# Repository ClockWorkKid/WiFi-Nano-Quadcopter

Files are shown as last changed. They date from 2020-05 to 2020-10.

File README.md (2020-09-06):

# Firefly
Micro quadcopter project (Under Development)

The objective of this project is to build an ultra low cost quadcopter platform for swarm of drones. (Inspired by <a href="https://espcopter.com/">ESP-Copter</a>, <a href="https://www.dronaaviation.com/product/">Pluto Drone</a>, <a href="https://www.ryzerobotics.com/tello">Ryze Tello</a>)

## Table of Contents

- [Build-1](#build-1)
- [TODO List](#todo-list)

## Build-1

The first build of the nano quad uses a 
- 90mm carbon fiber quadrotor frame
- 8520 coreless brushed motors
- 55mm propellers
- 600maH 1S Lipo cell
- WeMos D1 mini module as PPM receiver <a href="https://github.com/DipanshuShukla/ESP-PPM">(ESP-PPM)</a>
- SPRACING F3 EVO brushed flight controller

The reason behind using a ESP module instead of traditional RX modules is that ESP modules are easily programmable with the Arduino IDE, and ESP supports mesh networks which might be useful for swarming. The control interface is a web socket server that can be used from a smartphone browser with touch controls or firefox browser on PC with a traditional Gamepad. 

<figure align="center">
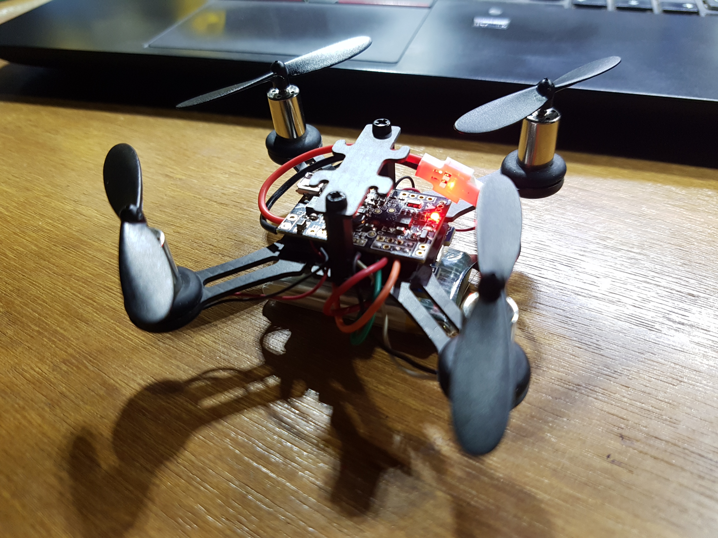
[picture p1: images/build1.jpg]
    
    <figcaption>Build 1</figcaption>
</figure>

Successful flight was achieved on September 2, 2020. For details on the build process, head on to the <a href="Build 1 - WiFi Quadcopter/README.md">Build-1 page</a>

## TODO List
- Port ESP8266 code to ESP32 (Build 1)
- Parameter Tuning (Build 1)
- Enable telemetry (Telemetry Test)
    - https://shipow.github.io/cleanflight-web/docs/telemetry.html
    - https://quadmeup.com/wifi-telemetry-for-cleanflight-with-ez-gui-and-esp8266/
    - https://diydrones.com/profiles/blogs/easy-to-use-frsky-library-for-arduino
    - https://github.com/sgofferj/arduino-frsky
    - https://ardupilot.org/copter/docs/common-frsky-telemetry.html
    - http://ceptimus.co.uk/?p=307
    - https://github.com/betaflight/betaflight/issues/6085
- Customizing Firmware
    - https://github.com/betaflight/betaflight/blob/master/docs/Customized%20Version.md
    - https://www.youtube.com/watch?v=37CP43OogQI
    - https://eecs.blog/compiling-betaflight-cleanflight-firmware-for-your-multirotor/
    - https://eecs.blog/adding-gps-back-to-cleanflight-for-f3-flight-controllers/
    - https://github.com/betaflight/betaflight/wiki/Betaflight-resource-remapping
    - https://www.reddit.com/r/Multicopter/comments/5rtcmn/adding_a_led_beeper_to_the_eachine_brushed_sp/
- Optical Flow Stabilization
    - https://robotzero.one/esp32-camera-module/
    - https://opencv-python-tutroals.readthedocs.io/en/latest/py_tutorials/py_video/py_lucas_kanade/py_lucas_kanade.html
    - https://robotics.stackexchange.com/questions/1844/stabilizing-a-quadcopter-with-optical-flow
- ESP Flight Controller 
    - https://github.com/rtlopez/esp-fc
    - https://github.com/PepeTheFroggie/EspCopter32
    - https://www.youtube.com/playlist?list=PLoPtpxJIxgnYnPrOeGHs3rdhhPgNGIYN5
- Other Tasks
    - https://dronerush.com/drone-gps-10778/
    - https://stackoverflow.com/questions/11217674/how-to-calculate-distance-from-wifi-router-using-signal-strength
    - https://www.kalmanfilter.net/background.html

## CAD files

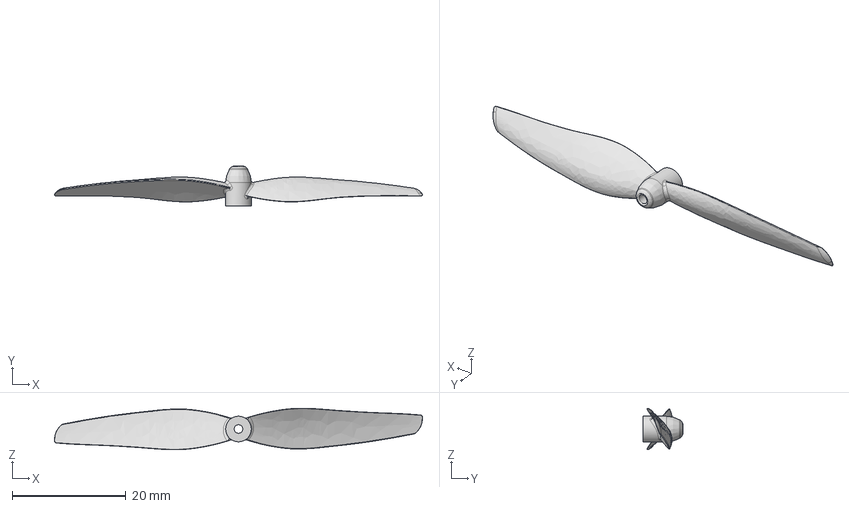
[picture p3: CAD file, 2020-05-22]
Quadcopter CAD Models/65mm-prop-1.snapshot.1/65mm Press-Fit Prop.step
64.7 x 6.95 x 7.27 mm

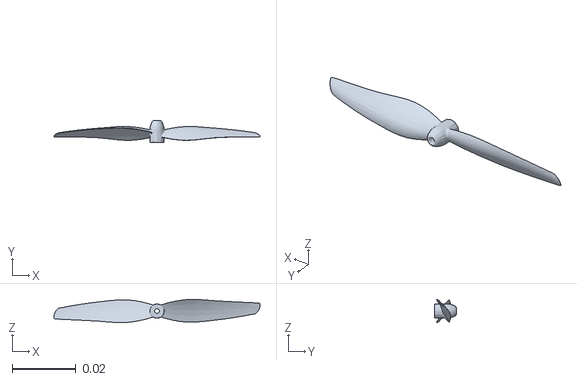
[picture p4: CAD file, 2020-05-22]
Quadcopter CAD Models/65mm-prop-1.snapshot.1/prop_CCW.URDF/meshes/prop_CCW.URDF.STL
0.0646 x 0.00695 x 0.00726

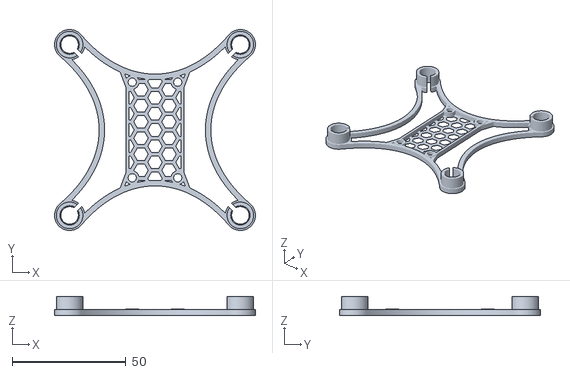
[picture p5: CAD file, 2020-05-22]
Quadcopter CAD Models/Micro_105_FPV_Quadcopter_-_8.5mm_Motors_Micro_Scisky/files/micro105-bottom-v2.stl
88.3 x 88.3 x 8.50

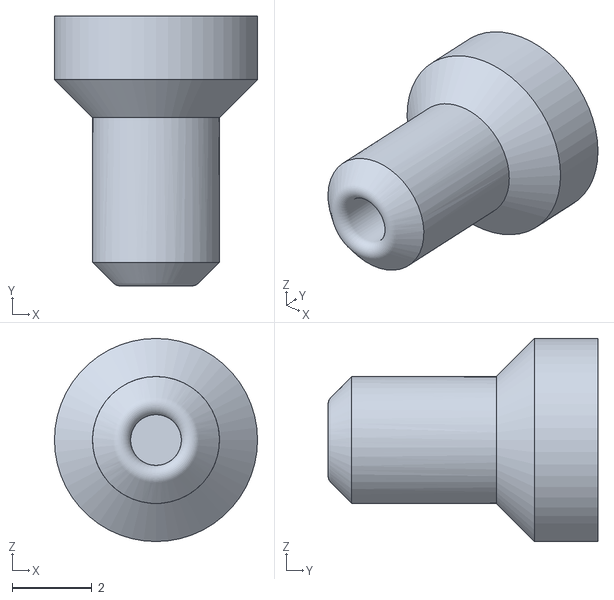
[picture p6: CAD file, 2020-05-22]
Quadcopter CAD Models/Ryze_Tello_Propellers/files/propellor_cap.STL
5.08 x 6.75 x 5.08

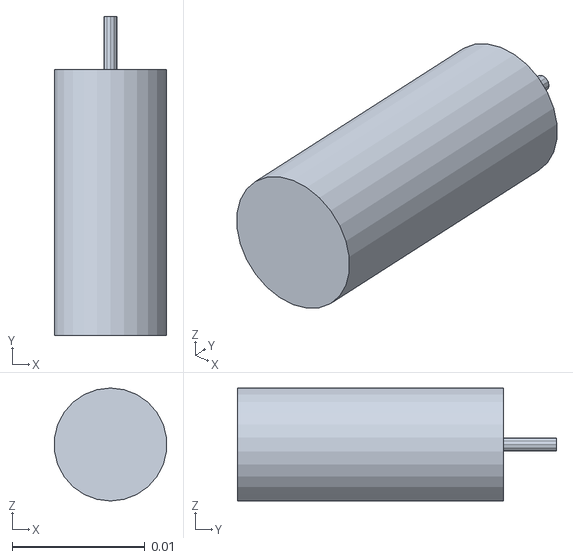
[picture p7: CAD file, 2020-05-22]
Quadcopter CAD Models/Tello-STL-Files/coreless.URDF/meshes/coreless.URDF.STL
0.00844 x 0.024 x 0.0085

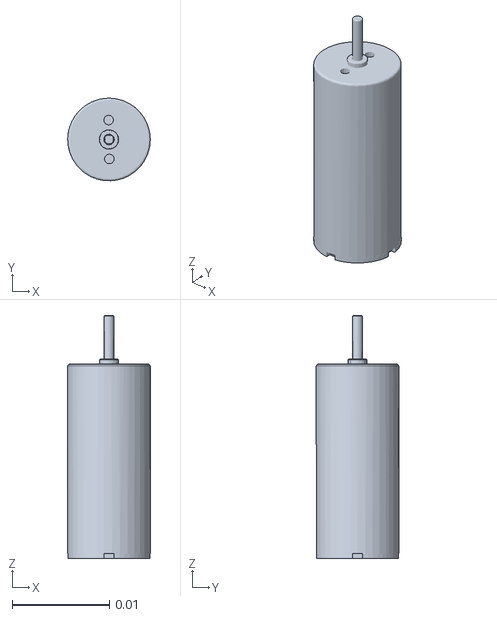
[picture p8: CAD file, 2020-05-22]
Quadcopter CAD Models/Tello-STL-Files/Coreless_Motor.URDF/meshes/Coreless_Motor.URDF.STL
0.0085 x 0.00849 x 0.025

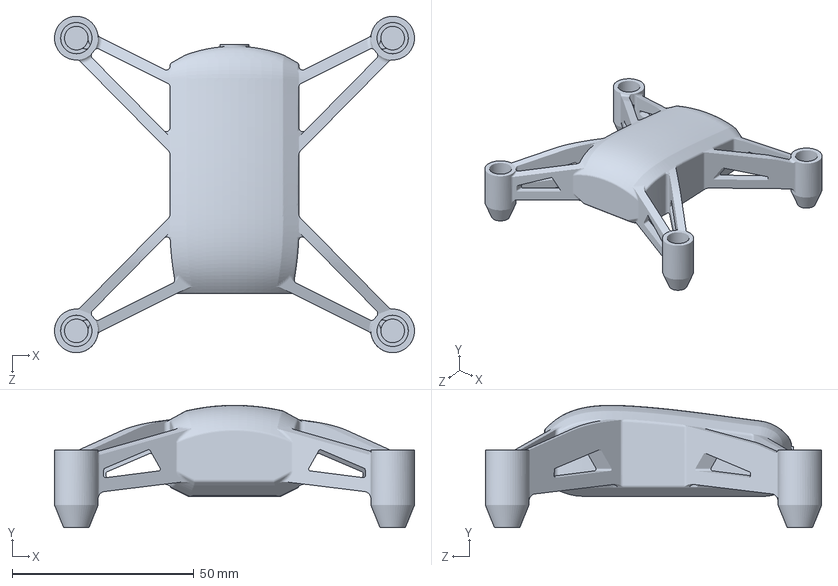
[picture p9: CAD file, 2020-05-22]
Quadcopter CAD Models/Tello-STL-Files/tello_v2.SLDPRT
99.0 x 33.6 x 92.5 mm

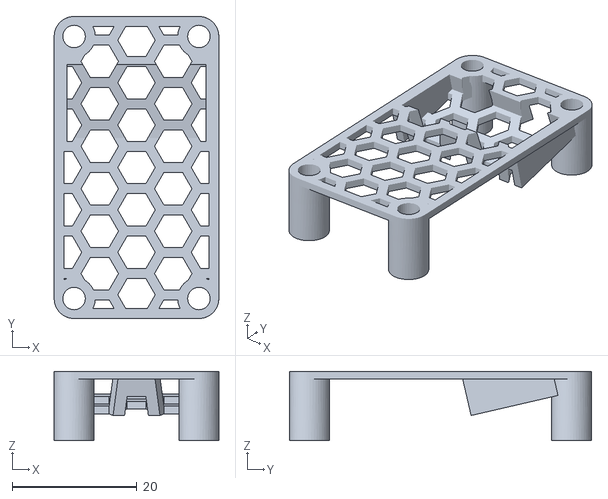
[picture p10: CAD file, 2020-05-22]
Quadcopter CAD Models/Micro_105_FPV_Quadcopter_-_8.5mm_Motors_Micro_Scisky/files/micro105-top-v4-top-camera.stl
26.4 x 48.4 x 11.1

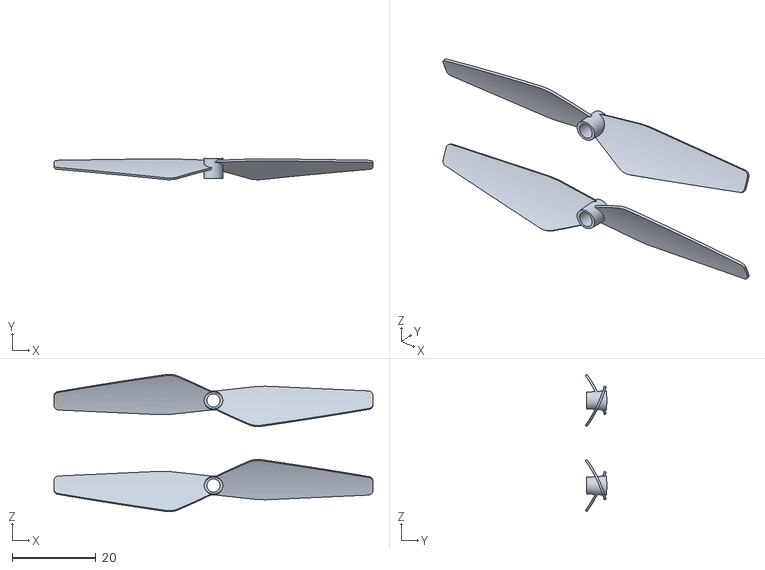
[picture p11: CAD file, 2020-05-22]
Quadcopter CAD Models/Ryze_Tello_Propellers/files/tello_propellors2.STL
76.2 x 5.16 x 32.8

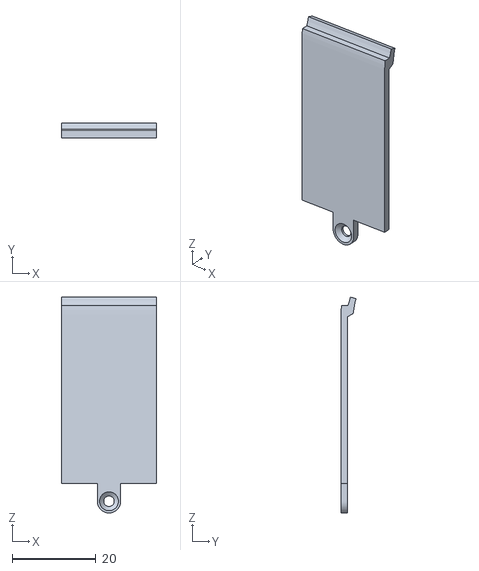
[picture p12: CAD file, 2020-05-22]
Quadcopter CAD Models/Tello-STL-Files/tello_cover.stl
22.6 x 3.59 x 51.6

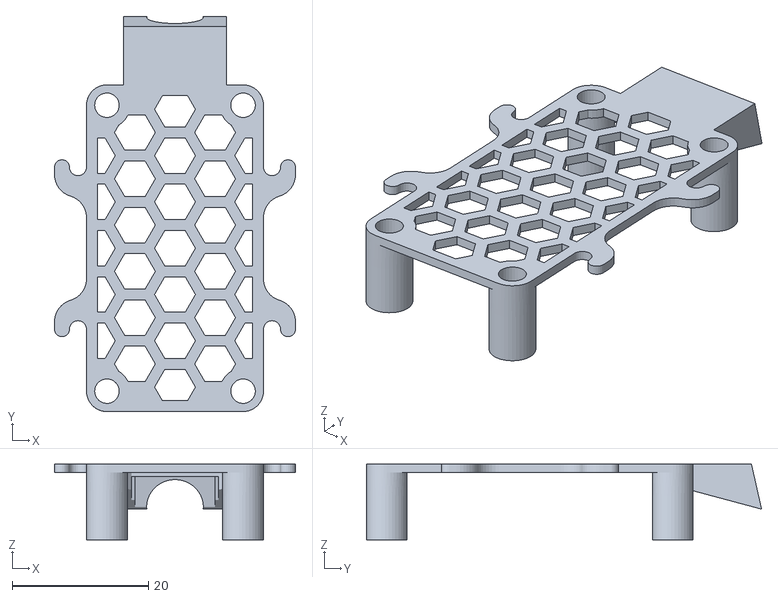
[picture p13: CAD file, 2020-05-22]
Quadcopter CAD Models/Micro_105_FPV_Quadcopter_-_8.5mm_Motors_Micro_Scisky/files/micro105-top-v2.stl
35.4 x 58.0 x 11.1

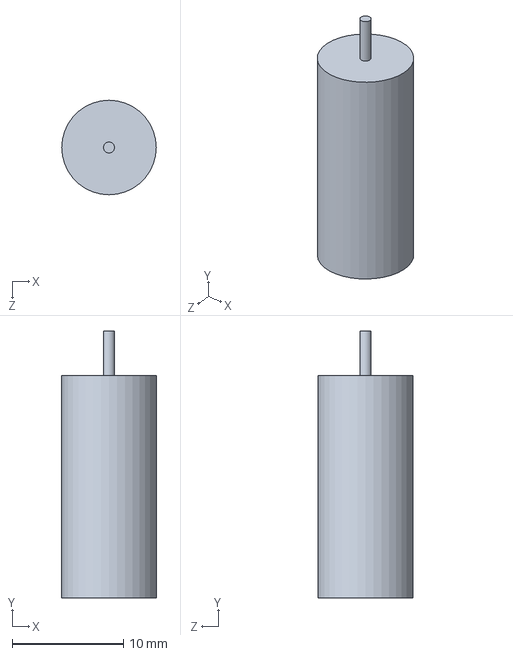
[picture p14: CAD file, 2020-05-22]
Quadcopter CAD Models/Tello-STL-Files/coreless.SLDPRT
8.50 x 24.0 x 8.50 mm

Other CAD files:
Quadcopter CAD Models/Micro_105_FPV_Quadcopter_-_8.5mm_Motors_Micro_Scisky/65mm Press-Fit Prop.SLDPRT
Quadcopter CAD Models/Tello-STL-Files/65mm cw.URDF/meshes/65mm cw.URDF.STL
Quadcopter CAD Models/Micro_105_FPV_Quadcopter_-_8.5mm_Motors_Micro_Scisky/65mm cw.SLDPRT
Quadcopter CAD Models/Tello Mesh Files/65mm cw.STL
Quadcopter CAD Models/Micro_105_FPV_Quadcopter_-_8.5mm_Motors_Micro_Scisky/files/micro105-bottom-v1.stl
Quadcopter CAD Models/Micro_105_FPV_Quadcopter_-_8.5mm_Motors_Micro_Scisky/files/micro105-bottom-v3.stl
Quadcopter CAD Models/Micro_105_FPV_Quadcopter_-_8.5mm_Motors_Micro_Scisky/files/micro105-bottom-v4-7mm-bottom-battery.stl
Quadcopter CAD Models/Micro_105_FPV_Quadcopter_-_8.5mm_Motors_Micro_Scisky/files/micro105-bottom-v4-bottom-battery.stl
Quadcopter CAD Models/Micro_105_FPV_Quadcopter_-_8.5mm_Motors_Micro_Scisky/files/micro105-top-v1.stl
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

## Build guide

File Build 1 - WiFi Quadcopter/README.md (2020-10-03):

# Firefly Build 1
Here is the detailed construction process of the first successful build of project Firefly:

## Contents

- [Materials](#materials)
- [Circuit Connections](#circuit-connections)
- [Flight Controller Configuration](#flight-controller-configuration)
- [ESP8266 Configuration](#esp8266-configuration)
- [Finalizing Setup](#finalizing-setup)

## Materials

- 90mm carbon fibre quadcopter frame (Any frame supporting **8520 motors** should work)
- 8520 Coreless motors 2 pairs (cw motor has **red+black/blue** wire, ccw motor has **white+black** wire)
- 55mm Propeller 2 pairs (Clockwise + Counterclockwise)
- F3 Evo Brushed Flight Controller (Any **brushed** flight controller should do)
- 600mAH 1S 3.7V lipo cell
- WeMos D1 mini ESP8266 WiFi Module (Any ESP8266 should work)

<figure align="center">
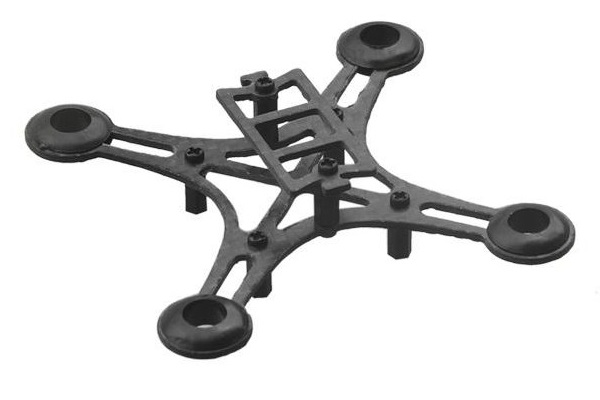
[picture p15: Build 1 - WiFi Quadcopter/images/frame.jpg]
    
    <figcaption>Frame</figcaption>
</figure>

<figure align="center">
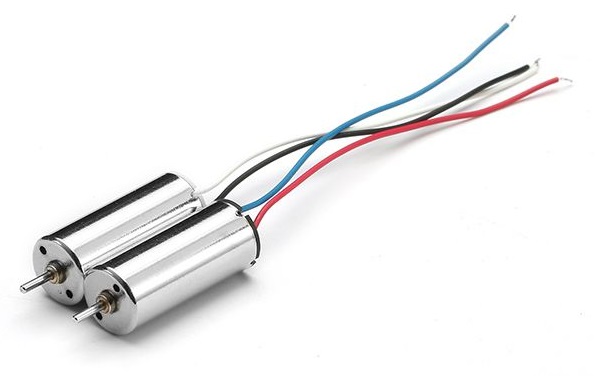
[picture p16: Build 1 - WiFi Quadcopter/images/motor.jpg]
    
    <figcaption>Motor</figcaption>
</figure>

<figure align="center">
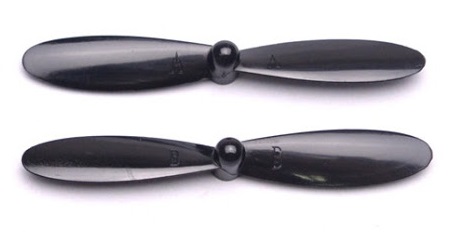
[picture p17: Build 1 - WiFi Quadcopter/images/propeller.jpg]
    
    <figcaption>Propeller</figcaption>
</figure>

<figure align="center">
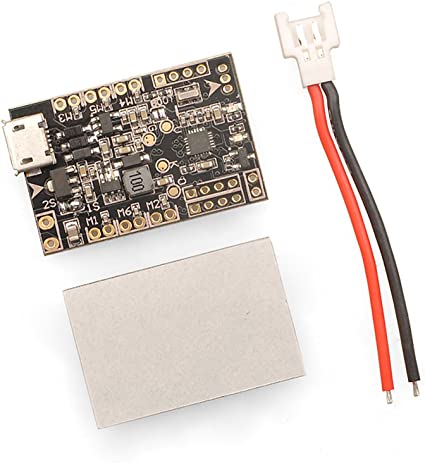
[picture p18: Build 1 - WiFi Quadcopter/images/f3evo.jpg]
    
    <figcaption>Flight Controller</figcaption>
</figure>

<figure align="center">
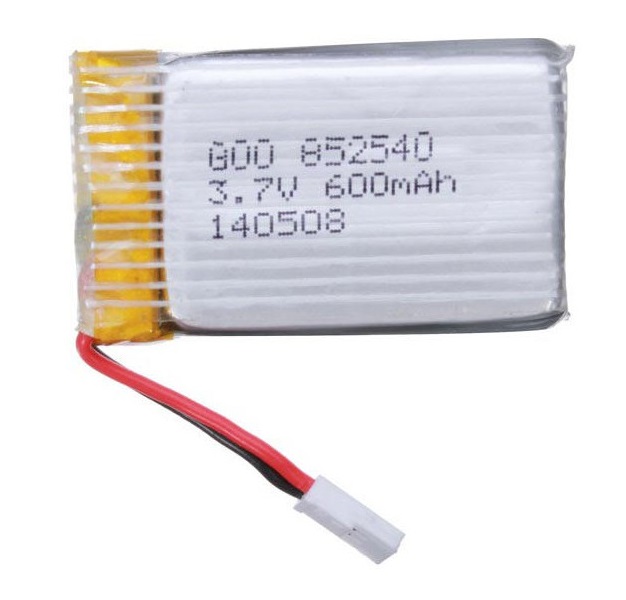
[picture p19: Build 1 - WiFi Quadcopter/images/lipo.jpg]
    
    <figcaption>Lipo Cell</figcaption>
</figure>

<figure align="center">
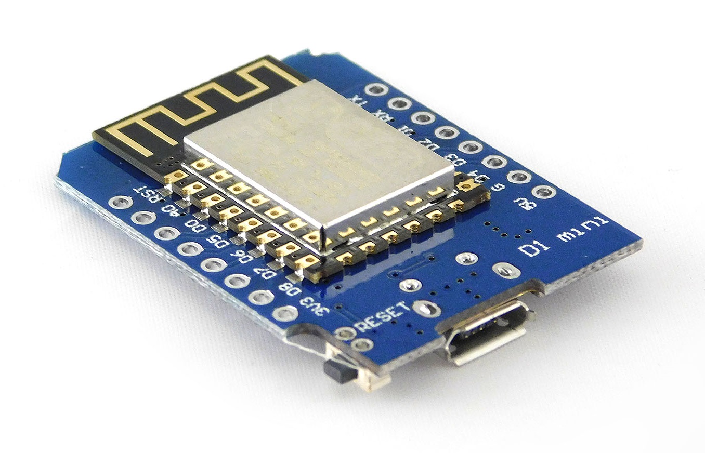
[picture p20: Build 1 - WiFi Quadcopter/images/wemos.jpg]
    
    <figcaption>Wifi Module</figcaption>
</figure>

## Circuit Connections

<figure align="center">
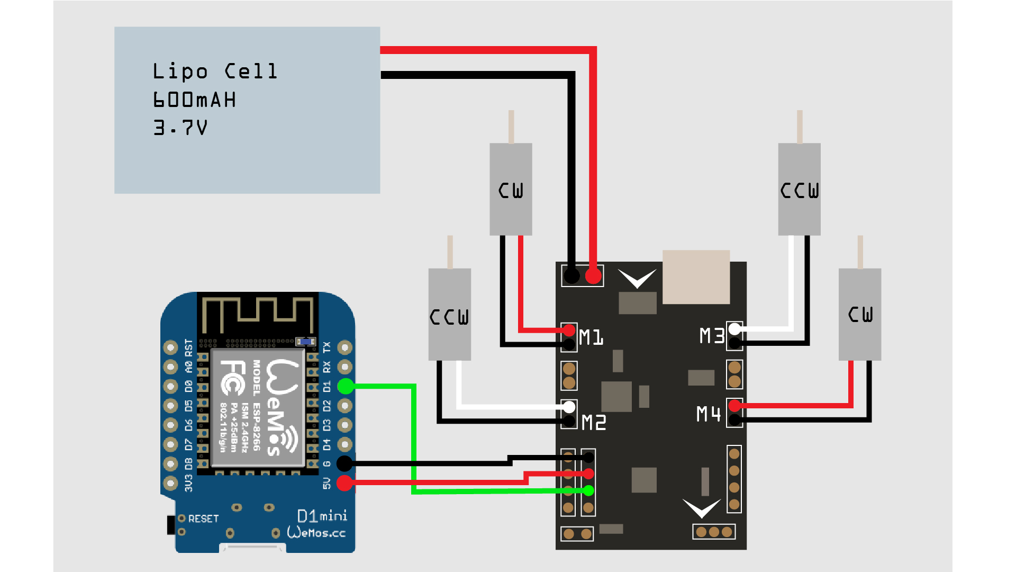
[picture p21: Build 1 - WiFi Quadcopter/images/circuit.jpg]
    
    <figcaption>Overall Circuit Diagram</figcaption>
</figure>

<figure align="center">
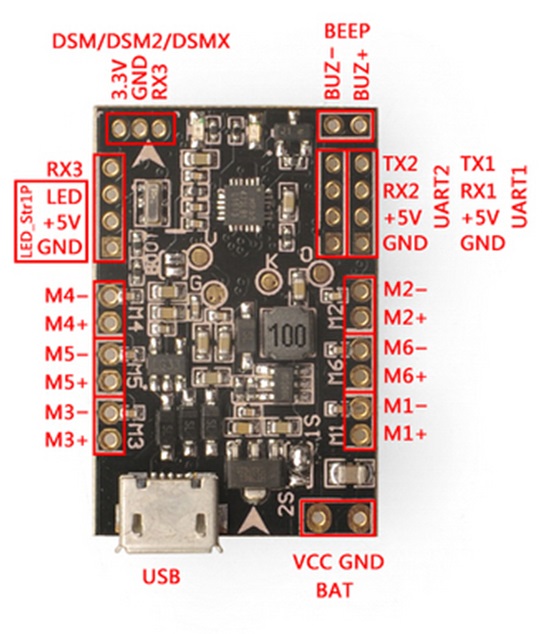
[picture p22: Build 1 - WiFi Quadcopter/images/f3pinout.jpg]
    
    <figcaption>Flight Controller pinout diagram</figcaption>
</figure>

### Step 1: Connecting Battery Connector to Flight Controller
Watch for the polarity of the battery connector cable while connecting it to the power pins of the flight controller. A reverse battery connection can fry your controller. If you are using a 1S battery, make sure the 1S jumper is soldered together as the flight controller supports both 1S and 2S power supplies in separate modes (The connection pads are near the battery connector)

<figure align="center">
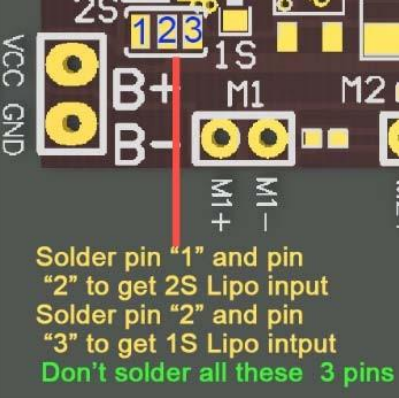
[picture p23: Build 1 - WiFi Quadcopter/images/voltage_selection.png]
    
    <figcaption>Voltage Selection Jumper</figcaption>
</figure>
<figure align="center">
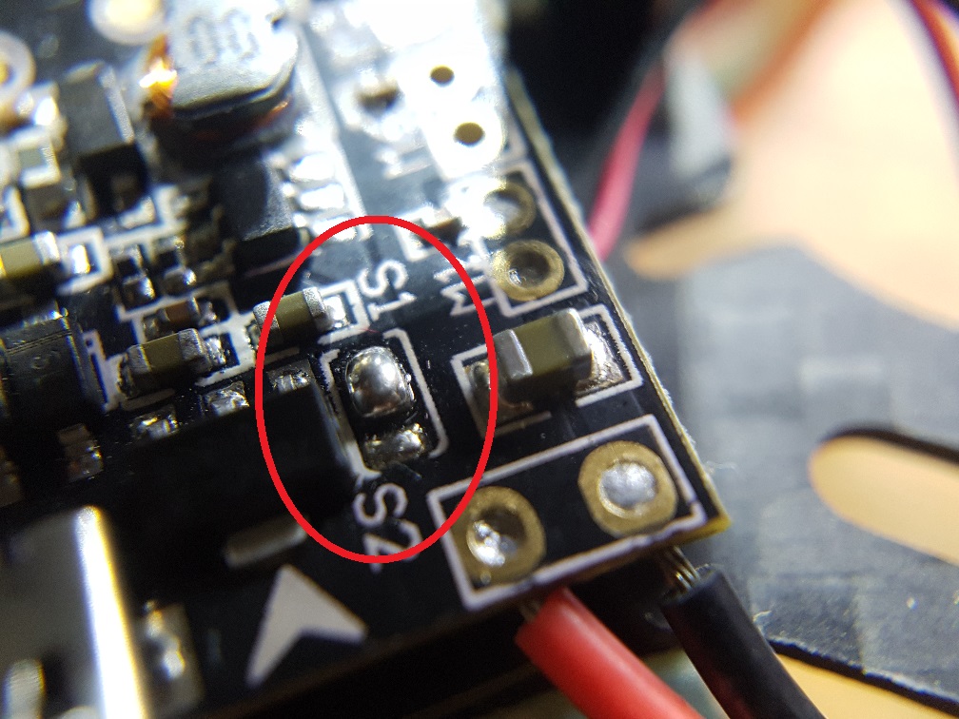
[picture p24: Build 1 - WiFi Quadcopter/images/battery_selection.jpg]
    
    <figcaption>Voltage Selection Jumper</figcaption>
</figure>

### Step 2: Connecting Motors to Flight Controller
Red+Blue or Red+Black motors are designed to rotate clockwise (along with a clockwise propeller) and White+Black motors are designed for counter-clockwise rotation. For all motors, **Black means Negative** and the other colored wire is positive. F3 Evo brushed flight controller has 6 motor connections available (4 in some variants). We will connect clockwise motors (Red+Black) on connections M1, M4 and counter-clockwise motors (White+Black) on M2, M3. Watch out for the polarity of the connections, you can find them on the pinout diagram of the flight controller.

If you happen to have four motors of the same type (clockwise), then you can just flip the connections for two of the motors to get reverse rotation, althought this is generally not recommended since these tiny brushed motors are usually coiled to efficiently run in one direction. Reversing the polarity makes the motor die out faster than expected lifetime of about 7 hours of 100 flights.

### Step 3: Connecting WeMos D1 mini to Flight Controller
F3 evo brushed flight controller has 3 UART ports, you can find the details on the <a href="https://www.unmannedtech.co.uk/uploads/6/7/0/2/6702064/f3_evo_fc_manual.pdf">user manual</a>

| Serial Port | Used For |
| --- |:---:|
| UART1 | GPS/OSD |
| UART2 | PPM/SBUS receiver input |
| UART3 | GPS/Telemetry module |

We will be using **UART2** as the ESP8266 module will be used as a PPM receiver over WiFi.

<figure align="center">
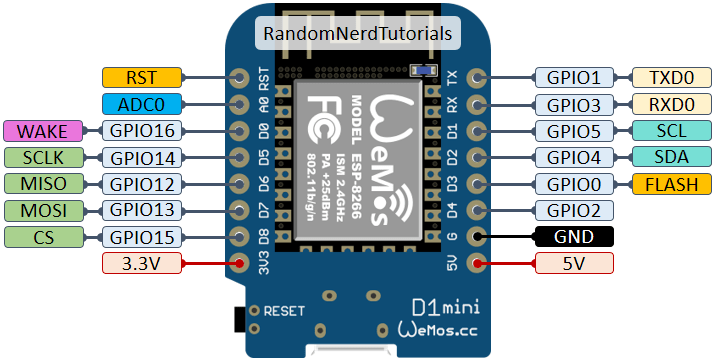
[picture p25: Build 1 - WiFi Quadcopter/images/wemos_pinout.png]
    
    <figcaption>WeMos D1 Mini Pinout</figcaption>
</figure>

The code has been configured to be using GPIO5 pin on the ESP8266 module as the PPM output, which is pin D1 on WeMos D1 mini.

| Flight Controller | ESP8266 pin | WeMos D1 Mini |
| --- |:---:|:---:|
| UART2 RX | GPIO5 | D1 |
| UART2 V+| +5V input | +5V input |
| UART2 GND | GND | GND |

In this manner, the flight controller will power the ESP8266 module when connected to USB/Battery.

### Step 4 (Optional): Connect Beeper/LED

F3EVO brushed flight controller by default does not have an on board beeper. Beepers give important feedback on voltage level, arming-disarming, in flight errors, failsafe etc. Thus you might want to consider connecting a beeper to the flight controller beeper pins. I don't like unnecessary sounds, so I connected an LED to the port instead (use blue LEDs, other colored LEDs have low forward voltage and might easily die without current limiting resistors)

<figure align="center">
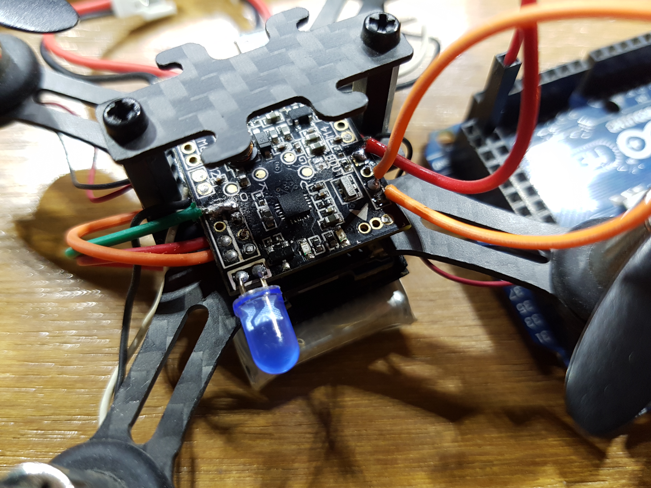
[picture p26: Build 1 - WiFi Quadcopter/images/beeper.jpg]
     <figcaption>Beeper LED</figcaption>
</figure>

## ESP8266 Configuration

### Step 1: Setting up Arduino IDE
ESP8266 module can be easily programmed from the widely used Arduino IDE.

- Download and install the latest <a href="https://www.arduino.cc/en/main/software">Arduino IDE</a>

- We will need to install dependencies for ESP8266 modules in the IDE. In the Arduino IDE, go to **Files > Preferences**. Here in the **Additional Board Manager URLs** field, paste the following line and click **ok**
    ```
    https://arduino.esp8266.com/stable/package_esp8266com_index.json
    ```
    Now go to **Tools > Board > Boards Manager**. The new boards index will load. Type ESP8266 in the search bar, and the ESP8266 library should show up. Install it. (Sometimes the url link does not work correctly, you might need to find alternate links to the library.)

    For more details, go to the <a href="https://github.com/esp8266/Arduino">ESP8266 github page</a>

### Step 2: Setting up drivers

WeMos D1 mini module uses the CH340 usb to serial driver IC for programming the onboard microcontroller unit. Windows by default does not recognize this, so you will need to install the driver from <a href="CH34x_Install_Windows_v3_4.EXE">here</a>.

After the driver has been installed, connect the ESP8266 module to the computer, and from Arduino IDE, it should be available under **Tools > Port**

### Step 3: Installing websockets library

The WiFi PPM code uses the esp websockets library.
- Download the <a href="arduinoWebSockets.zip">zip file</a>
- From a blank Arduino sketch, go to **Sketch > Include Library > Include .ZIP Library** and from there, select the downloaded zip file. The library will be imported in the IDE.

### Step 4: Uploading the Sketch

The WiFi inerface of the quadcopter uses WebSockets protocol for communicating using a browser window.

- The sketch used in this build is originally copied from another <a href="https://github.com/DipanshuShukla/ESP-PPM">github repo</a>. Download the entire <a href="ESP_PPM">sketch folder</a> and open the ESP_PPM.ino file from Arduino IDE. You should be able to upload the original sketch to the ESP Board without problem. You can modify the default WiFi AP name and password from lines 22-23

    ```
    const char *ssid = "Firefly_Test";
    const char *password = "123456789";
    ```

- After uploading, from your smartphone, you will find the hotspot on your phone WiFi. Connect to the hotspot and from smartphone browser, go to url 192.168.4.1

- The browser window will load a page with two joysticks. These are used to send control commands to the quadcopter.

- A joystick can be connected with the computer to send controls to the ESP8266 module too using firefox browser from PC.

<figure align="center">
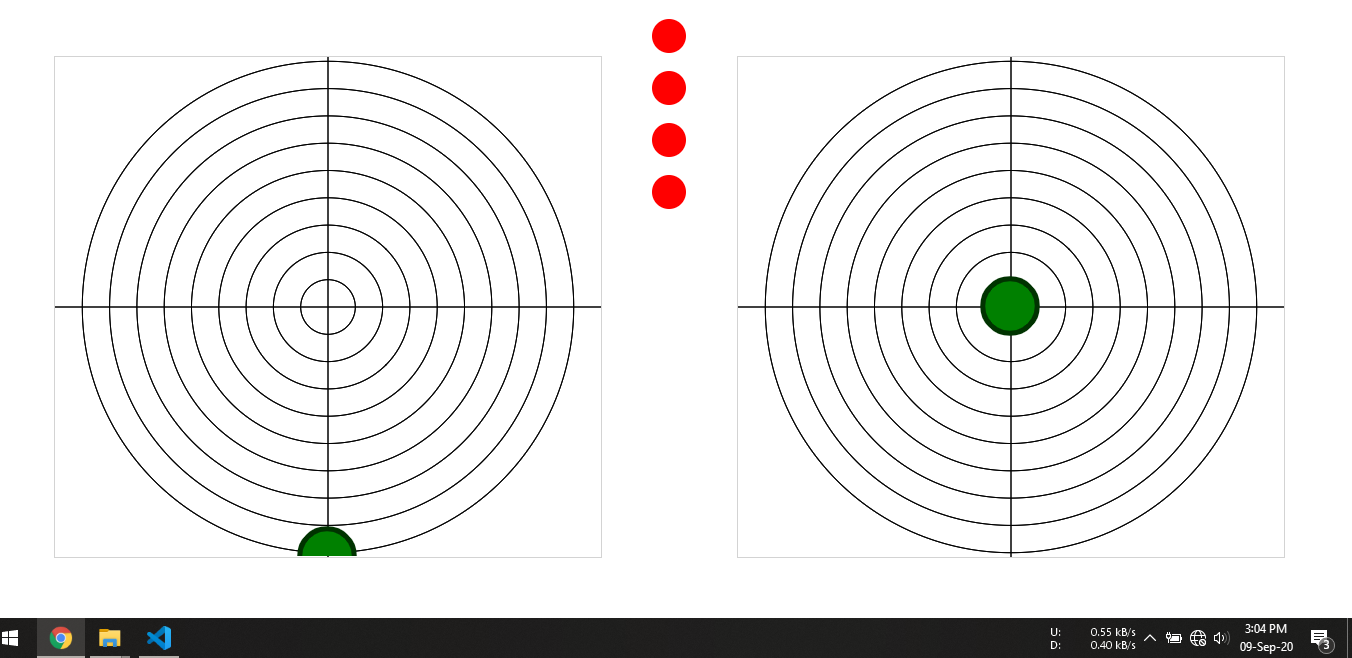
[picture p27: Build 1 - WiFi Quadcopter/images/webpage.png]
     <figcaption>Controller Browser Page</figcaption>
</figure>

## Flight Controller Configuration

<a href="https://github.com/betaflight/betaflight">Betaflight</a> and <a href="https://github.com/cleanflight/cleanflight">Cleanflight</a> are the two most widely used flight controller firmware and configurators in the realm of RC quads and racing drones. Betaflight is more used these days, althought the two are really similar (Betaflight originally came from cleanflight). I have tested both of them on the model, and ran into a few issues with betaflight. So in this build I will be using only Cleanflight for configuring the micro quad. (The processes explained here should be similar for betaflight too)

### Step 1: Cleanflight Chrome App

Cleanflight runs as an application run from Chrome browser. Google Cleanflight Chrome App and it should take you to the installation page. Add the extension and you should be done. The configurator can be launched from chrome apps.

<figure align="center">
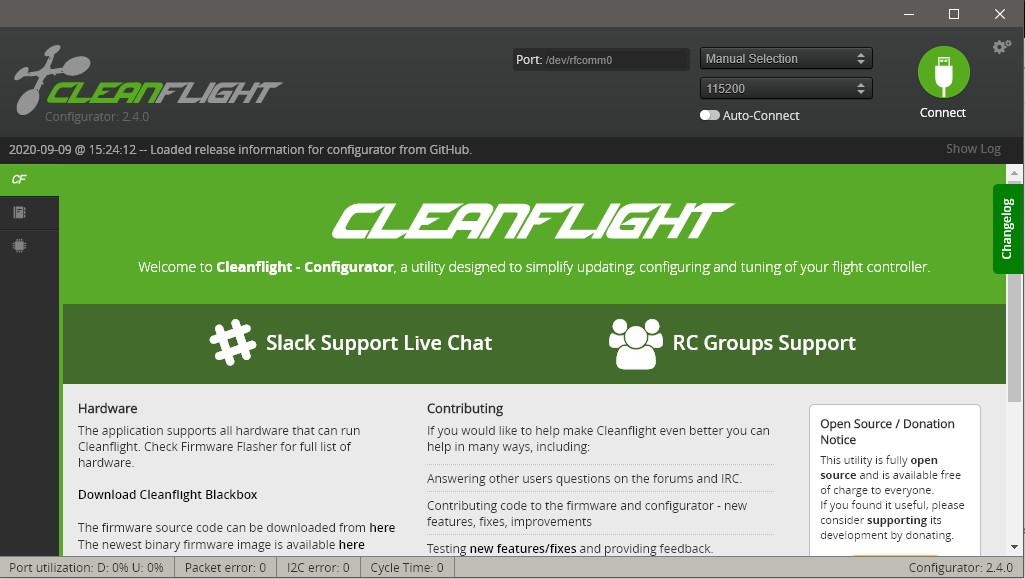
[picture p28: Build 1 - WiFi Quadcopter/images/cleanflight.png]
     <figcaption>Cleanflight Start Page</figcaption>
</figure>

### Step 2: Install Flight Controller Driver with Zadig

- The brushed controller used in this build has an STM32F3 chip which has a built in port for connecting to USB for firmware flashing. However on Windows machine, a virtual port driver has to be installed for accessing this. Download the <a href="zadig-2.4.exe">Zadig</a> tool.

- To install the bootloader, the Flight Controller board needs to be in Boot mode. Most flight controller boards have a boot button that can be held while connecting to PC, but F3EVO brushed controller has the boot pads open on the board. Do not solder the boot pads together for boot mode, because if you do so, you will need to frequently solder and desolder the pads for changing Flight controller firmware.

    Use something metallic to touch the two boot pads together, and connect the board to PC. If the contact was okay, you should see that only the RED indicator LED is glowing, meaning that the board is in bootloader mode
    <figure align="center">
         <figcaption>Bootloader Mode</figcaption>
    </figure>
    If the blue LED is also flashing, then the board is in configuration mode - disconnect it and try the process again.
    <figure align="center">
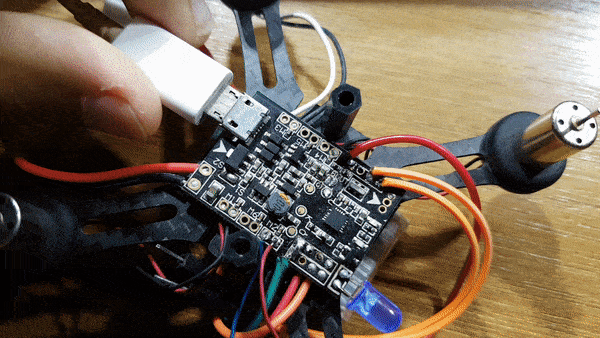
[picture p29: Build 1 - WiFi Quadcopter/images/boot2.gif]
         <figcaption>Configuration Mode</figcaption>
    </figure>

- With the board in bootloader mode, open Zadig, choose **Options > List All Devices**
    <figure align="center">
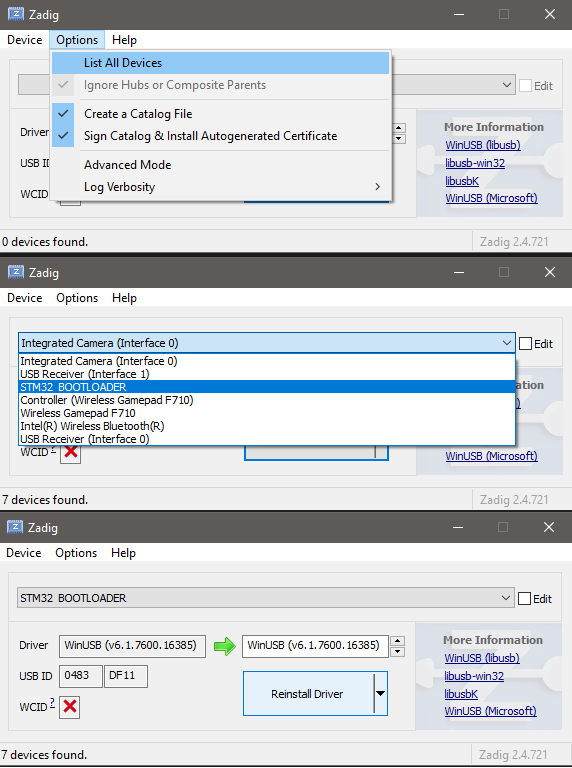
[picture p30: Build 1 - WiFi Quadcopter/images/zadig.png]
         <figcaption>Zadig Driver</figcaption>
    </figure>
- Select STM32 Bootloader, WinUSB. Click **replace driver** or **install driver**. It should be done.

### Step 3: Flash Cleanflight Firmware

- Open Cleanflight configurator from Chrome apps, connect the Flight Controller Board in the bootloader mode. When you connect the board, you should see the device is available as **DFU**. Do not try to connect from here.
    <figure align="center">
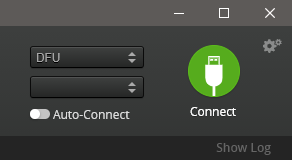
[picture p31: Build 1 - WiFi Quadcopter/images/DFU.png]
         <figcaption>DFU Mode</figcaption>
    </figure>

- Go to the firmware flasher tab. The configurator should automatically detect your board. If it doesnt, manually select the board and firmware. At the time of writing, CLFL 2.5.0 was used as flight controller firmware. After that, click on **Load Firmware(Online)** and a hex file will be downloaded. After that, click **Flash Firmware**, it might take some time to flash.
    <figure align="center">
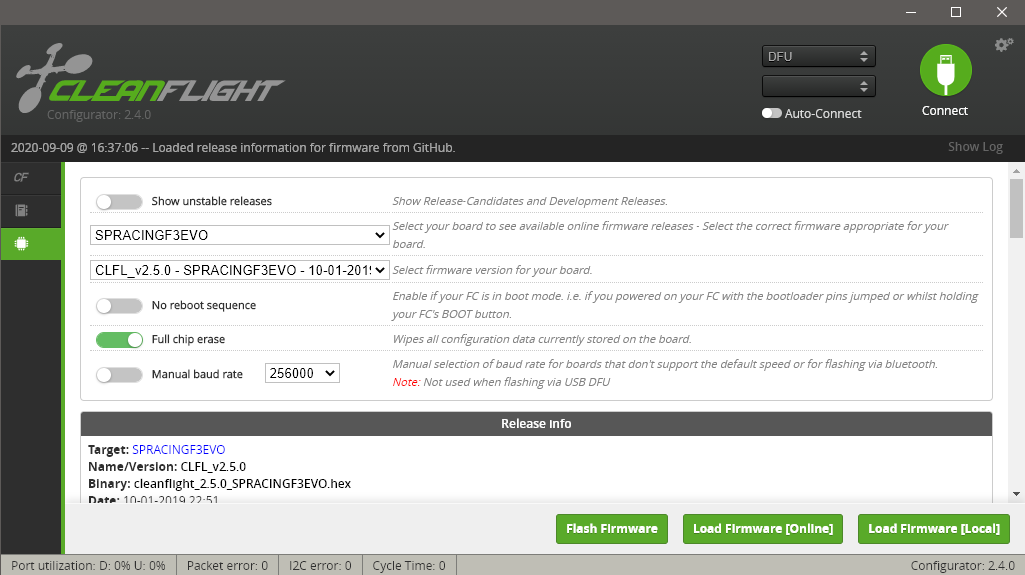
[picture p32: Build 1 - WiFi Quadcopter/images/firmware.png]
         <figcaption>DFU Mode</figcaption>
    </figure>

After flashing, the configurator will go to the start page, and a serial port will be available for connecting. You can click on connect to start configurating the flight controller now.
    <figure align="center">
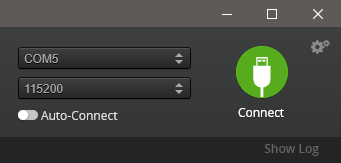
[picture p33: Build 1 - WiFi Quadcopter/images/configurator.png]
         <figcaption>Configurator Mode</figcaption>
    </figure>

If the steps did not make sense, you can watch <a href="https://www.youtube.com/watch?v=Krv-CMSfb_M">this video on flashing using betaflight</a>

## Finalizing Setup

## References
- <a href="https://www.instructables.com/id/Build-a-WiFi-Enabled-Micro-quadrotor/">WiFi enabled micro quadrotor</a>
- <a href="https://www.instructables.com/id/Long-Range-Wifi-PPM-MSP/">Long Range WiFi PPM instructables</a>
- <a href="https://community.micro-motor-warehouse.com/t/banggood-eachine-sp-racing-f3-evo-based-brushed-fc-set-up-guide-for-spektrum-sat-receivers/2574">F3 Evo setup guide</a>
- <a href="https://blog.dronetrest.com/setting-up-flight-modes-in-cleanflight-betaflight/">Betaflight flight modes</a>

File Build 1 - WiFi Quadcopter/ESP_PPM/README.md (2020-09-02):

# IoT based ESP wifi PPM reciever for Drones(and other applications)

## Overview

IOT based project for ESP8266 module to be used as an ppm reciever (no controller app needed) for a drone flight controller.

The ESP*12E ESP8266 WiFi Module is a self contained SOC with integrated TCP/IP protocol stack that can give any microcontroller access to your WiFi network. The ESP8266 is capable of either hosting an application or offloading all Wi*Fi networking functions from another application processor.

This gives us an advantage of not needing an external application to send and recieve commands. The program starts a wifi access point with a HTML 5 website to control the PPM signal. The PPM signal is generated by interrupt.

Thanks to HTML5 you can control your RC device with any smart phone without any app. You can also connect to the website with a PC and use a joystick for controlling. At the moment this works only in Firefox.

## Getting Started

These instructions will get you a copy of the project up and running on your ESP8266  for development and testing purposes.

### Part List

* ESP8266: Any module should work. I used the ESP-12E module.

* a 3,3V USB to Serial converter for uploading the scetch the first time. (I used a NodeMCU Amica board).

* a 3,3V voltage regulator: The ESP8266 needs 3,3V. Any voltage above 3,6V will kill the device. It can also drop about 200mA peak current. If you don´t have a strong enough 3,3V supply at your RC model you need an additional voltage regulator.

* a PC with Arduino IDE

* ESP8266 support for Arduino IDE. Follow [these instructions](https://learn.sparkfun.com/tutorials/esp8266-thing-hookup-guide/installing-the-esp8266-arduino-addon).

* Websocket library for Arduino: https://github.com/Links2004/arduinoWebSockets

* Maybe a 3,3V/5V level shifter if your PPM decoder doesn´t support 3,3V inputs. For most Drone flight controllers you don´t need this.

* The WifiPPM scetch: Download file 

* A smart phone or a PC with a joystick and Firefox

### Setting up the Electronics and uploading the Code

<p align="center">
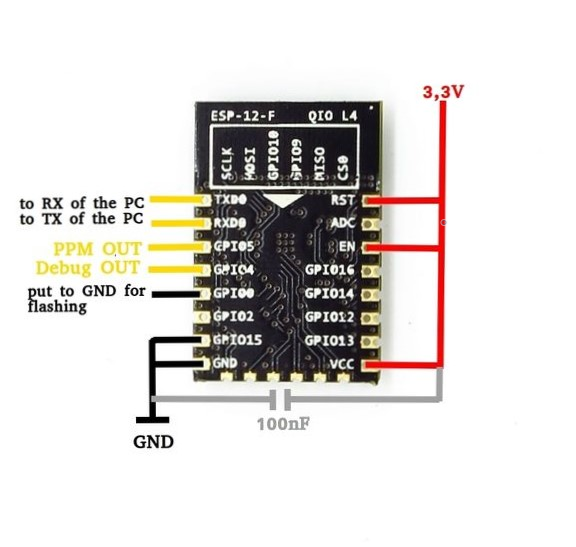
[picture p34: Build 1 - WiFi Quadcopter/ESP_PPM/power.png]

</p>

1. First you need to set the power connections to the ESP8266 module. You can see the wiring in the picture. Make the following connections:

	* RST, EN and VCC to 3,3V

	* GPIO15 and GND to GND

	* Put a small capacitor between VCC and GND (about 100 nF)

	* TXD to RXD of your USB2Serial device

	* RXD to TXD of your USB2Serial device

	* Put GPIO0 to GND while powerup to enter the flash mode.

2. After you have installed the Arduino IDE, the ESP8266 support and the websocket library open the sketch. Hold GIO0 to GND while powering up the ESP8266 to enter the flash mode. Now you can upload the sketch.

3. After you have uploaded the sketch, the controller will reset. You should find a WIFI Access Point named WifiPPM. If this is OK you can power down the chip and disconnect the TXD, RXD and GPIO0 wires. In the future you can update the program over OTA. To do so connect to the Access Point and go to "192.168.1.4/update" in your web browser.

```diff
- NOTE: YOU MAY WANT TO CHANGE THE ACCESS POINT NAME AND PASSWORD IN THE CODE BEFORE UPLOADING THE SKETCH.
```

### Connecting to the Website

Now you can connect GPIO5 to the PPM input of your flight controller or whatever you use to decode the PPM signal.

  * After powering up the module you can connect to the Access Point "WifiPPM". There is no password. Open the address 192.168.4.1 in your browser.

  * You will see the site of the first picture. On a touch device you can control the sticks with your touch screen.

  * If you open the site with a PC you must use Firefox. As soon as you connect a joystick, the site will change to the one you can see at the second picture. You can control the sticks with your joystick.

### Setting Up Betaflight

I use the WifiPPM controller for my quadcopter with Betaflight. I explain now how to set it up.

  * Connect your flight controller to the PC

  * open Betaflight

  * connect to the flight controller

  * go to Receiver tab

  * type RTAE1234 into the channel map field

  * change the "Stick Low Threshold" to 1020, the "Stick Center" to 1500 and the "Stick High Threshold" to 1980

  * save the changes

  * open the wifiPPM website with your mobile phone and test if the adjustment is OK

Thats it. You are done. Now you can fly with your mobile phone without any additional app.

## Authors

* **Dipanshu Shukla** - *Initial work* - [Github page](https://github.com/DipanshuShukla)

## License

This project is licensed under the MIT License - see the [LICENSE.md](https://github.com/DipanshuShukla/ESP-PPM/blob/master/LICENSE) file for details

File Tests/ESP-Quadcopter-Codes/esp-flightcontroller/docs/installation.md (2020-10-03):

# Installation instruction

The best way to flash your device is to install Atom IDE with platformio extension.

1. Install Atom IDE https://atom.io/
2. Install PlatformIO extension http://docs.platformio.org/en/latest/ide/atom.html#installation
3. Install GIT client (optional) https://git-scm.com/download/win
4. Clone or download repository into projects folder with command `git clone https://github.com/rtlopez/esp-fc.git`
5. Open project in Atom IDE
6. To build binary file press F7 and pick option 'PIO Build(d1_mini).
7. To upload, connect device first, then press F7 and choose 'PIO Upload(d1_mini)' http://docs.platformio.org/en/latest/ide/atom.html#building-uploading-targets

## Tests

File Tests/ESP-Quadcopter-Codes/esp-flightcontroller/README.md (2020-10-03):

# ESP-FC Flight Controller
The mini, DIY, ~$5 cost, ESP8266 based, high performance flight controller.

## Features
* Frames (Quad X)
* Betaflight contiguration tool compatible
* Receiver protocol (8 channel PPM)
* ESC protocols (PWM, Oneshot125, Oneshot42, Multishot, Brushed, Dshot150, Dshot300, Dshot600)
* Configurable Gyro Filters (LPF, Notch, dTerm)
* Blackbox recording (OpenLog serial)
* In flight PID Tuning
* Flight modes (ACRO, ANGLE, AIRMODE, ARM)
* Up to 2kHz gyro/loop in acro, 1kHz with accelerometer (level)
* MSP protocol interface
* Cli interface
* Resorce mapping
* Buzzer
* Lipo voltage monitor
* Failsafe

## Requirements
Hardware:
* Wemos D1 Mini board (D1 Mini Lite too, ESP-12 for experienced users)
* MPU6050 I2C gyro (GY-88, GY-91, GY-521 or similar)
* PDB with 5V BEC
* Buzzer and some electronic components (optionally).

Software:
* [Betaflight Configurator](https://github.com/betaflight/betaflight-configurator/releases) (v10.7)
* [CH340 usb-serial converter driver](https://sparks.gogo.co.nz/ch340.html)
* [Espressif Flash Download Tools](https://www.espressif.com/en/support/download/other-tools)

## Flashing
**Windows:** download and unzip [Espressif Flash Download Tools](https://www.espressif.com/en/support/download/other-tools)

ESP-FC Flashing

## Configuration
The rule of thumb is if you cannot change specific option in Betaflight Configurator, that means it is not supported.

## Wiring diagram
ESP-FC Wemos D1 mini wiring diagram

## Issues
You can report issues using Github [tracker](https://github.com/rtlopez/esp-fc/issues)

## Development
* Visual Studio Code
* [PlatformIO](https://platformio.org/install/ide?install=vscode)
* Git

## Todo
* Update documentation
* Mixers: Quad+, Bicopter, Tricopter, Helicopter, Custom and more
* Balancing robot
* Serial Rx (SBUS, IBUS)
* Baro (MS5611, BMP280)
* Magnetometer (HMC5883, AK8963)
* GPS navigation
* ESP32 board
* ESP32 SPI Gyro (MPU9250)

## Licence
This project is distributed under MIT Licence. Bear in mind that:

THE SOFTWARE IS PROVIDED "AS IS", WITHOUT WARRANTY OF ANY KIND, EXPRESS OR
IMPLIED, INCLUDING BUT NOT LIMITED TO THE WARRANTIES OF MERCHANTABILITY,
FITNESS FOR A PARTICULAR PURPOSE AND NONINFRINGEMENT. IN NO EVENT SHALL THE
AUTHORS OR COPYRIGHT HOLDERS BE LIABLE FOR ANY CLAIM, DAMAGES OR OTHER
LIABILITY, WHETHER IN AN ACTION OF CONTRACT, TORT OR OTHERWISE, ARISING FROM,
OUT OF OR IN CONNECTION WITH THE SOFTWARE OR THE USE OR OTHER DEALINGS IN THE
SOFTWARE.

## Donations
If you like this project and you want it to be still developed, you can support me a little.

* BTC: 1Lopez7yPtbyjfLGe892JfheDFJMMt43tW
* LTC: LV3G3sJxz9AYpDMYUp8e1LCmerFYxVY3ak

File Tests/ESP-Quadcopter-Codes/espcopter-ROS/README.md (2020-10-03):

# A ROS package to communicate espcopters using wifi.

This repo contains the firmware of ESPcopter that enables this drone to communicate with ROS.

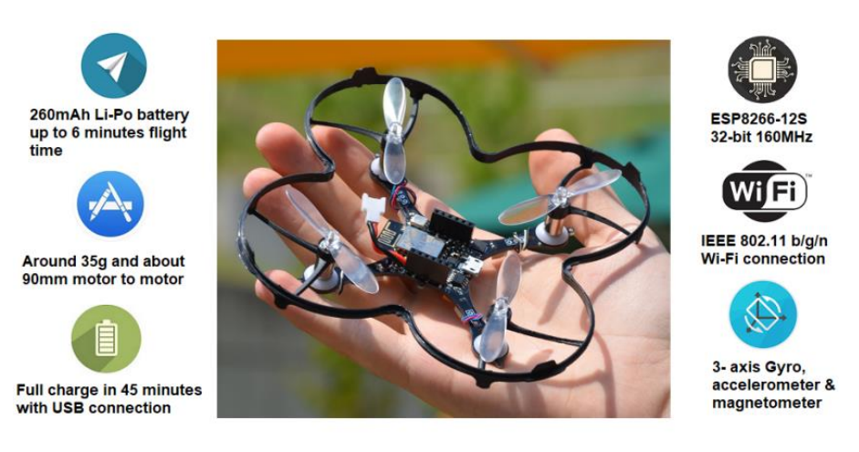
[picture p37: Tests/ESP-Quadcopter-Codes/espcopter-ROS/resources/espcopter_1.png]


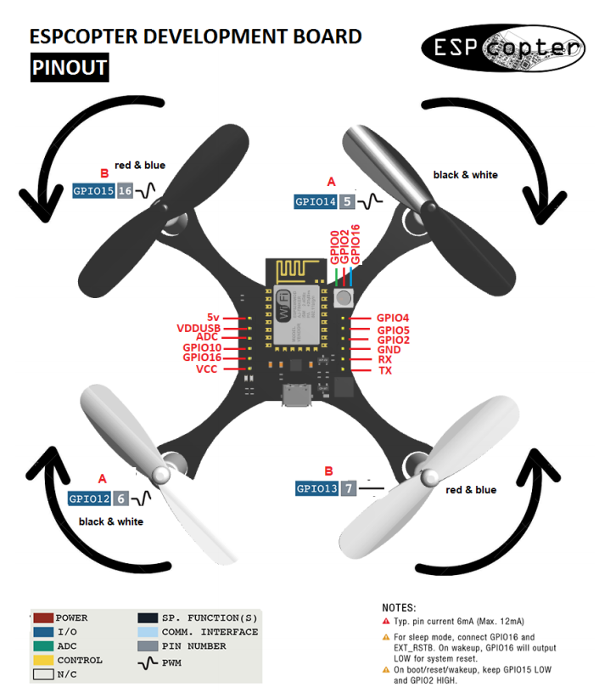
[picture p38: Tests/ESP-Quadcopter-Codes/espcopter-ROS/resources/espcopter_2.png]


## Available Features
This driver enables you to communicate espcopters with ros using wifi.
The available topics are:

```sh
$ rostopic list 
/drone_1/attitude # set the attitude of the drone controlling via PID.
/drone_1/attitude_status # get the current attitude of the drone.
/drone_1/battery # Battery voltage status.
/drone_1/command_status # get the current command sent to the drone.
/drone_1/imu # Gyro and accelerometer data.
/drone_1/led # Control the RGB led on the drone.
/drone_1/mag # Magnetometer data.
/drone_1/motors # Control each motor individually.
```

Also we provide some services that allow the user calibrate the drone:

```sh
$ rosservice list
/drone_1/arm_motors # arm/disarm the drone motors (toggle). 
/drone_1/gyro_calibration # start gyro calibration process.
/drone_1/mag_calibration # start magnetometer calibration process.
```

## How to build this firmare and install it on your ESPcopter
### Arduino Installation
- Install the latest version from the [Arduino website](https://www.arduino.cc/en/Main/Software).
- The following driver is reqired for the espcopter to be recognized by the computer. Download
and install the approperate [driver version](https://www.silabs.com/products/development-tools/software/usb-to-uart-bridge-vcp-drivers) for your OS.

### ESP8266 Library
- One need to update the board manager with a custom URL to enable Arduino compile esp8266 mpu. Open up Arduino,
then go to the Preferences (File > Preferences). Then, towards the bottom of the window, copy
this URL into the “Additional Board Manager URLs” text box:
```
http://arduino.esp8266.com/stable/package_esp8266com_index.json
```
- Hit OK. Then navigate to the Board Manager by going to (Tools > Boards > Boards Manager). There
should be a couple new entries in addition to the standard Arduino boards. Look for esp8266.
Click on that entry, then select Install. You need to install 2.5.0 version of esp8266 library. 

- The download process can take up to 10 minutes depending on your internet speed. After the
download is done, select NodeMCU 1.0 from the Tools tab and follow the other settings.

### Downloading the ESPcopter library:
- Access your ros workspace and clone this repo:
```sh
$ cd catkin_ws/src
$ git clone https://github.com/verlab/espcopter.git
$ cd ..
$ catkin_make # or catkin build
```
- Fixing dependecies:
```sh
$ rosdep install espcopter
```

- Open the **espcopter.ino** file using arduino ide and connect the ESPCopter with the computer using a micro USB cable. 
- Setup your WiFi network in the code:
```c++
/*********************************************************
   WIFI SETUP
*********************************************************/
IPAddress ROS_MASTER_ADDRESS(10, 42, 0, 1); // ros master ip
char* WIFI_SSID = "hero_network"; // network name
char* WIFI_PASSWD = "s3cr3tp4ss"; // network password
/*********************************************************/
```
- Check if the switch on the drone is ON position, and compile and burn the code into esp8266.

## How to connect the drone with ROS
- Open a terminal and run the roslaunch to bringup the drones:
```sh
$ roslaunch espcopter espcopter_bringup.launch
waiting for socket connection
[INFO] [1579104505.608789]: Established a socket connection from 10.42.0.127 on port 49154
[INFO] [1579104505.609296]: calling startSerialClient
[INFO] [1579104507.713159]: Requesting topics...
[INFO] [1579104507.761302]: Note: publish buffer size is 1024 bytes
[INFO] [1579104507.761692]: Setup publisher on /drone_1/battery [mavros_msgs/BatteryStatus]
[INFO] [1579104507.767787]: Setup publisher on /drone_1/imu [sensor_msgs/Imu]
[INFO] [1579104507.771223]: Setup publisher on /drone_1/mag [sensor_msgs/MagneticField]
[INFO] [1579104507.774226]: Setup publisher on /drone_1/attitude_status [mavros_msgs/AttitudeTarget]
[INFO] [1579104507.778017]: Setup publisher on /drone_1/command_status [mavros_msgs/AttitudeTarget]
[INFO] [1579104507.782331]: Setup service server on /drone_1/arm_motors [std_srvs/Trigger]
[INFO] [1579104507.785847]: Setup service server on /drone_1/gyro_calibration [std_srvs/Trigger]
[INFO] [1579104507.789240]: Setup service server on /drone_1/mag_calibration [std_srvs/Trigger]
[INFO] [1579104507.790900]: Note: subscribe buffer size is 1024 bytes
[INFO] [1579104507.797960]: Setup subscriber on /drone_1/led [std_msgs/ColorRGBA]
[INFO] [1579104507.802273]: Setup subscriber on /drone_1/motors [mavros_msgs/RCOut]
[INFO] [1579104507.806879]: Setup subscriber on /drone_1/attitude [mavros_msgs/AttitudeTarget]
[INFO] [1579104510.619883]: [/drone_1] Conected at time: 18709, loop_freq: 15289.000000, battery: 4246.000000
[INFO] [1579104515.617136]: [/drone_1] Conected at time: 23710, loop_freq: 15096.000000, battery: 4240.500000
[INFO] [1579104520.604998]: [/drone_1] Conected at time: 28711, loop_freq: 15520.000000, battery: 4240.500000

```

## How to teleoperate the drone using joystick
- A demo **teleop.py** script should be modified as you like to fit the control as your joystick.
- Open a terminal and run the roslaunch to teleoperate the drone:
```sh
$ roslaunch espcopter espcopter_teleop.launch
```
- Video Demo:

IMAGE ALT TEXT HERE (https://www.youtube.com/watch?v=mjpYxwDCcIA)

## How to calibrate the gyro
- To calibrate the gyro, place the drone in a flat surface and **DO NOT** move it.
- On a terminal and call the service:
```sh
$ rosservice call /drone_1/gyro_calibration "{}"
```
- Wait until the process is done. This process should be done at least once per drone at first time of fly.

## How to calibrate the magnetometer
- To calibrate the magnetometer, place the drone in a **flat surface**.
- On a terminal and call the service:
```sh
$ rosservice call /drone_1/mag_calibration "{}"
```
- Read the output of the drone bringup launch, start **turn the drone c.w. three times**.
- After turn the drone, put your finger on top of the drone (**becarefully**) and wait for the rest of the process.
- **The motors should turn on really quick (less than 1 second) the propelles and turn off**.
- This is for compensation of the magnetic field generated by the motors.
- Wait for the rest of the process.

- Video Demo:

IMAGE ALT TEXT HERE (https://www.youtube.com/watch?v=AO48jBouAZw)

## Maintainer
- [Paulo Rezeck](https://github.com/rezeck)

## More detail about ESPCopter
Espcopter it is a small size mini-drone that is a wirelessly networkable, interactive and programmable drone.
- [Access here](https://espcopter.com/)

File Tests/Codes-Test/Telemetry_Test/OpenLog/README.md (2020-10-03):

SparkFun OpenLog
================

<table class="table table-hover table-striped table-bordered">
  <tr align="center">
   <td><a href="https://www.sparkfun.com/products/13712">SparkFun OpenLog</a></td>
   <td><a href="https://www.sparkfun.com/products/13955">SparkFun OpenLog with Headers</a></td>
  </tr>
  <tr align="center">
    <td><i>SparkFun OpenLog (<a href="https://www.sparkfun.com/products/13712">DEV-13712</a>)</i></td>
    <td><i>SparkFun OpenLog with Headers (<a href="https://www.sparkfun.com/products/13955">DEV-13955</a>)</i></td>
  </tr>
</table>

OpenLog is an open source data logger that works over a simple serial connection and supports microSD cards up to 64GB. 

Repository Contents
-------------------
* **/Documentation** - Data sheets, additional product information
* **/Firmware** - Example sketches for the OpenLog, and for an Arduino connected to the OpenLog.
* **/Hardware** - Hardware design files for the OpenLog PCB. These files were designed in Eagle CAD.
* **/Libraries** - Libraries for use with the OpenLog.
* **/Production** - Production panel files (.brd)

Documentation
--------------
* **[Hookup Guide](https://learn.sparkfun.com/tutorials/openlog-hookup-guide)** - Basic hookup guide for the OpenLog.
* **[SparkFun Fritzing repo](https://github.com/sparkfun/Fritzing_Parts)** - Fritzing diagrams for SparkFun products.
* **[SparkFun 3D Model repo](https://github.com/sparkfun/3D_Models)** - 3D models of SparkFun products. 
* **[SparkFun Graphical Datasheets](https://github.com/sparkfun/Graphical_Datasheets)** -Graphical Datasheets for various SparkFun products.

License Information
-------------------

This product is _**open source**_! 

Please review the LICENSE.md file for license information. 

If you have any questions or concerns on licensing, please contact techsupport@sparkfun.com.

Distributed as-is; no warranty is given.

- Your friends at SparkFun.

_SDFatLib-beta and SerialPort are written by Bill Greiman, and released under GPLv3._

Version History
---------------

For a full view of changes please see the [changelog](https://github.com/sparkfun/OpenLog/blob/master/CHANGELOG.md). 

OpenLog v4 is refactored with better RAM utilization for better performance at higher record speeds (115200/57600).

OpenLog v3 is stable, supports FAT32 cards up to 64GB and supports higher record speeds (115200/57600).

OpenLog v2 is a bit buggy but supports FAT32 and SD cards up to 16GB.  

OpenLog v1 is stable but only supports FAT16 and up to 2GB.  

* **v1.0**  Buggy initial release
* **v1.1**  Small changes to system settings and EEPROM storage.
* **v1.2**  Added wild card to listing and remove commands. Added read file command.
* **v1.3**  Added auto buffer record if unit sits idle for more than 5 seconds.
* **v1.4**  Increase buffer size to 900 bytes. Pinning down URU errors.
* **v1.5**  Lowered power consumption to ~2mA avg. Added 4800 and 19200 baud rates.
* **v1.51** Added configurable escape character, and escape character amount.
* **v1.6**  Added ability to configure via config.txt file.
* **v2.0**  Massive overhaul. Ported to sdfatlib. Now supports FAT16/FAT32/SD/SDHC.
* **v2.1**  Power save not working. Fixed issue 35. Dropping characters at 57600bps.
* **v2.11** Tested with 16GB microSD. Fixed issues 30 & 34. Re-enable power save.
* **v2.2**  Modified append_file() to use a single buffer. Increased HardwareSerial.cpp buffer to 512 bytes.
* **v2.21** ringp fork brought in. rm dir, cd .., and wildcards now work!
* **v2.3**  Migrated to v10.10.10 of sdfatlib. Moved to inline RX interrupt and buffer.
* **v2.4**  Merged ringp updates. Commands cd, rm, ls work again!
* **v2.41** Power loss bug fixed. Adding support for 38400bps for testing with SparkFum 9DOF IMU logging. 
* **v2.5**  Added software reset command. Modified the read command to print extended ASCII characters.
* **v2.51** Changed command prompt control to ignore \n for easier control from microcontroller.
* **v3.0**  Migration to Arduino v1.0 and better recording speed at 115200bps and 57600bps.
* **v3.1**  Better handling of recording during power loss.
* **v3.2**  Freed up RAM for larger RX ring buffer. Added support for wildcards and ability to ignore emergency override.
* **v3.3**  Added ability to ignore escape character checking and corrected incremental log naming.
* **v4.0**  Re-worked to be compatible with Arduino v1.6.x. Freed RAM to increase RX buffer size.

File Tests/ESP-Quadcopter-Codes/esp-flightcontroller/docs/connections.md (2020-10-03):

# WEMOS D1 MINI pinout
```
Pin | Function         | ESP-8266 Pin | ESPFC external device
----+------------------+--------------+----------------------------------------------
TX  | TXD0             | TXD, GPIO1   | (UART0 TX) | CLI | MSP | OSD | GPS
RX  | RXD0             | RXD, GPIO3   | (UART0 RX) | CLI | MSP | OSD | GPS | SBUS
A0  | Analog In,  3.3V | A0           | Batery voltage or current sensor, analog only
D0  | IO               | GPIO16       | LED | BUZZER | PWM (output recommended, no interrupts)
D1  | IO, SCL          | GPIO5        | I2C Gyro, Compas, Pressure and other sensors
D2  | IO, SDA          | GPIO4        | I2C Gyro, Compas, Pressure and other sensors
D3  | IO, PU           | GPIO0        | PWM 1 (servo/motor)
D4  | IO, PU, LD, TXD1 | GPIO2        | Blackbox (UART1 TX)
D5  | IO, SCK          | GPIO14       | PWM 2 (servo/motor)
D6  | IO, MISO         | GPIO12       | PWM 3 (servo/motor)
D7  | IO, MOSI         | GPIO13       | PPM RX | PWM
D8  | IO, SS, PD       | GPIO15       | PWM 4 (servo/motor)
G   | Ground           | GND          | Ground
5V  | 5V               | N/A          | 5V power
3V3 | 3.3V             | 3.3V         | 3.3V power - to I2C devices
RST | Reset            | RST          | Reset switch (optional)
```

## Legend:
```
   PU - 10k pull up
   PD - 10k pull down
 RXD0 - UART0 hardware RX
 TXD0 - UART0 hardware TX
 TXD1 - UART1 hardware TX
   LD - builtin LED
```

## Notice:
```
 A0 - In ESP-8266 is 1.0V range, Wemos has 220k:100k divider for 3.3V range, 22k:4k7 additional divider required for 4S Lipo
 D0 - No iterrupts (recommended output)
 D3, GPIO0 - if low at boot, then board enters to flashing mode (avoid using as input)
 D4, GPIO2 - must be high during flashing (avoid using as input)
 D8, GPIO15 - must be low during flashing or boot (avoid using as input)
```
https://github.com/esp8266/esp8266-wiki/wiki/Boot-Process#esp-boot-modes

## Wemos D1 mini board layout:
```
      /-----------\
   TX |           | RST
   RX |           | A0
   D1 |           | D0
   D2 |           | D5 ~>
<~ D3 |           | D6 ~>
<~ D4 |           | D7 ~<
  GND |           | D8 ~>
   5v |           | 3.3V
      +---|---|---+
           USB
```

# ESP32 pinout
```
Pin | Name | Function                                   | ESPFC external device
----+------+--------------------------------------------+----------------------------------------------
 0  |      | PU,ADC2_CH1,CLK_OUT1                       | >  M0
 1  | TXD  | U0TXD,CLK_OUT3                             |    TX0, PROG, MSP
 2  |      | ADC2_CH2,HSPIWP,HS2_DATA0,SD_DATA0         | >  M1
 3  | RXD  | U0RXD,CLK_OUT2                             |    RX0, PROG, MSP
 4  |      | ADC2_CH0,HSPIHD,HS2_DATA1,SD_DATA1         | $  BUZZER
 5  |      | VSPICS0,HS1_DATA6                          | >  SPI_CS0_GYRO, SPI0_SS
11  | CMD  | SD_CMD,SPICS0,HS1_CMD,U1RTS                | $  SPI_CS1_BARO
12  | TD1  | PD,ADC2_CH5,MTDI,HSPIQ,HS2_DATA2,SD_DATA2  | >  M5, SPI1_MISO 
13  | TCK  | ADC2_CH4,MTCK,HSPID,HS2_DATA3,SD_DATA3     |    M6, SPI1_MOSI
14  | TMS  | ADC2_CH6,MTMS,HSPICLK,HS2_CLK,SD_CLK       |    M7, SPI1_SCK
15  | TD0  | PU,ADC2_CH3,MTDO,HSPICS0,HS2_CMD,SD_CMD    | >  SPI_CS2_SDCARD, SPI1_SS
16  |      | HS1_DATA4,U2RXD                            |    RX2
17  |      | HS1_DATA5,U2TXD                            |    TX2
18  |      | VSPICLK,HS1_DATA7                          |    SPI0_SCK
19  |      | VSPIQ,U0CTS                                |    SPI0_MISO
21  |      | VSPIHD                                     |    I2C0_SCL
22  |      | VSPIWP,U0RTS                               |    I2C0_SDA
23  |      | VSPID,HS1_STROBE                           |    SPI0_MOSI
25  |      | ADC2_CH8,DAC1                              |    M2
26  |      | ADC2_CH9,DAC2                              |    M3
27  |      | ADC2_CH7                                   |    M4
32  |      | ADC1_CH4,XTAL                              |    RX1
33  |      | ADC1_CH5,XTAL                              |    TX1
34  |      | ADC1_CH6                                   | <$ ADC, INTR
35  |      | ADC1_CH7                                   | <  PPM, ADC, INTR
36  | SVP  | ADC1_CH0                                   | <  ADC_VOLTAGE
37  | -    | ADC1_CH1                                   | -  N/A
38  | -    | ADC1_CH2                                   | -  N/A
39  | SVN  | ADC1_CH3                                   | <  ADC_CURRENT

RESERVED
 6  | CLK  | SD_CLK,SPICLK,HS1_CLK,U1CTS                | (flash)
 7  | SD0  | SD_DATA0,SPIQ,HS1_DATA0,U2RTS              | (flash)
 8  | SD1  | SD_DATA1,SPID,HS1_DATA1,U2CTS              | (flash)
 9  | SD2  | SD_DATA2,SPIHD,HS1_DATA2,U1RXD             | (flash)
10  | SD3  | SD_DATA3,SPIWP,HS1_DATA3,U1TXD             | (flash)

NOT EXISTS
20  | -    | -                                          | -
24  | -    | -                                          | -
28  | -    | -                                          | -
29  | -    | -                                          | -
30  | -    | -                                          | -
31  | -    | -                                          | -
```

## Legend
```
 '>' recommended output only
 '<' input only
 '$' free
 '-' not available
```
GPIO `0, 2, 12, 15` recommended as output because of boot process impact
GPIO `34-39` are input-only by chip

- GPIO0 - Low/GND	ROM serial bootloader for esptool.py, High/VCC	Normal execution mode
- GPIO2 - GPIO2 must also be either left unconnected/floating, or driven Low, in order to enter the serial bootloader. In normal boot mode (GPIO0 high), GPIO2 is ignored.
- GPIO12 - If driven High, flash voltage (VDD_SDIO) is 1.8V not default 3.3V. Has internal pull-down, so unconnected = Low = 3.3V. May prevent flashing and/or booting if 3.3V flash is used and this pin is pulled high, causing the flash to brownout. See the ESP32 datasheet for more details.
- GPIO15 - If driven Low, silences boot messages printed by the ROM bootloader. Has an internal pull-up, so unconnected = High = normal output.
- GPIO5 - configures SDIO Slave in "Download Boot"

https://github.com/espressif/esptool/wiki/ESP32-Boot-Mode-Selection

## ESP32 mini board layout
```
                  /-------------\
 GND      RST     |             |  TXD (1)    GND
  NC      SVP(36) |             |  RXD (3)    IO(27)
 SVN(39)   IO(26) |             |   IO(22)    IO(25)
  IO(35)   IO(18) |             |   IO(21)    IO(32)
  IO(33)   IO(19) |             |   IO(17)   TD1(12)
  IO(34)   IO(23) |             |   IO(16)    IO(04)
 TMS(14)   IO(05) |             |  GND        IO(00)
  NC      3V3     |             |  VCC(5v)    IO(02)
 SD2(09)  TCK(13) |             |  TD0(15)   SD1(08)
 CMD(11)  SD3(10) |             |  SD0(07)   CLK(06)
                  +----|---|----+
                        USB
```

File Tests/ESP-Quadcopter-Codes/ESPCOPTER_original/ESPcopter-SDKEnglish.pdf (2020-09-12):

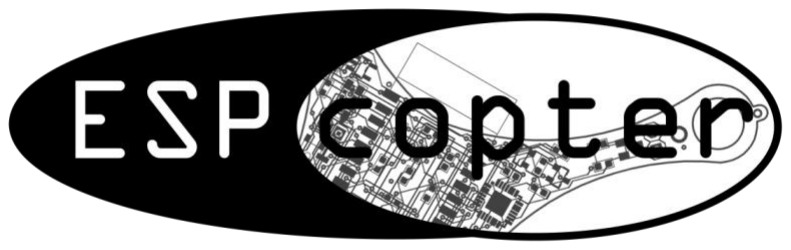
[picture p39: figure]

# ESPcopter SDK

## 1.0.0 (Beta)

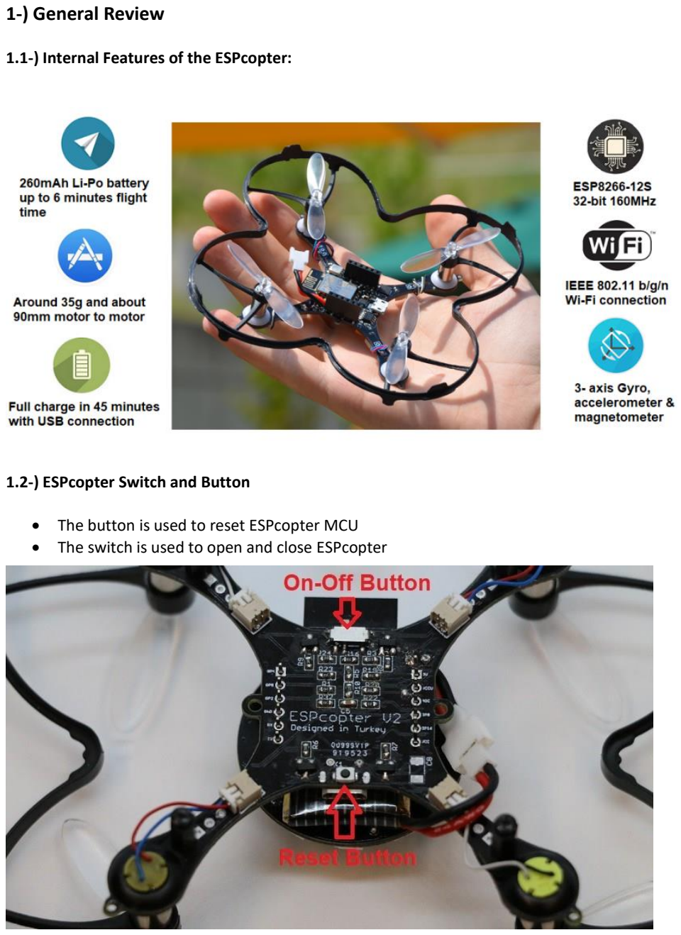
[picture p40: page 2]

1-) General Review

1.1-) Internal Features of the ESPcopter:

1.2-) ESPcopter Switch and Button

- The button is used to reset ESPcopter MCU
- The switch is used to open and close ESPcopter

1.2-) Pinout and Propeller and Motor Directions

When installing in accordance with the letters on the propellers, the motors must be fitted according to the cable colors.

Engine positions:

Left Front: B - Red, Blue | Right Front: A - Black, White
Left Rear: A – Black, White | Right Rear: B – Red, Blue

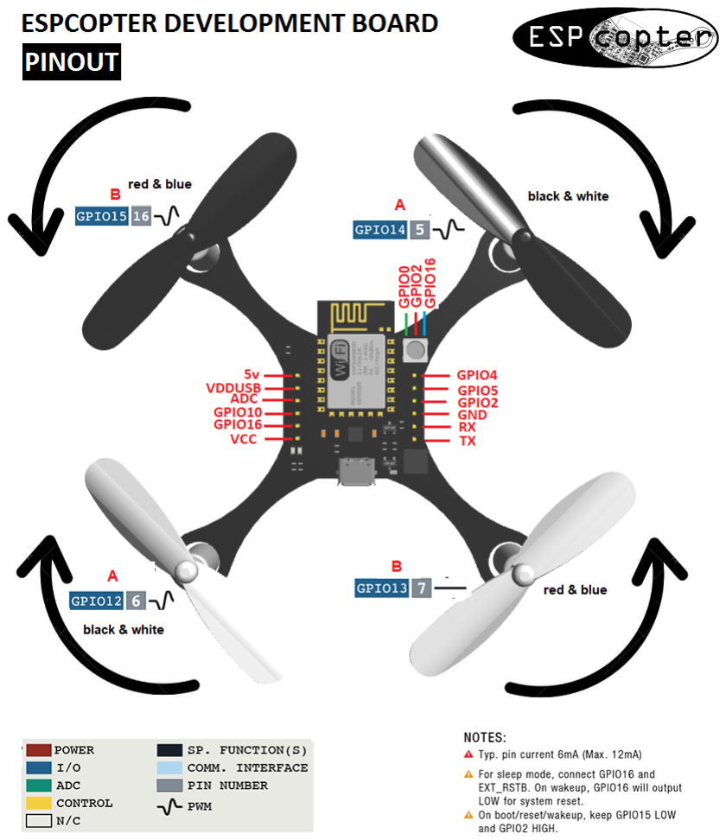
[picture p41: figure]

1.3-) How to Charge the ESPcopter:

The ESPcopter will charge when connected to the micro-usb. The switch on the ESPcopter must be in the off position to charge.

Red Light: Charging
Green Light: Fully Charged

2-) Software:

2.1-) Arduino Installation:

Download and install the latest version from the Arduino web site: https://www.arduino.cc/en/Main/Software

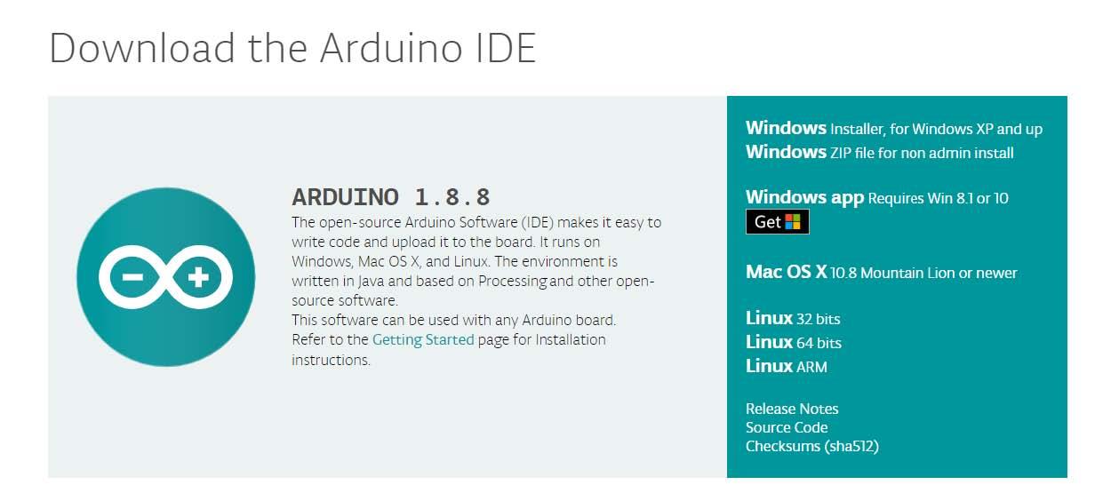
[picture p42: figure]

2.2-) Driver Installation:
The following driver is reqired for the ESPcopter to be recognized by the computer. Download and install the approperate driver version for your OS.

https://www.silabs.com/products/development-tools/software/usb-to-uart-bridge-vcp-drivers

2.3-) ESP8266 Library

To begin, we’ll need to update the board manager with a custom URL. Open up Arduino, then go to the Preferences (File> Preferences). Then, towards the bottom of the window, copy this
URL into the “Additional Board Manager URLs” text box:

http://arduino.esp8266.com/stable/package_esp8266com_index.json

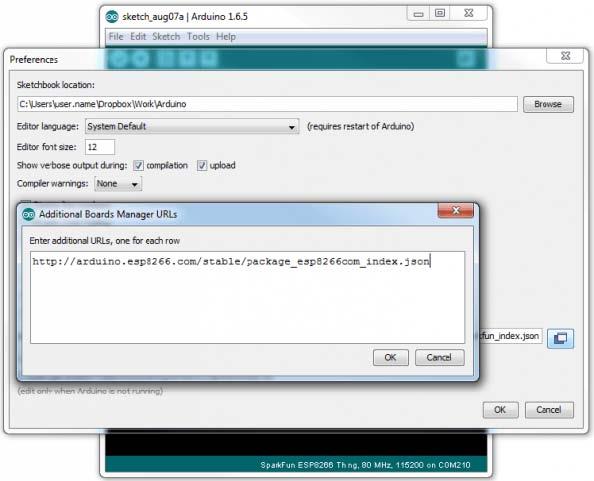
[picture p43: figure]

Hit OK. Then navigate to the Board Manager by going to Tools > Boards > Boards Manager. There should be a couple new entries in addition to the standard Arduino boards. Look for esp8266. Click on that entry, then select Install. You need to install 2.5.0 version of esp8266 library.

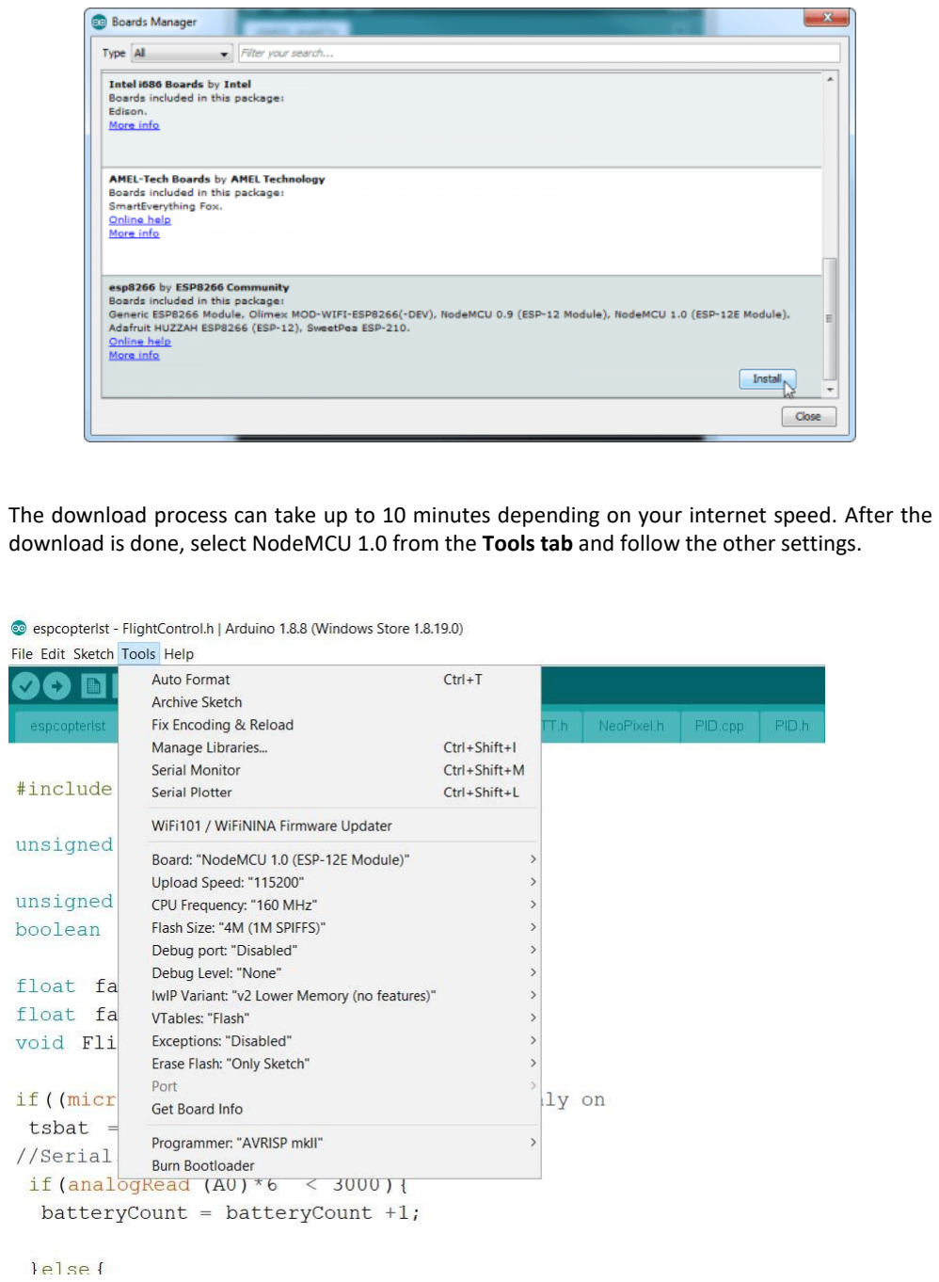
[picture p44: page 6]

The download process can take up to 10 minutes depending on your internet speed. After the download is done, select NodeMCU 1.0 from the Tools tab and follow the other settings.

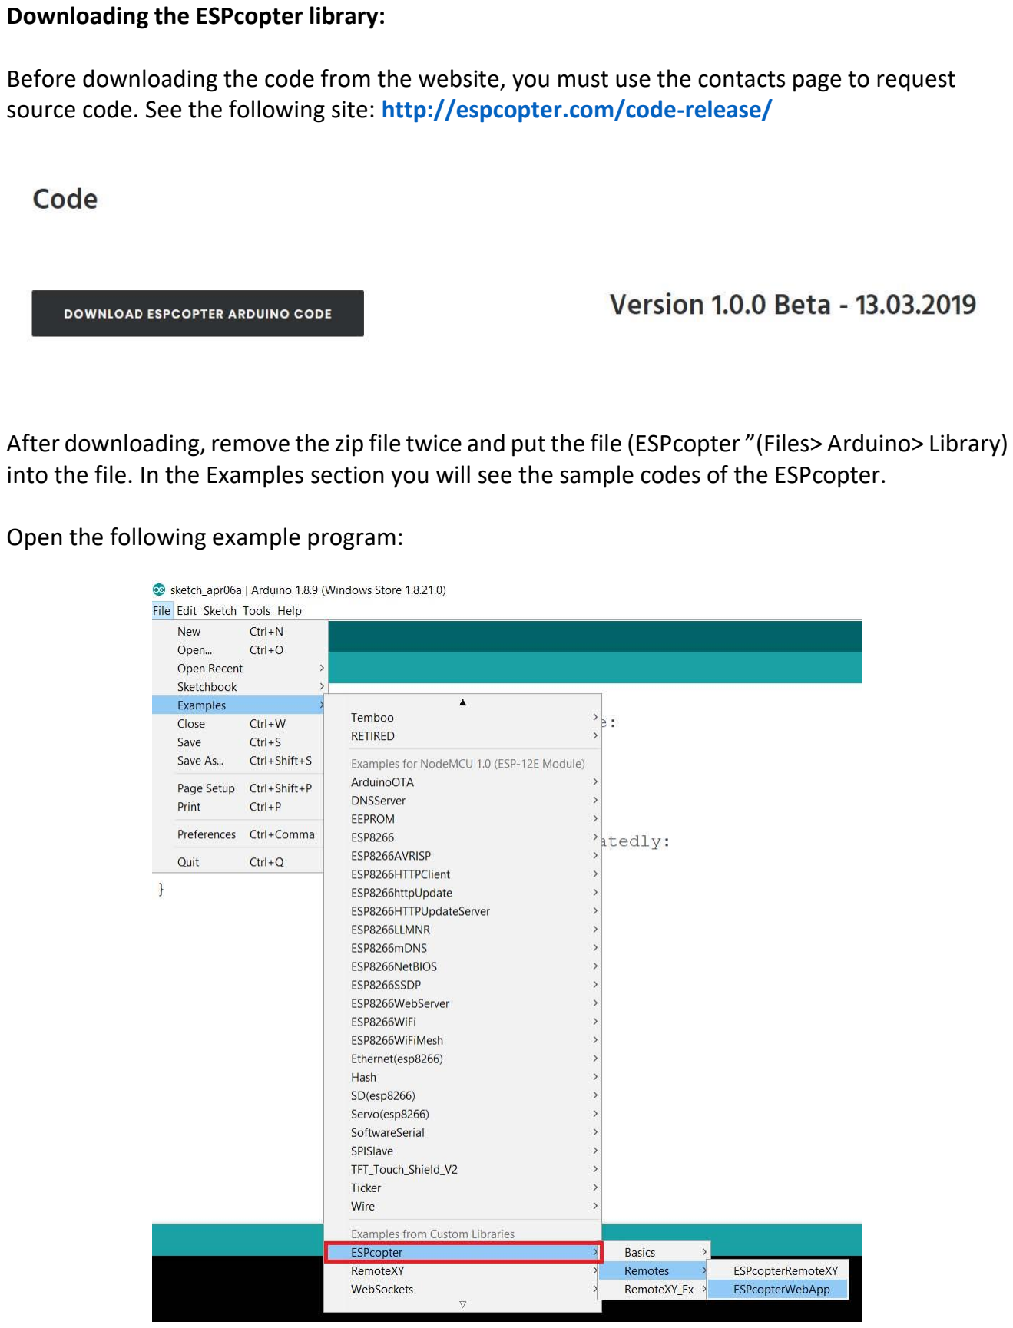
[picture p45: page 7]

Downloading the ESPcopter library:

Before downloading the code from the website, you must use the contacts page to request source code. See the following site: http://espcopter.com/code-release/

After downloading, remove the zip file twice and put the file (ESPcopter ”(Files> Arduino> Library) into the file. In the Examples section you will see the sample codes of the ESPcopter.

Open the following example program:

The ESPcopter will have the flight control software to make the flight stable. This ESPcopterWebApp example is a demonstration of the ESPcopter having the additional ability to act as a self-contained web server. This will get you running your ESPcopter fast because you can control it from a web page on your phone, tablet or laptop. More advanced examples (Although this is very cool) are already available from the Arduino IDE menu.
Let’s hope you have had the ESPcopter switched off and the batteries charging via the USB port so you can be ready for the first flight.

ESPcopter standalone Code(Web APP)

#define REMOTE_WEB_APP

#define WEB_APP_WIFI_SSID "ESPcopter" //ESPcopter Wiffi ismi

#define WEB_APP_WIFI_PASSWORD "12345678" //ESPcopter Wiffi şifresi

#include <espcopter.h>

void setup() {

mainSetup();

}

void loop() {

mainLoop();

}

Connection:
After installing the software, turn on the drone. In the wifi tab of your phone, you will see the name of the drone.

WIFI_SSID “ESPcopter
WIFI_PASSWORD “12345678”

After making the connection, open any web browser application from your phone. Type 192.168.4.1 in the search line.

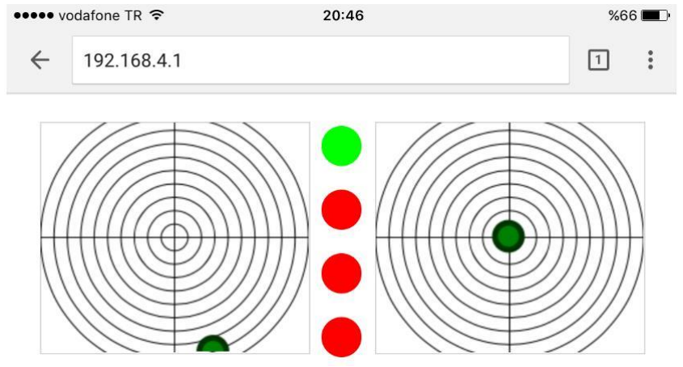
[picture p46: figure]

## Control review:


Buttons:

First Button : ARM – DISARM
Second Button: AUTO YAW CONTROL Third Button: AUTO ALTİTUDE CONTROL Forth Button: AUTO MISSION CONTROL

ESPcopter standalone Code(RemoteXY)

#define REMOTEXY_WIFI_SSID “RemoteXY”

#define REMOTEXY_WIFI_PASSWORD “12345678”

#define REMOTE_XY_REMOTE

#include <espcopter.h> // library

void setup() {

mainSetup(); // main flying setup

}

void loop() {

mainLoop (); // main flying loop

}

Connection:
After installing the software, turn on the drone. In the wifi tab of your phone, you will see the name of the drone.

WIFI_SSID “RemoteXY
WIFI_PASSWORD “12345678”

After you make the connection, open RemoteXY from your phone. After making the connection, the screen below will open automatically.


## Controller Review:


## Calibration:

1- Start Calibration
The ESPcopter has at a minimum a Gyro, acceleration and Earth magnetic field sensors. They must be calibrated when you first turn on the ESPcopter. Calibration mode starts with the red light flashing. Do not turn off the ESPcopter until the calibration algorithm has finished. If you turn it off, the calibration will run again at the next boot.


2- Magnetic Field Calibration (Compass):
Now place it on a flat, non-metal surface. The blue light indicates that the magnetic field calibration has started. At this stage you have to turn the ESPcopter around twice.


3- Gyro Calibration:
After you have calibrated the compass the ESPcopter's light will be purple. Do not touch the ESPcopter after this step. It will run its engines for a few seconds without taking off from the ground.


Calibration is completed!!!

Custom commands:

ESPcopter functions:

The LEDs and motors on the ESPcopter can be controlled using the functions found in this list.

Function | Acceptable Values | Description
esp.redLed_Digital(); | 0 - 1 or FALSE - TRUE | Controls Red LED on/off
esp.blueLed_Digital(); | 0 - 1 or FALSE - TRUE | Controls Blue LED on/off
esp.greenLed_Digital(); | 0 - 1 or FALSE - TRUE | Controls Green LED on/off
esp.redLed_Analog(); | 0 - 255 | Controls Red LED brightness
esp.blueLed_Analog(); | 0 - 255 | Controls blue LED brightness
esp.greenLed_Analog(); | 0 - 255 | Controls green LED brightness
esp.motorFL_Analog(); | 0 - 255 | Operates front left engine at desired power.
esp.motorFR_Analog(); | 0 - 255 | The front right operates the engine at the desired power.
esp.motorRL_Analog(); | 0 - 255 | Operates the rear left engine at the desired power.
esp.motorRR_Analog(); | 0 - 255 | The rear right operates the engine at the desired power.

ESPcopter Control Table:

The control method of the ESPcopter can be changed using the definitions in this list. Only one definition should be activated from this list.

Function | Description | Control Device
#define REMOTE_XY_REMOTE | Control with RemoteXY | Phone - Tablet

#define BLYNK | Control with BLYNK | Phone - Tablet

#define PROCESSING_REMOTE | Control with processing | Computer

#define MQTT | Control with MQTT | Computer

#define REMOTE_WEB_APP | Web application control | Phone - Tablet

#define PPM_REMOTE | Control with PPM receiver | Standard RC Remote

ESPcopter Global Variable Definitions:

Function | Description | Value Range
setTrimRoll(); | Trim on the X-axis. | -500 - 500
setTrimPitch(); | Trim on the Y-axis. | -500 - 500
setTrimYaw(); | Trim on the Yaw.. | -500 - 500
setArmControl(); | Motor Enable | false - true
setFlyMode_1(); | Z-axis stabilization on-off | false - true
setFlyMode_2(); | Height fixing on-off | false - true
setFlyMode_3(); | Optical flow module with motion stabilization | false - true
landing(); | Landing | false - true
setMotorMax(); | Set maximum motor power | 600-900
getRX_throttle(); | Motor power rating | 0 – (motorMax)
getRX_roll(); | The value in the X-axis | -100 : + 100
getRX_pitch(); | The value in the Y-axis | -100 : + 100
getRX_yaw(); | The value in the Z-axis | -100 : + 100

Autonomous Flight Commands:

Function | Description | Value Range
takeOff(Y, T); | When the command line runs, the drone automatically takes off. | Y: 200 - 1000 Height T: Flight time
goforward(T); | The drone moves forward during the duration. | T: Flight time
goBack(T); | During the T Time the drone moves back. | T: Flight time
goLeft(T); | The drone moves to the left during the duration. | T: Flight time
goRight(T); | The drone moves right through the time. | T: Flight time
turnRight(D); | D rotates right up to its own angle in angle. | D: Rotation angle
turnLeft(D); | The angle of D turns to the left in its own frame | D: Rotation angle
delay_(T); | It allows you to wait before executing the next command | T: Standby time
Land(); | In autonomous flight mode, this must be at the end of the commands.

Altitude Hold Module

Function | Description | Value Range
setVl5310xControl (); | vl5310x module on-off | False - true
setTargetOto(); | Height stabilizer with vl5310x module | 250 - 1000
getOtoMeasure(); | Drone's elevation data | 0- 1000

Buzzer Module:

Function | Description | Value range
esp.buzzer(); | 0 - 1 or FALSE - TRUE | On- Off buzzer

Neopixel Module:

Function | Description | Value range
#define NeoPixel | Turns the Neopixel module on and off | Include in the program

ESPrainbow(); | Makes an automatic rainbow effect
ESPsetPixel (x,r,g,b); | Set each led separately. After setting pixels call | X= 1 – 12 R(Red)= 0 - 255 G(Green)= 0 - 255 B(Blue)= 0 - 255
ESPpixelShow(); | Applies the changes made with

Optical Flow Module:

Function | Description | Value range
SetPointOpt[0] | Sets the speed of Drone using the optic flow sensor. If this value is equal to zero, the drone remains stationary in the x-axis. Positive moves right, Negative moves left | -15 - +15
SetPointOpt[1] | Sets the speed of Drone using the optic flow sensor. If this value is equal to zero, the drone stops at the y | -15 - +15

| axis. Positive goes forward, Negative- goes back
deltaCalX | X-axis flow data from the optical flow extender. | Relative to the drone current speed
deltaCalY | Y-axis flow data from the optical flow damper. | Relative to the drone current speed

Multi-Distance Module:

Function | Description | Value range
#define HandControl #define AntiCollision | Manual control or collision prevention system Must choose one or the other

Distance_Y_1(); | Y (+) axis distance data | 50-1000
Distance_Y_0(); | Y (-) axis distance data | 50-1000
Distance_X_1(); | X (+) axis distance data | 50-1000
Distance_X_0(); | X (-) axis distance data | 50-1000

Other Commands

All other common Arduino and ESP8266 commands can be used in the library except for the following which will interfere with drone operation.

delay();
analogWrite();
Tone();

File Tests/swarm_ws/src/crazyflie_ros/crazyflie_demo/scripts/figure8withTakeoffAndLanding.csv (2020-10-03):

Duration | x^0 | x^1 | x^2 | x^3 | x^4 | x^5 | x^6 | x^7 | y^0 | y^1 | y^2 | y^3 | y^4 | y^5 | y^6 | y^7 | z^0 | z^1 | z^2 | z^3 | z^4 | z^5 | z^6 | z^7 | yaw^0 | yaw^1 | yaw^2 | yaw^3 | yaw^4 | yaw^5 | yaw^6 | yaw^7
1.20367 | 0 | 0 | 0 | 0 | 0.832848 | -1.72666 | 1.20348 | -0.285653 | 0 | 0 | 0 | 0 | 0.411004 | -0.848433 | 0.589231 | -0.139607 | 0 | 0 | 0 | 0 | 4.3626 | -8.02347 | 5.27481 | -1.20938 | 0 | 0 | 0 | 0 | 0 | 0 | 0 | 0
1.39935 | 0 | -0.149141 | -0.134608 | -0.0175285 | -2.17877 | 3.93034 | -2.37529 | 0.487337 | 0 | -0.077144 | -0.0777131 | -0.0188344 | -0.70314 | 1.00636 | -0.514888 | 0.0927063 | 0.5 | 0.440461 | -0.081984 | -0.116844 | -1.53838 | 2.47463 | -1.36944 | 0.263393 | 0 | 0 | 0 | 0 | 0 | 0 | 0 | 0
1.3624 | -0.5 | -0.012876 | 0.185585 | -0.0205929 | 0.789539 | -1.13473 | 0.590816 | -0.108697 | -0.5 | -0.521826 | -0.0104919 | -0.0241408 | -0.494533 | 1.28085 | -0.910668 | 0.207379 | 0.5 | -0.137313 | 0.0754433 | 0.0286866 | 0.19348 | -0.327731 | 0.177371 | -0.0330612 | 0 | 0 | 0 | 0 | 0 | 0 | 0 | 0
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

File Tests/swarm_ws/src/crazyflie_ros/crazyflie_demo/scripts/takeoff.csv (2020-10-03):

Duration | x^0 | x^1 | x^2 | x^3 | x^4 | x^5 | x^6 | x^7 | y^0 | y^1 | y^2 | y^3 | y^4 | y^5 | y^6 | y^7 | z^0 | z^1 | z^2 | z^3 | z^4 | z^5 | z^6 | z^7 | yaw^0 | yaw^1 | yaw^2 | yaw^3 | yaw^4 | yaw^5 | yaw^6 | yaw^7
1.15839 | 0 | 0 | 0 | 0 | 0 | 0 | 0 | 0 | 0 | 0 | 0 | 0 | 0 | 0 | 0 | 0 | 0 | 0 | 0 | 0 | 1.06614 | -1.57474 | 0.868105 | -0.172428 | 0 | 0 | 0 | 0 | 0 | 0 | 0 | 0
1.13522 | 0 | 0 | 0 | 0 | 0 | 0 | 0 | 0 | 0 | 0 | 0 | 0 | 0 | 0 | 0 | 0 | 0.25 | 0.399333 | 3.03717e-14 | -0.0697493 | 0.0551273 | -0.643041 | 0.742072 | -0.234074 | 0 | 0 | 0 | 0 | 0 | 0 | 0 | 0

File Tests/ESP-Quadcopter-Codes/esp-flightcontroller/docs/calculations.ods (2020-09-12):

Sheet: sample rate
clock | 1000 | 8000 |  | 1000 | 8000
rate | freq |  | freq | rate
0 | 1000 | 1000 | 50 | 19,6 | 156,9 | 0,001 | 0,002 | 0,005
1 | 500 | 500 | 100 | 9,9 | 79,2 | 0,002 | 0,004 | 0,010
2 | 333 | 333 | 167 | 6,0 | 47,6 | 0,003 | 0,006 | 0,015
3 | 250 | 250 | 200 | 5,0 | 39,8 | 0,004 | 0,008 | 0,020
4 | 200 | 200 | 250 | 4,0 | 31,9 | 0,005 | 0,010 | 0,025
5 | 167 | 167 | 300 | 3,3 | 26,6 | 0,006 | 0,012 | 0,030
6 | 143 | 143 | 333 | 3,0 | 24,0 | 0,007 | 0,014 | 0,035
7 | 125 | 125 | 350 | 2,8 | 22,8 | 0,008 | 0,016 | 0,040
8 | 111 | 111 | 400 | 2,5 | 20,0 | 0,009 | 0,018 | 0,045
9 | 100 | 100 | 500 | 2,0 | 16,0 | 0,010 | 0,020 | 0,050
10 | 91 | 91 | 600 | 1,7 | 13,3 | 0,011 | 0,022 | 0,055
11 | 83 | 83 | 700 | 1,4 | 11,4 | 0,012 | 0,024 | 0,060
12 | 77 | 77 | 800 | 1,2 | 10,0 | 0,013 | 0,026 | 0,065
13 | 71 | 71 | 900 | 1,1 | 8,9 | 0,014 | 0,028 | 0,070
14 | 67 | 67 | 1000 | 1,0 | 8,0 | 0,015 | 0,030 | 0,075
15 | 63 | 63 | 1100 | 0,9 | 7,3 | 0,016 | 0,032 | 0,079
16 | 59 | 59 |  |  |  | 0,017 | 0,034 | 0,085
17 | 56 | 56 |  |  |  | 0,018 | 0,036 | 0,089
18 | 53 | 53 |  |  |  | 0,019 | 0,038 | 0,094
19 | 50 | 50 |  |  |  | 0,020 | 0,040 | 0,100
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

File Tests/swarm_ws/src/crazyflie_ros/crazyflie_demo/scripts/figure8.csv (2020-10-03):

duration | x^0 | x^1 | x^2 | x^3 | x^4 | x^5 | x^6 | x^7 | y^0 | y^1 | y^2 | y^3 | y^4 | y^5 | y^6 | y^7 | z^0 | z^1 | z^2 | z^3 | z^4 | z^5 | z^6 | z^7 | yaw^0 | yaw^1 | yaw^2 | yaw^3 | yaw^4 | yaw^5 | yaw^6 | yaw^7
1.050000 | 0.000000 | -0.000000 | 0.000000 | -0.000000 | 0.830443 | -0.276140 | -0.384219 | 0.180493 | -0.000000 | 0.000000 | -0.000000 | 0.000000 | -1.356107 | 0.688430 | 0.587426 | -0.329106 | 0.000000 | 0.000000 | 0.000000 | 0.000000 | 0.000000 | 0.000000 | 0.000000 | 0.000000 | 0.000000 | 0.000000 | 0.000000 | 0.000000 | 0.000000 | 0.000000 | 0.000000 | 0.000000
0.710000 | 0.396058 | 0.918033 | 0.128965 | -0.773546 | 0.339704 | 0.034310 | -0.026417 | -0.030049 | -0.445604 | -0.684403 | 0.888433 | 1.493630 | -1.361618 | -0.139316 | 0.158875 | 0.095799 | 0.000000 | 0.000000 | 0.000000 | 0.000000 | 0.000000 | 0.000000 | 0.000000 | 0.000000 | 0.000000 | 0.000000 | 0.000000 | 0.000000 | 0.000000 | 0.000000 | 0.000000 | 0.000000
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

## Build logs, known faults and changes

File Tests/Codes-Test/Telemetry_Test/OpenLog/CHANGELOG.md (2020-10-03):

#Change Log
All notable changes to this project will be documented in this file. We'll also give shout outs to folks who help fix bugs and generally make OpenLog a better experience.
 
## [4.0] - November 23 2015 

27,046 bytes compiled

Welcome to version 4! Now compiles under Arduino v1.6.x! Thanks @owenduffy for getting OpenLog ported to the new SdFatLib.

Worked on issue #168. Fixed issue #178. Thanks @jremington! Now works with Bill's latest [SD lib](https://github.com/greiman/SdFat-beta).

[Added] Escape character sequences are now removed from logs. If you hit ctrl+z three times you'll drop to the command shell and the three escape characters will not be recorded to the log.

[Removed] The pwd command has been removed from the command shell. This *shouldn't* effect anyone but you should know.

[Removed] The sync command has been removed from the command shell. This *shouldn't* effect anyone but you should know.

Fixed a bad bug found by @ystark. Thank you! New file name array is now correctly defined as static.

Fixed the LEDs so they now blink correctly when doing an emergency reset.

In order to get the maximum out of SerialPort lib you'll need to edit SerialPort.h: 

* Set BUFFERED_TX to 0
* Set ENABLE_RX_ERROR_CHECKING to 0

## [3.3] August 2014

28,350 bytes compiled

Using the latest SdFat lib from Bill: https://code.google.com/p/sdfatlib/downloads/list
Using Arduino v1.5.4

Fixed issue #160: https://github.com/sparkfun/OpenLog/issues/160
Logs now increment continously regardless of what file may be on the card. Adds 6 bytes.

Added feature/issue #166: If escape characters is set to zero, it ignores all escape characters. Adds 200 bytes.

Fixed issue 164 - Reducing RX buffer size to allow for correct baud rate changes.
SerialPort<0, 780, 0> NewSerial; //Fails
SerialPort<0, 750, 0> NewSerial; //Works

Fixed issue #163 - using dlkeng's fix to get baud rate to work at 300 baud. Adds 80 bytes.

Increased escape character limits to 0 and 254. If set to zero, it will not check for escape characters.

## [3.2] April 8 2013

28,640 bytes compiled (yay! saved a bunch by removing the text-based menu system)

Re-wrote baud rate system to support anything from 300bps to 1,000,000bps

Added support for newlines when using the 'write' command.
Should fix issue #149.

Fixed issue #134: When removing files and there is a directory, all wildcard files are now removed correctly.
Fixed issue #135: ls with wildcard works again. Thank you @dlkeng!

## [3.14]

29,354 bytes compiled

Added support for 1200bps. Issue #139.

## [3.13]

29,172 bytes compiled

Changed the string compares from strings in RAM (strcmp) to strings located in flash memory (strcmp_P).

We used to use this type of compare: else if(strcmp_P(command_arg, PSTR("md")) == 0)

I'm not sure how or why I got away from it, but bringing it back frees up a lot of RAM. I bet I got rid of PSTRs in an attempt to reduce code size when I should have been more worried about RAM running out. RAM is currently at 645 after 2 and 562 once we've begun append_file. Also figured out there is sprintf_P built just for PSTRs. Neat! RAM is currently at 779 after 2 and 696 once we've begun append_file. Removal of strncmp(). I believe we used it to reduce flash footprint. Once migrated to PSTR, it makes it worse.

## [3.12]

29,282 bytes compiled

Using freeMemory() function from JeeLabs. Seems to be working well.

Echo on/off is working again with a reduction of the buffer from 600 to 500. Code size is up a bit to 29,282. We have free RAM of about 527 after "2" and 444 once we've begun append_file.

## [3.11] March 26 2012

Added freeMemory support for RAM testing.

This was taken from: http://arduino.cc/playground/Code/AvailableMemory

## [3.1] March 23 2012

Fixed bug where entire log data is lost when power is lost.

Added fix from issue #76. Added support for verbose and echo settings recorded to the config file and EEPROM. Bugs #101 and #102 fixed with the help of @pwjansen and @wilafau - thank you!!

Because of the new code to the cycle sensitive append_log loop, 115200bps is not as rock solid as I'd like. I plan to correct this in the Light version.

Added a maxLoop variable calculation to figure out how many bytes to receive before we do a forced file.sync.

## [3.0] March 14 2012

28,354 bytes compiled

Re-write of core functions. Support under Arduino v1.0. Now supports full speed 57600 and 115200bps! Lower standby power.

Be sure to check out https://github.com/nseidle/OpenLog/issues for issues that have been resolved up to this version.

Update to new beta version of SerialPort lib from Bill Greiman. Update to Arduino v1.0. With Bill's library, we don't need to hack the HardwareSerial.cpp.

Re-wrote the append function. This function is the most important function and has the most affect on record accuracy. We are now able to record at 57600 and 115200bps at full blast! The performance is vastly improved.

To compile v3.0 you will need Arduino v1.0 and Bill's beta library: http://beta-lib.googlecode.com/files/SerialLoggerBeta20120108.zip Unzip 'SerialPortBeta20120106.zip' and 'SdFatBeta20120108.zip' to the libraries directory and close and restart Arduino.

Small stuff:

* Redirected all static strings to point to the new way in Arduino 1.0: Serial.print(F("asdf")); instead of PgmPrint
* Figured out lower standby power from the low-power tutorial: http://www.sparkfun.com/tutorials/309
* Corrected #define TRUE to built-in supported 'true'
* Re-arranged some functions
* Migrating to Uno bootloader to get an additional 1500 bytes of program space
* Replumbed everything to get away from hardware UART
* Reduced # of sub directory support from 15 levels to 2 to allow for more RAM
* Wildcard remove is supported in v3.1
* Wildcard is supported in v3.2
* [Remove] efcount and efinfo is not yet supported in v3.0

Testing at 115200. First test with clean/empty card. The second test is with 193MB across 172 files on the microSD card.

* 1GB: 333075/333075, 333075/333075
* 8GB: 333075/333075, 333075/333075
* 16GB: 333075/333075, 333075/333075

The card with tons of files may have problems. Whenever possible, use a clean, empty, freshly formatted card.

Testing at 57600. First test with clean/empty card. The second test is with 193MB across 172 files on the microSD card.

* 1GB: 111075/111075, 111075/111075
* 8GB: 111075/111075, 111075/111075
* 16GB: 111075/111075, 111075/111075

The card with tons of files may have problems. Whenever possible, use a clean, empty, freshly formatted card.

## [2.51] June 1 2011

Improved command prompt parsing (now ignores '\n')
 
We now ignore the \n character when parsing characters from the command prompt. This makes it easier to create code on a microcontroller that correctly controls OpenLog. Previously, println or sprintf commands were adding a \n to the end of the string that would confuse OpenLog. One way around this if you have previous versions is this 

    sprintf(buff, "new blah.txt\r");
    Serial.print(buff); //No println, use \r in string instead

Also - added a CommandTest sketch to demonstrate how you can control OpenLog from a microcontroller / automate the command prompt

## [2.5] February 2 2011

28,782 bytes compiled

Improved 'read' command. Added 'reset' command.

Modified the read command so that we can print extended ASCII characters. The function was also failing to print any value over 127 (limited to signed 8 bits - boo). Thank you @wilafau! You proposed excellent, easy fixes.

Added raw command during print operation. This allows for non-visible and extended ASCII characters to be printed correctly, if need be.
 
Issuing 'reset' command causes OpenLog to reset and re-read the config file. This is important if you want to change the config file then restart.
 
Removed some of the extraneous prints from the help menu to save on space.

## [2.41]

29,124 bytes compiled (yikes)

Power loss bug fixed. Adding support for 38400bps for testing with SparkFum 9DOF IMU logging. 

Found a bug in the append_file routine. If the unit is actively logging, file.writes are flying by quickly. But if OpenLog loses power, none of the data is recorded because there is no file.sync. Data would only get recorded if the unit went idle or if user entered escape command. This has since been fixed with two file.sync() commands.

## [2.4] November 17 2010

29,028 bytes compiled (yikes)

Merged @ringp updates. Commands cd, rm, ls work again! New "rm -rf" command to remove directory and its files. Thanks ringp! Great work.
 
Remember - we had to completely butcher HardwareSerial.cpp so a normal Arduino installation will not work. 

C:\arduino-xxxx\hardware\arduino\cores\arduino\HardwareSerial.cpp

I've added the modified HardwareSerial.cpp to the repo.
 
Testing at 57600

* 1GB: 110490/111000, 110490/111000
* 8GB: 111000/111000, 111000/111000, 111000/111000
* 16GB: 83890/111000, 84908/111000

The 16GB card with tons of files continue to have problems but the other cards (FAT and FAT32) are acceptable. Whenever possible, use a clean, empty, freshly formatted card.
 
To remove a directory and all its files:

    rm -rf mydirectory
 
Windows 7 stores the Arduino hex file in an awful place. Something like:

    C:\Users\Main\AppData\Local\Temp\build3390340147786739225.tmp\OpenLog_v2.cpp.hex
 
Added HardwareSerial.cpp and a readme to the main trunk.
Added OpenLog_v2.cpp.hex to the main trunk.

## [2.3]

27,334 bytes compiled

Migrated to v10.10.10 of sdfatlib. Moved to inline RX interrupt and buffer. Improved the ability to receive a constant stream at 57600bps.
 
Remember - we had to completely butcher HardwareSerial.cpp so a normal Arduino installation will not work. 
C:\arduino-xxxx\hardware\arduino\cores\arduino\HardwareSerial.cpp
 
I removed the receive interupt handler from HardwareSerial.cpp so that we can deal directly with USART_RX_vect in the main code. This allows us to return to the way OpenLog used to operate - by having one buffer split in half. Once one half fills, it is recorded to SD while the other half fills up. This dramatically decreases the time spent in function calls and SD recording, which leads to many fewer characters dropped.

The change log at the top of the main code got so large I've moved it to a version controlled "Changes.txt" file.

By making all these changes, I have broken many things. Ringp - I could use your help here. I apologize for stomping on so much of your work. I was not good enough to figure out how to re-link from the old function calls to the new sdfatlib setup.
 
Backspace is broken - ringp, I saw this fix in one of your commits, but looking at the code, I don't see how it is supposed to work. Either way, we still get 0x08 when trying to backspace.
 
New sdfatlib doesn't have SdFat.cpp so fileInfo doesn't work. These function calls are marked with //Error
 
I have chosen to dis-allow deprecated functions: #define ALLOW_DEPRECATED_FUNCTIONS 0
This forced some trivial changes to the SD write and new file creation function calls. I believe we've successfully migrated to the new version of sdfatlib.
 
In the command_shell / read_line function : It may be better to pull directly from the UART buffer and use the RX interrupt. For now, we brute force it.
 
Because of all these changes, I need to re-test power consumption. For now, I'm confident it's low enough.
 
Testing with 512 buffer array size

* 1GB @ 57600 - dropped very little out of 3 tests
* 1GB @ 115200 - dropped very little out of 2 tests
* 8GB @ 57600 - Formatted using the sd formater (32k byte allocation size). Dropped nothing.
* 8GB @ 115200 - dropped very little, dropped none
* 16GB w/ Lots of files @ 57600 - Drops the first part of the file because of start up delay?
* 16GB w/ Lots of files @ 115200
 
1024 array size (and 800) does not run
 
Testing with 700 buffer array size

* 1GB @ 57600 - 110300 out of 111000 bytes, 110300/111000,
* 1GB @ 115200 - 111000/111000!, 109600/111000
* 8GB @ 57600 - 109000/111000, 111000/111000!,
* 8GB @ 115200 - 111000/111000!, 111000/111000!,
* 16GB w/ Lots of files @ 57600 - 85120/111000, 85120/111000
* 16GB w/ Lots of files @ 115200 - 56420 (but once it got going, log looks good). 56420.
 
I am seeing long delays on cards with lots of files. In the above tests, the 16GB test card is a good example. It has 2GB worth of random files in a sub directory.

After OpenLog boots, goes to '12<'. After I send ~500 characters OpenLog freezes for a couple seconds, then returns to normal, very fast, operation. During that down time, I believe sdfatlib is searching for an open cluster. The odd thing is that after the cluster is established (after the initial down time) OpenLog performs excellently. I am hoping to create a faux file or pre-write and save to the file or some how get this allocation done before we report the '12<' indicating we are ready. That way, if a card does fill up, as long as the host system is checking for '<', it doesn't matter how long it takes sdfatlib to find the next free cluster.
 
You can see that we drop 700 bytes at a time. That's a bit odd - I'd expect to drop half or 350 at a time. What happens if we shrink the array size to say 256? To be expected, this is bad - way more instances of dropped characters.
 
Added blink for each test to the OpenLog_Test sketch so we can see as the test progresses.
 
http://www.sdcard.org/consumers/formatter/ is the site for SD card formatting. It looks like this program takes a guess at the correct block size. This could help a lot in the future.

## [2.21]

28,440 bytes compiled

ringp fork brought in. Wildcard remove and list commands now work. Remove directory now works! Change directory up/down the tree works again.
 
ringp brought back many great commands! Thanks ringp!

* rm LOG*.* works
* ls *.TXT works
* cd .. works again
* ls now correctly shows directories first and files following the directories.
 
To remove a directory, you have to navigate into that directory. For example:

    >cd TEMP (you are now in TEMP directory)
    >rm -f TEMP (you are now removing TEMP, and you will be pushed back down one level of the tree)
    >ls (shows files and directories where TEMP directory used to be, but TEMP directory should be gone)
 
ringp added new commands:

* efcount: gives the number of files in the current directory. Example: "efcount" returns "count|3". There are 3 files in the current directory.
* efinfo <spot>: gives info about the file in <spot>. Example: "efinfo 2" reports "LOG00588.TXT|45". File number 2 is named LOG00588.TXT and is 45 bytes in size.
* verbose <"on"|"off">: sets whether command errors are verbose (long winded) or just the "!" character. Example: "verbose off" sets verbose off. Then if a command like "blah" is received, then only "!>" is seen from the command line interface. This makes it easier for embedded systems to recognize there was an error. This setting is not recorded to EEPROM.

## [2.2]

Modified append_file() to use a single buffer. Increased HardwareSerial.cpp buffer to 512 bytes.
 
More testing at 57600. Record times look to be 2, 5, and zero milliseconds when doing a record. This means that the split buffer doesn't really make a difference? There are some records that take 150ms, 14ms, etc. At 57600bps, that's 7200 bytes/s, 138us per byte. With a 150ms pause, that's 1,086 bytes that need to be buffered while we wait... Grrr. Too many.
 
I re-wrote the append_file function to use only one buffer. This allows us to more quickly pull data from the hardware serial buffer. Hardware serial buffer has to be increased manually to 512. This file (hardwareserial.cpp) is stored in the Arduino directory. With testing, it seems like recording is working more solidly at 57600bps. But now I'm seeing glitches at 19200bps so more testing is required before we make this the official OpenLog release.
 
Moved input_buffer into within the append function. Attempting to shave bytes of RAM.

## [2.11]

26,136 bytes compiled out of 30,720

Tested with 16GB microSD. Fixed some general bugs. Lowered power consumption.
 
Fixed issue #30. I added printing a period ('.') for non-visible ASCII characters during a 'read' command. This cleans up the output a bit. HEX printing is still available. 
 
Fixed issue #34. When issuing a long command such as "read log00056.txt 100 200 2" (read from spot 100 to spot 200 and print in HEX), the command shell would die at 24 spots. I increased both the general_buffer and 'buffer' in the command shell from 24 to 30. The limit is now 30 characters, so "read log00056.txt 100 20000 2" is allowed.
 
Works with a 16GB microSD card! High volume test: loaded 16GB card with 5GB of data. Basic serial tests work. When running at 57600, there is an odd delay. I think it has to do with the file system doing an initial scan for an available cluster. Takes 2-3 seconds before OpenLog returns to normal. This can cause significant data loss.
 
Fixing power management in v2. Power down after no characters for 3 seconds now works. Unit drops to 2.35mA in sleep. 7.88mA in sitting  RX mode (awake but not receiving anything). There is still a weird bug where the unit comes on at 30mA. After sleep, it comes back at the correct 7-8mA. Is something not getting shut off?

## [2.1]

26,058 bytes out of 30,720

Power save not working. Fixed issue #35. Dropping characters at 57600bps. 

Fixed a bug found by Salient issue #35. User settings where declared at chars which allowed them to be signed. If a user went from old firmware, to v2, the safety checks would fail because the settings would be read at -1 instead of 255. Declaring user settings as byte fixed issue.
 
Added "a) Clear user settings" to set menu. This allows us to completely wipe an OpenLog (user settings and config file) to see how it will respond to future firmware changes.
 
Improved the file 'size' command.
 
Sequential logging is tested and works.
 
Receive testing: Using the Test_Sketch found on Github, I am testing the receive reliability at different UART speeds.

We need to test a lot of received data. At 57600, 115200, and both from an Arduino (lots of time in between characters becuase of software overhead) and from a raw serial port (almost no time in between characters). I am hoping to make sdfatlib hiccup at 115200, full speed, across a 1MB file. If I can make it fail, then we can start to increase the buffer size and look at how much RAM sdfatlib has left open for the buffer.
 
* 9600bps from Arduino works fine
* 57600bps from Arduino drops characters
* 115200 from Arduino drops characters

It seems that sdfatlib takes longer to write to the SD card than the original file system from Robert Reigel. I'm thinking perhaps we should create a version of OpenLog firmware that is just sequantial logging, no fancy system menus... It might open up some RAM.
 
If only we could get control of the UART from Arduino's clutches, we could probably handle the ring buffer much better. Not sure how to handle UART interrupts without tearing out HardwareSerial.cpp.
 
Added README to the Test sketch. Added 115200bps to test sketch.

## [2.0]

25,986 bytes out of 30,720

Welcome to version 2! We've moved from Roland Riegel's FAT library to Bill Greiman's sdfatlib. OpenLog now works with SD cards up to 16GB (that is the current largest microSD card we can get our hands on). OpenLog automatically detects and works with FAT16/FAT32 file systems. It also automatically works with normal SD cards as well as SDHC cards.
 
Almost all the previous commands have been ported from v1 to v2. The current commands that do not work:

* cd.. - does not work. You can change to an upper directory, but you cannot navigate back down the tree.
* cat - this command was depricated. HEX printing is now done with the 'read' command. We've added a 5th argument to select between ASCII and HEX printing.
* Wild cards do not yet work. So rm and ls do not have wild cards enabled - yet. Help us out!
 
Porting OpenLog to work directly under Arduino to work with sdfatlib (http://code.google.com/p/sdfatlib/) by Bill Greiman.
 
sdfatlib intrinsically supports FAT16, FAT32 as well as SD and HCSD cards. In a word, it's amazing.
 
Needs to be done:

* (Done) Get config file reading/loading working
* Document config file in wiki: if no config file is found, current system settings are used. If config is found, system switches to settings found in file. If system settings are changed, then config file is changed and system uses new settings immediately.
* (Done) We don't want to constantly record a new config file on each power on. Only record when there is a change.
* Get cd.. working
* Seperate OpenLog_v2 into multiple files
* Re-test too many log files created in the newlog setting - 65535. Potentially create thousands of files and see how sdfatlib handles it.
* (Done) Test sequential logging.
* Get wild card support working for ls and rm
* Get backspace working
* Test rm with directories, and directory wildcards? Maybe not.
* Get power save working
* Test compile on a computer that doesn't have WinAVR
 
Test commands:

* new - works, also in sub dirs
* append - works, also in sub dirs
* rm - works, but does not yet support wild cards.
* md - works, also in sub dirs
* cd - you can change up to a sub-directory, but you cannot navigate back down the tree. The current work around is to type 'init'. This will re-init the card and set the directory back to root.
* ls - works pretty well but does not yet support wild cards. Shows directories, files, and file sizes. Would be cool if it listed dirs first.
* read - works well. Tested 0, 1, 2, 3, 4, and 5 arguments (included and left off). Fails gracefully. Now prints in HEX as well!
* size - works well
* disk - works well, prints more information than ever before!
* init - works well
* sync - works, but not really tested
* cat - I've decided to drop this command. You can now print in hex using the read command and using a 5th argument as '1' for ASCII (default) and '2' for HEX.
* set - works well
* baud - works well

## [1.61]

Small PCB change. Fixed version # in help menu.
 
Fixed the firmware version in the help menu to v1.61.
 
Updated Eagle files to Eagle v5.9. Fixed weird airwire. Changed D1 LED from Green to Blue. Will only affect new production after 4-28-10.
 
Closed some tickets and wrote some more example Arduino code: http://forum.sparkfun.com/viewtopic.php?t=21438

## [1.6]

Adding config file.
 
What happens if I reset the system by pulling RX low, but the config file has corrupt values in it?
 
If config file has corrupt values in it, system will default to known values 9600/ctrl+z/3/newlog
 
If config file is empty, system resets to known values
 
After some massive testing, and lots of code to check for illegal states, it looks to be pretty stable. The only problem is that we're running out of RAM. The buffer had to be decreased from 900 bytes to 700 bytes to facilitate all the config file checking. Testing at 57600bps, unit runs very well over 40kb test file on straight RS232 connection. That's pretty good. Testing at 115200 on straight  connection, unit will drop a buffer every once and a while. Not great, but not much we can do if the SD card times out for ~150ms while it's writing. 8 bits to the byte plus a start/stop bit = 10 bits per byte
 
* 9600bps = 960 bytes per second. Buffer will last for 729ms
* 57600bps = 5760 bytes per second. Buffer will last for 121ms
* 115200bps = 11520 bytes per second. Buffer will last for 60.7ms
 
So if the SD card pauses for more than 60ms, 115200 will have lost data, sometimes. All other baud rates should be covered for the most part.
 	
SD cards with larges amounts of data will have increased pause rates. Always use a clean card where possible.

## [1.51]

check_emergency_reset, default break character is ctrl+z 3 times, example Arduino sketch
 
Added function from @mungewell - check_emergency_reset. This has improved testing of the RX pin. There was potential to get a false baud reset. There is still a chance but it's now much less likely.
 
If OpenLog is attached to a Arduino, during bootloading of the Arduino, ctrl+z will most likely be sent to the Arduino from the computer. This character will cause OpenLog to drop to command mode - probably not what we want. So I added user selectable character (ctrl+x or '$' for example) and I added user selectable number of escape characters to look for in a row (example is 1 or 2 or 3, '$$$' is a common escape sequence). The default is now ctrl+z sent 3 times in a row.
 
Added an example Arduino sketch (from @ScottH) to GitHub so that people can easily see how to send characters to OpenLog. Not much to it, but it does allow us to test large amounts of text thrown at OpenLog at 57600bps.
 
## [1.5]

Added 4800bps and 19200bps support
 
Added power saving features. Current consumption at 5V is now:

In default append mode: 

* 6.6/5.5mA while receiving characters (LED On/Off)
* 2.1mA during idle

In command mode: 

* 3.2/2.1mA (LED On/Off)
 
So if you're actively throwing characters at the logger, it will be ~6mA. If you send the logger characters then delay 5-10 seconds, current will be ~2.5mA. (Unit records the characters in the buffer and goes into idle more if no characters are received after 5 seconds)
 
These power savings required some significant changes to uart.c / uart_getc()

## [1.4]

Added exit options to the two menus (set and baud)
Also added display of current settin to two menus (Ex: "Baud currently: 57600bps")
 
Added '!' infront of 'error opening'. This pops up if there is an error while trying to append to a freshly created new log (ex: LOG00548.txt is created, then errors out because it cannot append). '!' was added so that user can parse against it.
 
Replicated logging errors at 57600 using 5V Arduino. Unit would systematically glitch during logging of 111054 bytes.
 
Increasing buffer to 1000 characters caused URU error. URU: Unit Resets Unexpectedly
 
To recreate URU error. Type "append ". Include the space. If you get "!error opening", then things are fine. If you get "!error opening#" where # is a weird character, then type 'ls' and the unit will unexpectedly reset (URU error). I believe this is attributed to a memory overrun somewhere in the FAT system.
 
Changed buffer size to 900 and declared the character buffer as volatile

    #define BUFF_LEN 900
    volatile char input_buffer[BUFF_LEN];
 
This increase to the buffer allows for clean logging of 444055 bytes with no URU errors.
 
Experimenting with Scott's SD cards (customer gave cards on loan for recreating logging errors):

* Card with single ~740mb file produces errors when trying to open/append to new log. 
* Card with less stuff on it logs full 444055 bytes correctly.

## [1.3]

Added sd_raw_sync() inside append_file. I believe this was why tz1's addition of the timeout buffer update feature was not working. Auto buffer update now working. So if you don't send anything to OpenLog for 5 seconds, the buffer will automatically record/update.
 
Need to create 'Testing' page to outline the battery of tests we need to throw at any OpenLog after a firmware submission and update is complete.
 
Testing create 40,000 logs
 
Record at full speed: Run at full 115200, load lotsoftext.txt and verify no characters are dropped.
 
Detect too many logs: Create new log at 65533 (do this by editing 'zero' function to set EEPROM to 0xFF and oxFD) and power cycle. Verify unit starts new log. Power cycle and verify unit errors out and drops to command prompt.
 
Record buffer after timeout: Create new log. Type 20 characters and wait 5 seconds. Unit should auto-record buffer. Power down unit. Power up unit and verify LOG has 20 characters recorded.	

## [1.2]

@ringp added:

* Adding support for splitting command line parameters into arguments
* Adding support for reading files sequencially
** read <filename> <start> <length>
* New log now for sequencial log functions supports 0-65535 files
* Adding support for wildcard listing or deletion of files
** ls <wildcard search>
** rm <wildcard delete>
 
Really great additions. Thanks ringp!
 
Nate added error testing within newlog(). Checks to see if we have 65534 logs. If so, error out to command prompt with "!Too many logs:1"
 
## [1.1]

Adding better defines for EEPROM settings
Adding new log and sequential log functions.
 
Code is acting very weird with what looks to be stack crashes. I can get around this by turning the optimizer off ('0'). Found an error : EEPROM functions fail when optimizer is set to '0' or '1'. sd-reader_config.h contains flag for USE_DYNAMIC_MEMORY
 
Looks like tweaking the optimization higher causes the asm("nop"); to fail inside the append_file routine. Changing this to delay_us(1); works.
 
I have a sneaking suspicion that I was having buffer overrun problems when defining the input_buffer at 1024 bytes. The ATmega328 should have enough RAM (2K) but weird reset errors were occuring. With the buffer at 512bytes, append_file runs just fine and is able to log at 115200 at a constant data rate.
 
Added file called 'lots-o-text.txt' to version control. This text contains easy to scan text to be used for full data rate checking and testing.
 
## [1.0] December 3 2009

Original version written in C.

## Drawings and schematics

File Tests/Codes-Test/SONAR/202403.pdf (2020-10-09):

## www.Jameco.com ✦ 1-800-831-4242

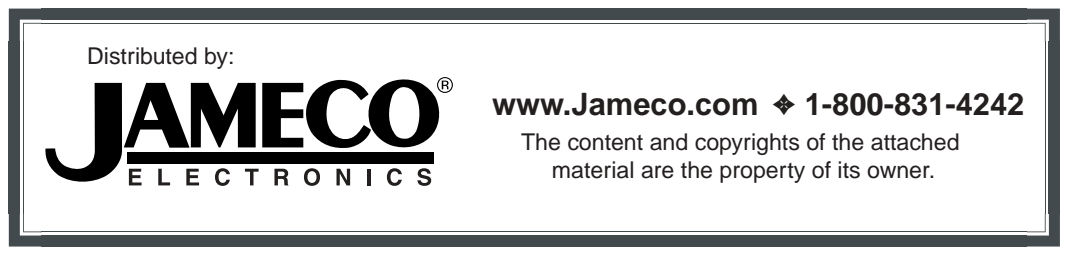
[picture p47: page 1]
Distributed by:

The content and copyrights of the attached
material are the property of its owner.

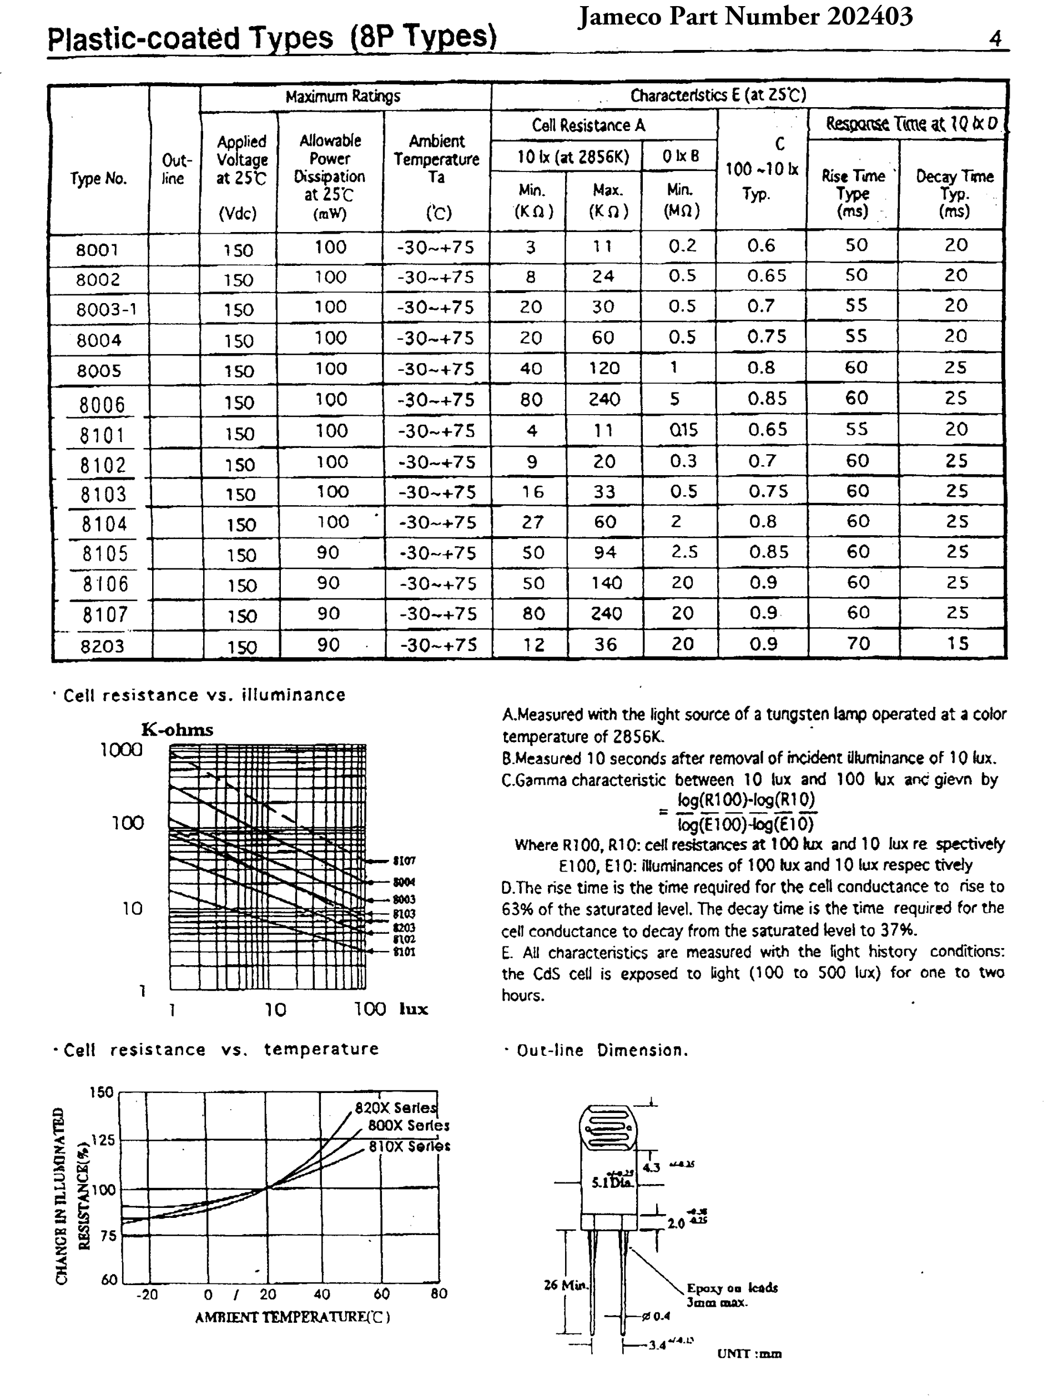
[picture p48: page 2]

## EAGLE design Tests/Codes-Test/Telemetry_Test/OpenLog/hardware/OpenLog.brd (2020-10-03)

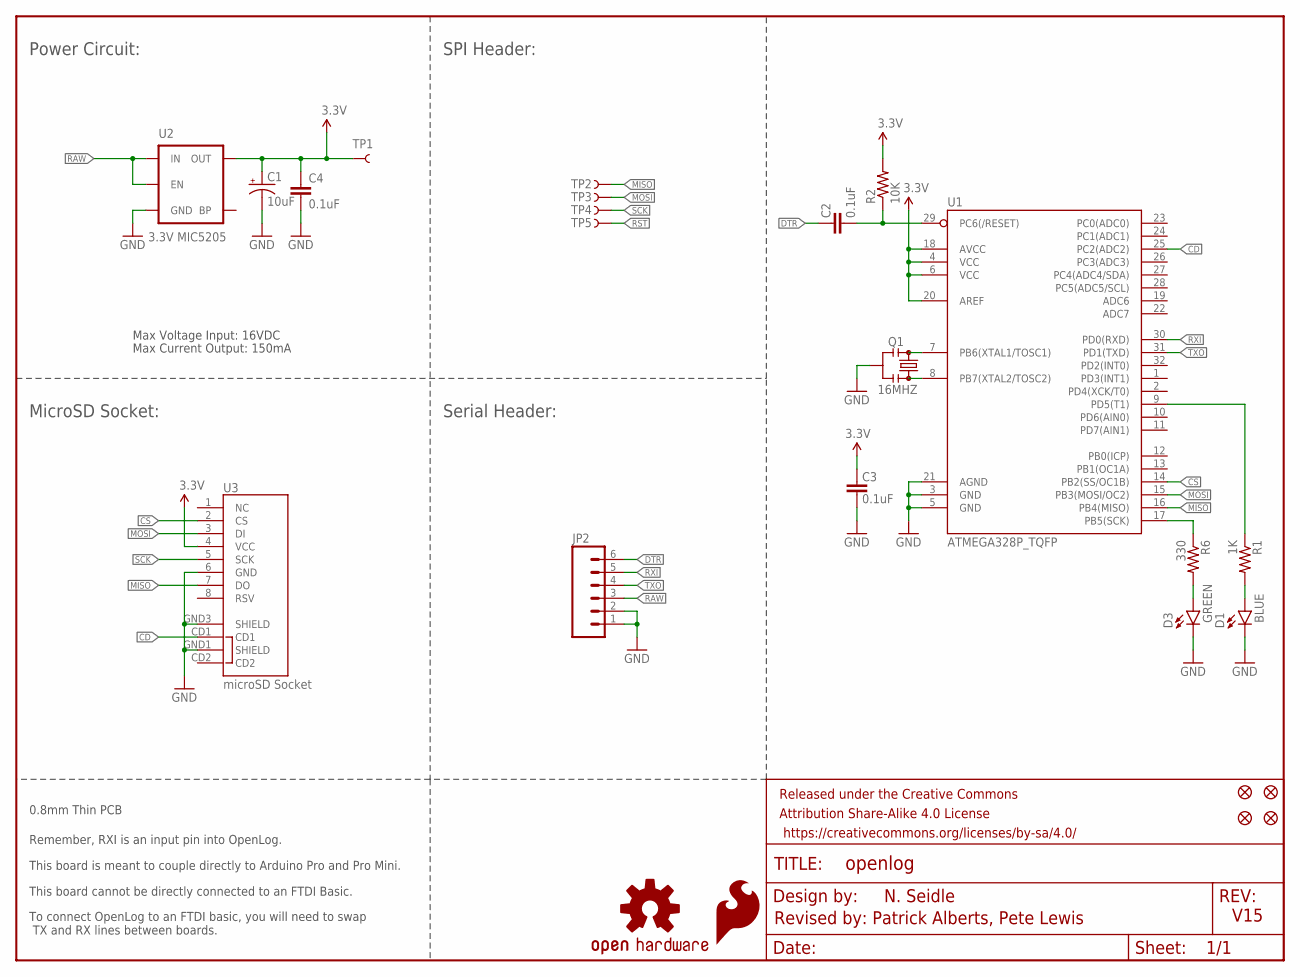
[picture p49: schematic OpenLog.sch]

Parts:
C1: 10uF; 0603-POL
C2, C3, C4: 0.1uF; 0603-CAP
D1: BLUE; LED-0603
D3: GREEN; LED-0603
FID1, FID2, FID3, FID4: FIDUCIALUFIDUCIAL; MICRO-FIDUCIAL
FRAME1: FRAME-LETTER; CREATIVE_COMMONS
JP2: M06NO_SILK_FEMALE_PTH; 1X06_NO_SILK
LOGO1: SFE_LOGO_FLAME.1_INCH; SFE_LOGO_FLAME_.1
LOGO2: OSHW-LOGOMINI; OSHW-LOGO-MINI
Q1: 16MHZ; RESONATOR-SMD
R1: 1K; 0603-RES
R2: 10K; 0603-RES
R6: 330; 0603-RES
TP1, TP2, TP3, TP4, TP5: TEST-POINT3; PAD.03X.03
U1: ATMEGA328P_TQFP; TQFP32-08
U2: 3.3V MIC5205; SOT23-5
U3: microSD Socket; MICROSD_1:1

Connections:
3.3V: C1.A (+), C3.2, C4.1, R2.2, TP1.P$1, U1.4 (VCC), U1.6 (VCC), U1.18 (AVCC), U1.20 (AREF), U2.5 (OUT), U3.4 (VCC)
CD: U1.25 (PC2(ADC2)), U3.CD1
CS: U1.14 (PB2(SS/OC1B)), U3.2 (CS)
DTR: C2.2, JP2.6
GND: C1.K (-), C3.1, C4.2, D1.C, D3.C, JP2.1, JP2.2, Q1.2, U1.3 (GND), U1.5 (GND), U1.21 (AGND), U2.2 (GND), U3.6 (GND), U3.GND1 (SHIELD), U3.GND3 (SHIELD)
MISO: TP2.P$1, U1.16 (PB4(MISO)), U3.7 (DO)
MOSI: TP3.P$1, U1.15 (PB3(MOSI/OC2)), U3.3 (DI)
unnamed: Q1.1, U1.8 (PB7(XTAL2/TOSC2))
unnamed: Q1.3, U1.7 (PB6(XTAL1/TOSC1))
unnamed: D1.A, R1.2
unnamed: R1.1, U1.9 (PD5(T1))
unnamed: D3.A, R6.2
RAW: JP2.3, U2.1 (IN), U2.3 (EN)
RST: C2.1, R2.1, TP5.P$1, U1.29 (PC6(/RESET))
RXI: JP2.5, U1.30 (PD0(RXD))
SCK: R6.1, TP4.P$1, U1.17 (PB5(SCK)), U3.5 (SCK)
TXO: JP2.4, U1.31 (PD1(TXD))

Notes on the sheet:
Max Voltage Input: 16VDC
Max Current Output: 150mA
Remember, RXI is an input pin into OpenLog.
This board is meant to couple directly to Arduino Pro and Pro Mini.
This board cannot be directly connected to an FTDI Basic.
To connect OpenLog to an FTDI basic, you will need to swap TX and RX lines between boards.
V15
N. Seidle
Revised by: Patrick Alberts, Pete Lewis
0.8mm Thin PCB
Power Circuit:
Serial Header:
MicroSD Socket:
SPI Header:

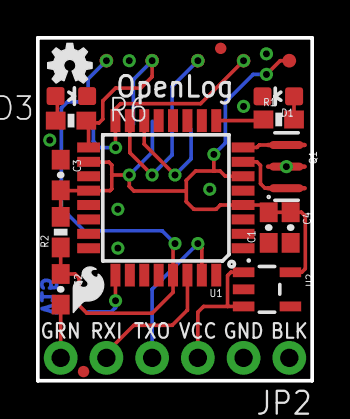
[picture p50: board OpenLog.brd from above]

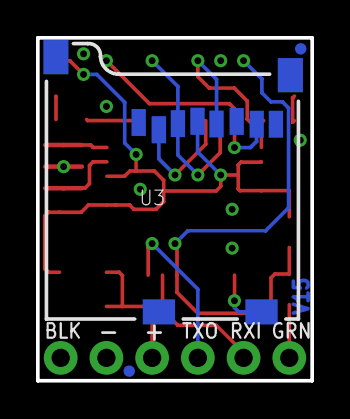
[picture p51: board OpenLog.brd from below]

Board: 2 copper layers, 15.2 x 19.1 mm, 26 parts (3 on the bottom side), 17 nets.

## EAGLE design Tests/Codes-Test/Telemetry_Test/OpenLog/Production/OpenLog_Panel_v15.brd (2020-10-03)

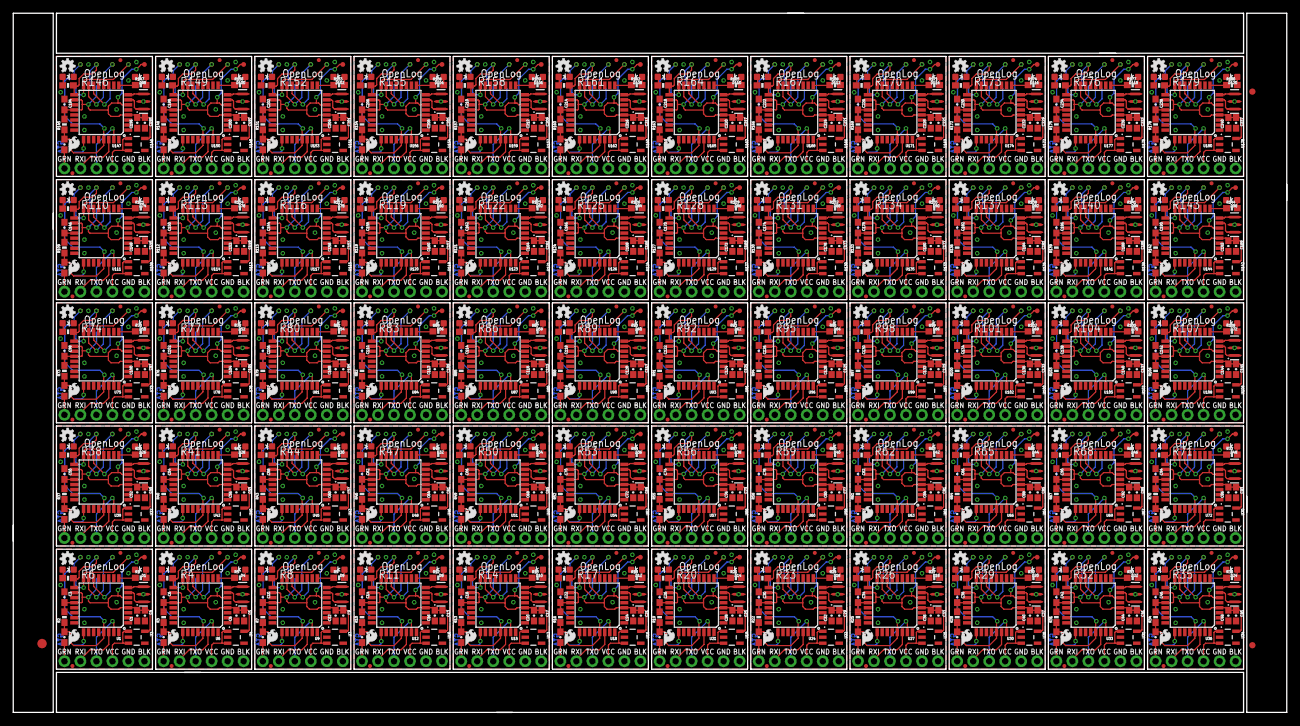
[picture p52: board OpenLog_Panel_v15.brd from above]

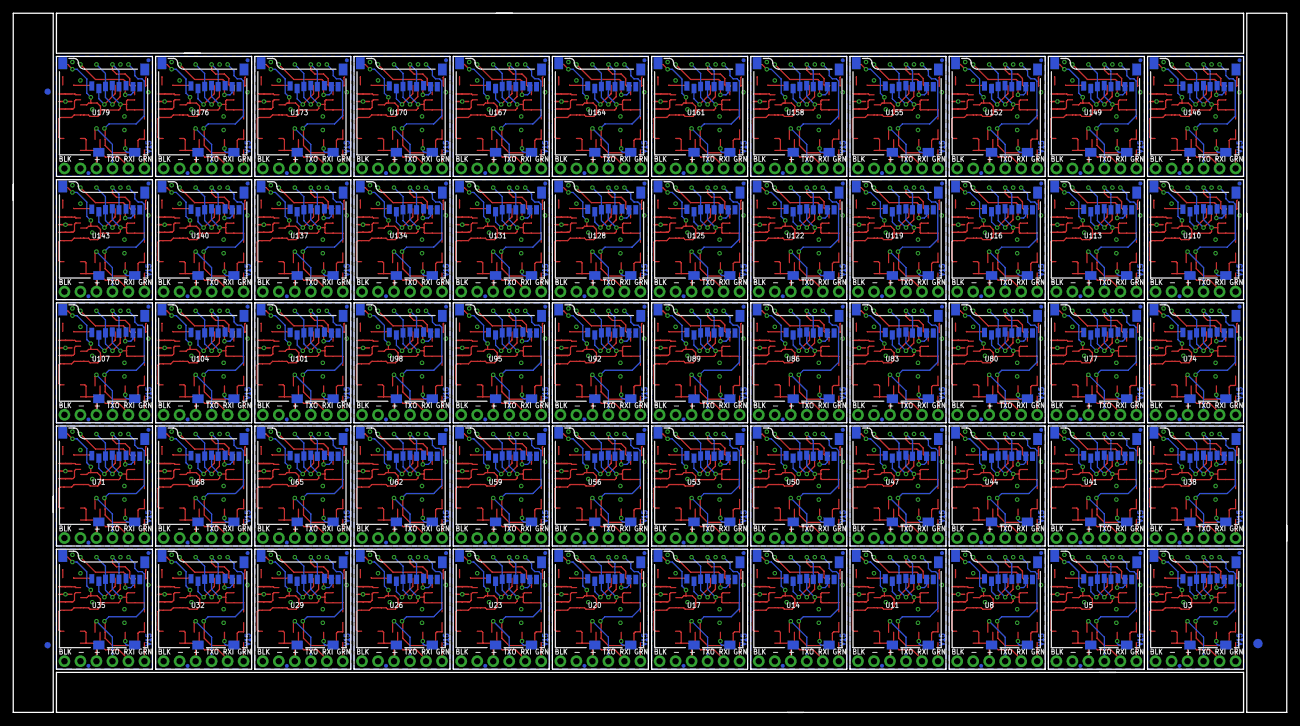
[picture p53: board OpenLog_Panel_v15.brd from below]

Board: 2 copper layers, 202.2 x 111.0 mm, 1506 parts (183 on the bottom side), 1020 nets.

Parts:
C1, C8, C12, C16, C20, C24, C28, C32, C36, C40, C44, C48, C52, C56, C60, C64, C68, C72, C76, C80, C84, C88, C92, C96, C100, C104, C108, C112, C116, C120, C124, C128, C132, C136, C140, C144, C148, C152, C156, C160, C164, C168, C172, C176, C180, C184, C188, C192, C196, C200, C204, C208, C212, C216, C220, C224, C228, C232, C236, C240: 10uF; 0603-POL
C2, C3, C4, C5, C6, C7, C9, C10, C11, C13, C14, C15, C17, C18, C19, C21, C22, C23, C25, C26, C27, C29, C30, C31, C33, C34, C35, C37, C38, C39, C41, C42, C43, C45, C46, C47, C49, C50, C51, C53, C54, C55, C57, C58, C59, C61, C62, C63, C65, C66, C67, C69, C70, C71, C73, C74, C75, C77, C78, C79, C81, C82, C83, C85, C86, C87, C89, C90, C91, C93, C94, C95, C97, C98, C99, C101, C102, C103, C105, C106, C107, C109, C110, C111, C113, C114, C115, C117, C118, C119, C121, C122, C123, C125, C126, C127, C129, C130, C131, C133, C134, C135, C137, C138, C139, C141, C142, C143, C145, C146, C147, C149, C150, C151, C153, C154, C155, C157, C158, C159, C161, C162, C163, C165, C166, C167, C169, C170, C171, C173, C174, C175, C177, C178, C179, C181, C182, C183, C185, C186, C187, C189, C190, C191, C193, C194, C195, C197, C198, C199, C201, C202, C203, C205, C206, C207, C209, C210, C211, C213, C214, C215, C217, C218, C219, C221, C222, C223, C225, C226, C227, C229, C230, C231, C233, C234, C235, C237, C238, C239: 0.1uF; 0603-CAP
D1, D4, D6, D8, D10, D12, D14, D16, D18, D20, D22, D24, D26, D28, D30, D32, D34, D36, D38, D40, D42, D44, D46, D48, D50, D52, D54, D56, D58, D60, D62, D64, D66, D68, D70, D72, D74, D76, D78, D80, D82, D84, D86, D88, D90, D92, D94, D96, D98, D100, D102, D104, D106, D108, D110, D112, D114, D116, D118, D120: BLUE; LED-0603
D2, D3, D5, D7, D9, D11, D13, D15, D17, D19, D21, D23, D25, D27, D29, D31, D33, D35, D37, D39, D41, D43, D45, D47, D49, D51, D53, D55, D57, D59, D61, D63, D65, D67, D69, D71, D73, D75, D77, D79, D81, D83, D85, D87, D89, D91, D93, D95, D97, D99, D101, D103, D105, D107, D109, D111, D113, D115, D117, D119: GREEN; LED-0603
E$1, E$2: FIDUCIAL-1.5X3
E$3, E$4, E$7, E$8: FIDUCIAL-1X2
FID1, FID2, FID3, FID4, FID5, FID6, FID7, FID8, FID9, FID10, FID11, FID12, FID13, FID14, FID15, FID16, FID17, FID18, FID19, FID20, FID21, FID22, FID23, FID24, FID25, FID26, FID27, FID28, FID29, FID30, FID31, FID32, FID33, FID34, FID35, FID36, FID37, FID38, FID39, FID40, FID41, FID42, FID43, FID44, FID45, FID46, FID47, FID48, FID49, FID50, FID51, FID52, FID53, FID54, FID55, FID56, FID57, FID58, FID59, FID60, FID61, FID62, FID63, FID64, FID65, FID66, FID67, FID68, FID69, FID70, FID71, FID72, FID73, FID74, FID75, FID76, FID77, FID78, FID79, FID80, FID81, FID82, FID83, FID84, FID85, FID86, FID87, FID88, FID89, FID90, FID91, FID92, FID93, FID94, FID95, FID96, FID97, FID98, FID99, FID100, FID101, FID102, FID103, FID104, FID105, FID106, FID107, FID108, FID109, FID110, FID111, FID112, FID113, FID114, FID115, FID116, FID117, FID118, FID119, FID120, FID121, FID122, FID123, FID124, FID125, FID126, FID127, FID128, FID129, FID130, FID131, FID132, FID133, FID134, FID135, FID136, FID137, FID138, FID139, FID140, FID141, FID142, FID143, FID144, FID145, FID146, FID147, FID148, FID149, FID150, FID151, FID152, FID153, FID154, FID155, FID156, FID157, FID158, FID159, FID160, FID161, FID162, FID163, FID164, FID165, FID166, FID167, FID168, FID169, FID170, FID171, FID172, FID173, FID174, FID175, FID176, FID177, FID178, FID179, FID180, FID181, FID182, FID183, FID184, FID185, FID186, FID187, FID188, FID189, FID190, FID191, FID192, FID193, FID194, FID195, FID196, FID197, FID198, FID199, FID200, FID201, FID202, FID203, FID204, FID205, FID206, FID207, FID208, FID209, FID210, FID211, FID212, FID213, FID214, FID215, FID216, FID217, FID218, FID219, FID220, FID221, FID222, FID223, FID224, FID225, FID226, FID227, FID228, FID229, FID230, FID231, FID232, FID233, FID234, FID235, FID236, FID237, FID238, FID239, FID240: FIDUCIALUFIDUCIAL; MICRO-FIDUCIAL
JP1, JP2, JP3, JP4, JP5, JP6, JP7, JP8, JP9, JP10, JP11, JP12, JP13, JP14, JP15, JP16, JP17, JP18, JP19, JP20, JP21, JP22, JP23, JP24, JP25, JP26, JP27, JP28, JP29, JP30, JP31, JP32, JP33, JP34, JP35, JP36, JP37, JP38, JP39, JP40, JP41, JP42, JP43, JP44, JP45, JP46, JP47, JP48, JP49, JP50, JP51, JP52, JP53, JP54, JP55, JP56, JP57, JP58, JP59, JP60: 1X06_NO_SILK
LOGO1, LOGO3, LOGO5, LOGO7, LOGO9, LOGO11, LOGO13, LOGO15, LOGO17, LOGO19, LOGO21, LOGO23, LOGO25, LOGO27, LOGO29, LOGO31, LOGO33, LOGO35, LOGO37, LOGO39, LOGO41, LOGO43, LOGO45, LOGO47, LOGO49, LOGO51, LOGO53, LOGO55, LOGO57, LOGO59, LOGO61, LOGO63, LOGO65, LOGO67, LOGO69, LOGO71, LOGO73, LOGO75, LOGO77, LOGO79, LOGO81, LOGO83, LOGO85, LOGO87, LOGO89, LOGO91, LOGO93, LOGO95, LOGO97, LOGO99, LOGO101, LOGO103, LOGO105, LOGO107, LOGO109, LOGO111, LOGO113, LOGO115, LOGO117, LOGO119: SFE_LOGO_FLAME.1_INCH; SFE_LOGO_FLAME_.1
LOGO2, LOGO4, LOGO6, LOGO8, LOGO10, LOGO12, LOGO14, LOGO16, LOGO18, LOGO20, LOGO22, LOGO24, LOGO26, LOGO28, LOGO30, LOGO32, LOGO34, LOGO36, LOGO38, LOGO40, LOGO42, LOGO44, LOGO46, LOGO48, LOGO50, LOGO52, LOGO54, LOGO56, LOGO58, LOGO60, LOGO62, LOGO64, LOGO66, LOGO68, LOGO70, LOGO72, LOGO74, LOGO76, LOGO78, LOGO80, LOGO82, LOGO84, LOGO86, LOGO88, LOGO90, LOGO92, LOGO94, LOGO96, LOGO98, LOGO100, LOGO102, LOGO104, LOGO106, LOGO108, LOGO110, LOGO112, LOGO114, LOGO116, LOGO118, LOGO120: OSHW-LOGOMINI; OSHW-LOGO-MINI
Q1, Q2, Q3, Q4, Q5, Q6, Q7, Q8, Q9, Q10, Q11, Q12, Q13, Q14, Q15, Q16, Q17, Q18, Q19, Q20, Q21, Q22, Q23, Q24, Q25, Q26, Q27, Q28, Q29, Q30, Q31, Q32, Q33, Q34, Q35, Q36, Q37, Q38, Q39, Q40, Q41, Q42, Q43, Q44, Q45, Q46, Q47, Q48, Q49, Q50, Q51, Q52, Q53, Q54, Q55, Q56, Q57, Q58, Q59, Q60: 16MHZ; RESONATOR-SMD
R1, R4, R5, R6, R8, R9, R11, R12, R14, R15, R17, R18, R20, R21, R23, R24, R26, R27, R29, R30, R32, R33, R35, R36, R38, R39, R41, R42, R44, R45, R47, R48, R50, R51, R53, R54, R56, R57, R59, R60, R62, R63, R65, R66, R68, R69, R71, R72, R74, R75, R77, R78, R80, R81, R83, R84, R86, R87, R89, R90, R92, R93, R95, R96, R98, R99, R101, R102, R104, R105, R107, R108, R110, R111, R113, R114, R116, R117, R119, R120, R122, R123, R125, R126, R128, R129, R131, R132, R134, R135, R137, R138, R140, R141, R143, R144, R146, R147, R149, R150, R152, R153, R155, R156, R158, R159, R161, R162, R164, R165, R167, R168, R170, R171, R173, R174, R176, R177, R179, R180: 1K; 0603-RES
R2, R3, R7, R10, R13, R16, R19, R22, R25, R28, R31, R34, R37, R40, R43, R46, R49, R52, R55, R58, R61, R64, R67, R70, R73, R76, R79, R82, R85, R88, R91, R94, R97, R100, R103, R106, R109, R112, R115, R118, R121, R124, R127, R130, R133, R136, R139, R142, R145, R148, R151, R154, R157, R160, R163, R166, R169, R172, R175, R178: 10K; 0603-RES
TP1, TP2, TP3, TP4, TP5, TP6, TP7, TP8, TP9, TP10, TP11, TP12, TP13, TP14, TP15, TP16, TP17, TP18, TP19, TP20, TP21, TP22, TP23, TP24, TP25, TP26, TP27, TP28, TP29, TP30, TP31, TP32, TP33, TP34, TP35, TP36, TP37, TP38, TP39, TP40, TP41, TP42, TP43, TP44, TP45, TP46, TP47, TP48, TP49, TP50, TP51, TP52, TP53, TP54, TP55, TP56, TP57, TP58, TP59, TP60, TP61, TP62, TP63, TP64, TP65, TP66, TP67, TP68, TP69, TP70, TP71, TP72, TP73, TP74, TP75, TP76, TP77, TP78, TP79, TP80, TP81, TP82, TP83, TP84, TP85, TP86, TP87, TP88, TP89, TP90, TP91, TP92, TP93, TP94, TP95, TP96, TP97, TP98, TP99, TP100, TP101, TP102, TP103, TP104, TP105, TP106, TP107, TP108, TP109, TP110, TP111, TP112, TP113, TP114, TP115, TP116, TP117, TP118, TP119, TP120, TP121, TP122, TP123, TP124, TP125, TP126, TP127, TP128, TP129, TP130, TP131, TP132, TP133, TP134, TP135, TP136, TP137, TP138, TP139, TP140, TP141, TP142, TP143, TP144, TP145, TP146, TP147, TP148, TP149, TP150, TP151, TP152, TP153, TP154, TP155, TP156, TP157, TP158, TP159, TP160, TP161, TP162, TP163, TP164, TP165, TP166, TP167, TP168, TP169, TP170, TP171, TP172, TP173, TP174, TP175, TP176, TP177, TP178, TP179, TP180, TP181, TP182, TP183, TP184, TP185, TP186, TP187, TP188, TP189, TP190, TP191, TP192, TP193, TP194, TP195, TP196, TP197, TP198, TP199, TP200, TP201, TP202, TP203, TP204, TP205, TP206, TP207, TP208, TP209, TP210, TP211, TP212, TP213, TP214, TP215, TP216, TP217, TP218, TP219, TP220, TP221, TP222, TP223, TP224, TP225, TP226, TP227, TP228, TP229, TP230, TP231, TP232, TP233, TP234, TP235, TP236, TP237, TP238, TP239, TP240, TP241, TP242, TP243, TP244, TP245, TP246, TP247, TP248, TP249, TP250, TP251, TP252, TP253, TP254, TP255, TP256, TP257, TP258, TP259, TP260, TP261, TP262, TP263, TP264, TP265, TP266, TP267, TP268, TP269, TP270, TP271, TP272, TP273, TP274, TP275, TP276, TP277, TP278, TP279, TP280, TP281, TP282, TP283, TP284, TP285, TP286, TP287, TP288, TP289, TP290, TP291, TP292, TP293, TP294, TP295, TP296, TP297, TP298, TP299, TP300: TEST-POINT3; PAD.03X.03
U1, U6, U9, U12, U15, U18, U21, U24, U27, U30, U33, U36, U39, U42, U45, U48, U51, U54, U57, U60, U63, U66, U69, U72, U75, U78, U81, U84, U87, U90, U93, U96, U99, U102, U105, U108, U111, U114, U117, U120, U123, U126, U129, U132, U135, U138, U141, U144, U147, U150, U153, U156, U159, U162, U165, U168, U171, U174, U177, U180: ATMEGA328P_TQFP; TQFP32-08
U2, U4, U7, U10, U13, U16, U19, U22, U25, U28, U31, U34, U37, U40, U43, U46, U49, U52, U55, U58, U61, U64, U67, U70, U73, U76, U79, U82, U85, U88, U91, U94, U97, U100, U103, U106, U109, U112, U115, U118, U121, U124, U127, U130, U133, U136, U139, U142, U145, U148, U151, U154, U157, U160, U163, U166, U169, U172, U175, U178: 3.3V MIC5205; SOT23-5
U3, U5, U8, U11, U14, U17, U20, U23, U26, U29, U32, U35, U38, U41, U44, U47, U50, U53, U56, U59, U62, U65, U68, U71, U74, U77, U80, U83, U86, U89, U92, U95, U98, U101, U104, U107, U110, U113, U116, U119, U122, U125, U128, U131, U134, U137, U140, U143, U146, U149, U152, U155, U158, U161, U164, U167, U170, U173, U176, U179: microSD Socket; MICROSD_1:1

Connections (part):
3.3V: C1.A, C3.2, C4.1, R2.2, TP1.P$1, U1.4, U1.6, U1.18, U1.20, U2.5, U3.4
3.3V1: C5.1, C6.2, C8.A, R3.2, TP6.P$1, U4.5, U5.4, U6.4, U6.6, U6.18, U6.20
3.3V2: C9.1, C10.2, C12.A, R7.2, TP11.P$1, U7.5, U8.4, U9.4, U9.6, U9.18, U9.20
3.3V3: C13.1, C14.2, C16.A, R10.2, TP16.P$1, U10.5, U11.4, U12.4, U12.6, U12.18, U12.20
3.3V4: C17.1, C18.2, C20.A, R13.2, TP21.P$1, U13.5, U14.4, U15.4, U15.6, U15.18, U15.20
3.3V5: C21.1, C22.2, C24.A, R16.2, TP26.P$1, U16.5, U17.4, U18.4, U18.6, U18.18, U18.20
3.3V6: C25.1, C26.2, C28.A, R19.2, TP31.P$1, U19.5, U20.4, U21.4, U21.6, U21.18, U21.20
3.3V7: C29.1, C30.2, C32.A, R22.2, TP36.P$1, U22.5, U23.4, U24.4, U24.6, U24.18, U24.20
3.3V8: C33.1, C34.2, C36.A, R25.2, TP41.P$1, U25.5, U26.4, U27.4, U27.6, U27.18, U27.20
3.3V9: C37.1, C38.2, C40.A, R28.2, TP46.P$1, U28.5, U29.4, U30.4, U30.6, U30.18, U30.20
3.3V10: C41.1, C42.2, C44.A, R31.2, TP51.P$1, U31.5, U32.4, U33.4, U33.6, U33.18, U33.20
3.3V11: C45.1, C46.2, C48.A, R34.2, TP56.P$1, U34.5, U35.4, U36.4, U36.6, U36.18, U36.20
3.3V12: C49.1, C50.2, C52.A, R37.2, TP61.P$1, U37.5, U38.4, U39.4, U39.6, U39.18, U39.20
3.3V13: C53.1, C54.2, C56.A, R40.2, TP66.P$1, U40.5, U41.4, U42.4, U42.6, U42.18, U42.20
3.3V14: C57.1, C58.2, C60.A, R43.2, TP71.P$1, U43.5, U44.4, U45.4, U45.6, U45.18, U45.20
3.3V15: C61.1, C62.2, C64.A, R46.2, TP76.P$1, U46.5, U47.4, U48.4, U48.6, U48.18, U48.20
3.3V16: C65.1, C66.2, C68.A, R49.2, TP81.P$1, U49.5, U50.4, U51.4, U51.6, U51.18, U51.20
3.3V17: C69.1, C70.2, C72.A, R52.2, TP86.P$1, U52.5, U53.4, U54.4, U54.6, U54.18, U54.20
3.3V18: C73.1, C74.2, C76.A, R55.2, TP91.P$1, U55.5, U56.4, U57.4, U57.6, U57.18, U57.20
3.3V19: C77.1, C78.2, C80.A, R58.2, TP96.P$1, U58.5, U59.4, U60.4, U60.6, U60.18, U60.20
3.3V20: C81.1, C82.2, C84.A, R61.2, TP101.P$1, U61.5, U62.4, U63.4, U63.6, U63.18, U63.20
3.3V21: C85.1, C86.2, C88.A, R64.2, TP106.P$1, U64.5, U65.4, U66.4, U66.6, U66.18, U66.20
3.3V22: C89.1, C90.2, C92.A, R67.2, TP111.P$1, U67.5, U68.4, U69.4, U69.6, U69.18, U69.20
3.3V23: C93.1, C94.2, C96.A, R70.2, TP116.P$1, U70.5, U71.4, U72.4, U72.6, U72.18, U72.20
3.3V24: C97.1, C98.2, C100.A, R73.2, TP121.P$1, U73.5, U74.4, U75.4, U75.6, U75.18, U75.20
3.3V25: C101.1, C102.2, C104.A, R76.2, TP126.P$1, U76.5, U77.4, U78.4, U78.6, U78.18, U78.20
3.3V26: C105.1, C106.2, C108.A, R79.2, TP131.P$1, U79.5, U80.4, U81.4, U81.6, U81.18, U81.20
3.3V27: C109.1, C110.2, C112.A, R82.2, TP136.P$1, U82.5, U83.4, U84.4, U84.6, U84.18, U84.20
3.3V28: C113.1, C114.2, C116.A, R85.2, TP141.P$1, U85.5, U86.4, U87.4, U87.6, U87.18, U87.20
3.3V29: C117.1, C118.2, C120.A, R88.2, TP146.P$1, U88.5, U89.4, U90.4, U90.6, U90.18, U90.20
3.3V30: C121.1, C122.2, C124.A, R91.2, TP151.P$1, U91.5, U92.4, U93.4, U93.6, U93.18, U93.20
3.3V31: C125.1, C126.2, C128.A, R94.2, TP156.P$1, U94.5, U95.4, U96.4, U96.6, U96.18, U96.20
3.3V32: C129.1, C130.2, C132.A, R97.2, TP161.P$1, U97.5, U98.4, U99.4, U99.6, U99.18, U99.20
3.3V33: C133.1, C134.2, C136.A, R100.2, TP166.P$1, U100.5, U101.4, U102.4, U102.6, U102.18, U102.20
3.3V34: C137.1, C138.2, C140.A, R103.2, TP171.P$1, U103.5, U104.4, U105.4, U105.6, U105.18, U105.20
3.3V35: C141.1, C142.2, C144.A, R106.2, TP176.P$1, U106.5, U107.4, U108.4, U108.6, U108.18, U108.20
3.3V36: C145.1, C146.2, C148.A, R109.2, TP181.P$1, U109.5, U110.4, U111.4, U111.6, U111.18, U111.20
3.3V37: C149.1, C150.2, C152.A, R112.2, TP186.P$1, U112.5, U113.4, U114.4, U114.6, U114.18, U114.20
3.3V38: C153.1, C154.2, C156.A, R115.2, TP191.P$1, U115.5, U116.4, U117.4, U117.6, U117.18, U117.20
3.3V39: C157.1, C158.2, C160.A, R118.2, TP196.P$1, U118.5, U119.4, U120.4, U120.6, U120.18, U120.20
3.3V40: C161.1, C162.2, C164.A, R121.2, TP201.P$1, U121.5, U122.4, U123.4, U123.6, U123.18, U123.20
3.3V41: C165.1, C166.2, C168.A, R124.2, TP206.P$1, U124.5, U125.4, U126.4, U126.6, U126.18, U126.20
3.3V42: C169.1, C170.2, C172.A, R127.2, TP211.P$1, U127.5, U128.4, U129.4, U129.6, U129.18, U129.20
3.3V43: C173.1, C174.2, C176.A, R130.2, TP216.P$1, U130.5, U131.4, U132.4, U132.6, U132.18, U132.20
3.3V44: C177.1, C178.2, C180.A, R133.2, TP221.P$1, U133.5, U134.4, U135.4, U135.6, U135.18, U135.20
3.3V45: C181.1, C182.2, C184.A, R136.2, TP226.P$1, U136.5, U137.4, U138.4, U138.6, U138.18, U138.20
3.3V46: C185.1, C186.2, C188.A, R139.2, TP231.P$1, U139.5, U140.4, U141.4, U141.6, U141.18, U141.20
3.3V47: C189.1, C190.2, C192.A, R142.2, TP236.P$1, U142.5, U143.4, U144.4, U144.6, U144.18, U144.20
3.3V48: C193.1, C194.2, C196.A, R145.2, TP241.P$1, U145.5, U146.4, U147.4, U147.6, U147.18, U147.20
3.3V49: C197.1, C198.2, C200.A, R148.2, TP246.P$1, U148.5, U149.4, U150.4, U150.6, U150.18, U150.20
3.3V50: C201.1, C202.2, C204.A, R151.2, TP251.P$1, U151.5, U152.4, U153.4, U153.6, U153.18, U153.20
3.3V51: C205.1, C206.2, C208.A, R154.2, TP256.P$1, U154.5, U155.4, U156.4, U156.6, U156.18, U156.20
3.3V52: C209.1, C210.2, C212.A, R157.2, TP261.P$1, U157.5, U158.4, U159.4, U159.6, U159.18, U159.20
3.3V53: C213.1, C214.2, C216.A, R160.2, TP266.P$1, U160.5, U161.4, U162.4, U162.6, U162.18, U162.20
3.3V54: C217.1, C218.2, C220.A, R163.2, TP271.P$1, U163.5, U164.4, U165.4, U165.6, U165.18, U165.20
3.3V55: C221.1, C222.2, C224.A, R166.2, TP276.P$1, U166.5, U167.4, U168.4, U168.6, U168.18, U168.20
3.3V56: C225.1, C226.2, C228.A, R169.2, TP281.P$1, U169.5, U170.4, U171.4, U171.6, U171.18, U171.20
3.3V57: C229.1, C230.2, C232.A, R172.2, TP286.P$1, U172.5, U173.4, U174.4, U174.6, U174.18, U174.20
3.3V58: C233.1, C234.2, C236.A, R175.2, TP291.P$1, U175.5, U176.4, U177.4, U177.6, U177.18, U177.20
3.3V59: C237.1, C238.2, C240.A, R178.2, TP296.P$1, U178.5, U179.4, U180.4, U180.6, U180.18, U180.20
CD: U1.25, U3.CD1
CD1: U5.CD1, U6.25
CD2: U8.CD1, U9.25
CD3: U11.CD1, U12.25
CD4: U14.CD1, U15.25
CD5: U17.CD1, U18.25
CD6: U20.CD1, U21.25
CD7: U23.CD1, U24.25
CD8: U26.CD1, U27.25
CD9: U29.CD1, U30.25
CD10: U32.CD1, U33.25
CD11: U35.CD1, U36.25
CD12: U38.CD1, U39.25
CD13: U41.CD1, U42.25
CD14: U44.CD1, U45.25
CD15: U47.CD1, U48.25
CD16: U50.CD1, U51.25
CD17: U53.CD1, U54.25
CD18: U56.CD1, U57.25
CD19: U59.CD1, U60.25
CD20: U62.CD1, U63.25
CD21: U65.CD1, U66.25
CD22: U68.CD1, U69.25
CD23: U71.CD1, U72.25
CD24: U74.CD1, U75.25
CD25: U77.CD1, U78.25
CD26: U80.CD1, U81.25
CD27: U83.CD1, U84.25
CD28: U86.CD1, U87.25
CD29: U89.CD1, U90.25
CD30: U92.CD1, U93.25
CD31: U95.CD1, U96.25
CD32: U98.CD1, U99.25
CD33: U101.CD1, U102.25
CD34: U104.CD1, U105.25
CD35: U107.CD1, U108.25
CD36: U110.CD1, U111.25
CD37: U113.CD1, U114.25
CD38: U116.CD1, U117.25
CD39: U119.CD1, U120.25
CD40: U122.CD1, U123.25
CD41: U125.CD1, U126.25
CD42: U128.CD1, U129.25
CD43: U131.CD1, U132.25
CD44: U134.CD1, U135.25
CD45: U137.CD1, U138.25
CD46: U140.CD1, U141.25
CD47: U143.CD1, U144.25
CD48: U146.CD1, U147.25
CD49: U149.CD1, U150.25
CD50: U152.CD1, U153.25
CD51: U155.CD1, U156.25
CD52: U158.CD1, U159.25
CD53: U161.CD1, U162.25
CD54: U164.CD1, U165.25
CD55: U167.CD1, U168.25
CD56: U170.CD1, U171.25
CD57: U173.CD1, U174.25
CD58: U176.CD1, U177.25
CD59: U179.CD1, U180.25
CS: U1.14, U3.2
CS1: U5.2, U6.14
CS2: U8.2, U9.14
CS3: U11.2, U12.14
CS4: U14.2, U15.14
CS5: U17.2, U18.14
CS6: U20.2, U21.14
CS7: U23.2, U24.14
CS8: U26.2, U27.14
CS9: U29.2, U30.14
CS10: U32.2, U33.14
CS11: U35.2, U36.14
CS12: U38.2, U39.14
CS13: U41.2, U42.14
CS14: U44.2, U45.14
CS15: U47.2, U48.14
CS16: U50.2, U51.14
CS17: U53.2, U54.14
CS18: U56.2, U57.14
CS19: U59.2, U60.14
CS20: U62.2, U63.14
CS21: U65.2, U66.14
CS22: U68.2, U69.14
CS23: U71.2, U72.14
CS24: U74.2, U75.14
CS25: U77.2, U78.14
CS26: U80.2, U81.14
CS27: U83.2, U84.14
CS28: U86.2, U87.14
CS29: U89.2, U90.14
CS30: U92.2, U93.14
CS31: U95.2, U96.14
CS32: U98.2, U99.14
CS33: U101.2, U102.14
CS34: U104.2, U105.14
CS35: U107.2, U108.14
CS36: U110.2, U111.14
CS37: U113.2, U114.14
CS38: U116.2, U117.14
CS39: U119.2, U120.14
CS40: U122.2, U123.14
CS41: U125.2, U126.14
CS42: U128.2, U129.14
CS43: U131.2, U132.14
CS44: U134.2, U135.14
CS45: U137.2, U138.14
CS46: U140.2, U141.14
CS47: U143.2, U144.14
CS48: U146.2, U147.14
CS49: U149.2, U150.14
CS50: U152.2, U153.14
CS51: U155.2, U156.14
CS52: U158.2, U159.14
CS53: U161.2, U162.14
CS54: U164.2, U165.14
CS55: U167.2, U168.14
CS56: U170.2, U171.14
CS57: U173.2, U174.14
CS58: U176.2, U177.14
CS59: U179.2, U180.14
DTR: C2.2, JP2.6
DTR1: C7.2, JP1.6
DTR2: C11.2, JP3.6
DTR3: C15.2, JP4.6
DTR4: C19.2, JP5.6
DTR5: C23.2, JP6.6
DTR6: C27.2, JP7.6
DTR7: C31.2, JP8.6
DTR8: C35.2, JP9.6
DTR9: C39.2, JP10.6
DTR10: C43.2, JP11.6
DTR11: C47.2, JP12.6
DTR12: C51.2, JP13.6
DTR13: C55.2, JP14.6
DTR14: C59.2, JP15.6
DTR15: C63.2, JP16.6
DTR16: C67.2, JP17.6
DTR17: C71.2, JP18.6
DTR18: C75.2, JP19.6
DTR19: C79.2, JP20.6
DTR20: C83.2, JP21.6
DTR21: C87.2, JP22.6
DTR22: C91.2, JP23.6
DTR23: C95.2, JP24.6
DTR24: C99.2, JP25.6
DTR25: C103.2, JP26.6
DTR26: C107.2, JP27.6
DTR27: C111.2, JP28.6
DTR28: C115.2, JP29.6
DTR29: C119.2, JP30.6
DTR30: C123.2, JP31.6
DTR31: C127.2, JP32.6
DTR32: C131.2, JP33.6
DTR33: C135.2, JP34.6
DTR34: C139.2, JP35.6
DTR35: C143.2, JP36.6
DTR36: C147.2, JP37.6
DTR37: C151.2, JP38.6
DTR38: C155.2, JP39.6
DTR39: C159.2, JP40.6
DTR40: C163.2, JP41.6
DTR41: C167.2, JP42.6
DTR42: C171.2, JP43.6
DTR43: C175.2, JP44.6
DTR44: C179.2, JP45.6
DTR45: C183.2, JP46.6
DTR46: C187.2, JP47.6
DTR47: C191.2, JP48.6
DTR48: C195.2, JP49.6
DTR49: C199.2, JP50.6
DTR50: C203.2, JP51.6
DTR51: C207.2, JP52.6
DTR52: C211.2, JP53.6
DTR53: C215.2, JP54.6
DTR54: C219.2, JP55.6
DTR55: C223.2, JP56.6
DTR56: C227.2, JP57.6
DTR57: C231.2, JP58.6
DTR58: C235.2, JP59.6
DTR59: C239.2, JP60.6
GND: C1.K, C3.1, C4.2, D1.C, D3.C, JP2.1, JP2.2, Q1.2, U1.3, U1.5, U1.21, U2.2, U3.6, U3.GND1, U3.GND3
GND1: C5.2, C6.1, C8.K, D2.C, D4.C, JP1.1, JP1.2, Q2.2, U4.2, U5.6, U5.GND1, U5.GND3, U6.3, U6.5, U6.21
GND2: C9.2, C10.1, C12.K, D5.C, D6.C, JP3.1, JP3.2, Q3.2, U7.2, U8.6, U8.GND1, U8.GND3, U9.3, U9.5, U9.21
GND3: C13.2, C14.1, C16.K, D7.C, D8.C, JP4.1, JP4.2, Q4.2, U10.2, U11.6, U11.GND1, U11.GND3, U12.3, U12.5, U12.21
GND4: C17.2, C18.1, C20.K, D9.C, D10.C, JP5.1, JP5.2, Q5.2, U13.2, U14.6, U14.GND1, U14.GND3, U15.3, U15.5, U15.21
GND5: C21.2, C22.1, C24.K, D11.C, D12.C, JP6.1, JP6.2, Q6.2, U16.2, U17.6, U17.GND1, U17.GND3, U18.3, U18.5, U18.21
GND6: C25.2, C26.1, C28.K, D13.C, D14.C, JP7.1, JP7.2, Q7.2, U19.2, U20.6, U20.GND1, U20.GND3, U21.3, U21.5, U21.21
GND7: C29.2, C30.1, C32.K, D15.C, D16.C, JP8.1, JP8.2, Q8.2, U22.2, U23.6, U23.GND1, U23.GND3, U24.3, U24.5, U24.21
GND8: C33.2, C34.1, C36.K, D17.C, D18.C, JP9.1, JP9.2, Q9.2, U25.2, U26.6, U26.GND1, U26.GND3, U27.3, U27.5, U27.21
GND9: C37.2, C38.1, C40.K, D19.C, D20.C, JP10.1, JP10.2, Q10.2, U28.2, U29.6, U29.GND1, U29.GND3, U30.3, U30.5, U30.21
GND10: C41.2, C42.1, C44.K, D21.C, D22.C, JP11.1, JP11.2, Q11.2, U31.2, U32.6, U32.GND1, U32.GND3, U33.3, U33.5, U33.21
GND11: C45.2, C46.1, C48.K, D23.C, D24.C, JP12.1, JP12.2, Q12.2, U34.2, U35.6, U35.GND1, U35.GND3, U36.3, U36.5, U36.21
GND12: C49.2, C50.1, C52.K, D25.C, D26.C, JP13.1, JP13.2, Q13.2, U37.2, U38.6, U38.GND1, U38.GND3, U39.3, U39.5, U39.21
GND13: C53.2, C54.1, C56.K, D27.C, D28.C, JP14.1, JP14.2, Q14.2, U40.2, U41.6, U41.GND1, U41.GND3, U42.3, U42.5, U42.21
GND14: C57.2, C58.1, C60.K, D29.C, D30.C, JP15.1, JP15.2, Q15.2, U43.2, U44.6, U44.GND1, U44.GND3, U45.3, U45.5, U45.21
GND15: C61.2, C62.1, C64.K, D31.C, D32.C, JP16.1, JP16.2, Q16.2, U46.2, U47.6, U47.GND1, U47.GND3, U48.3, U48.5, U48.21
GND16: C65.2, C66.1, C68.K, D33.C, D34.C, JP17.1, JP17.2, Q17.2, U49.2, U50.6, U50.GND1, U50.GND3, U51.3, U51.5, U51.21
GND17: C69.2, C70.1, C72.K, D35.C, D36.C, JP18.1, JP18.2, Q18.2, U52.2, U53.6, U53.GND1, U53.GND3, U54.3, U54.5, U54.21
GND18: C73.2, C74.1, C76.K, D37.C, D38.C, JP19.1, JP19.2, Q19.2, U55.2, U56.6, U56.GND1, U56.GND3, U57.3, U57.5, U57.21
GND19: C77.2, C78.1, C80.K, D39.C, D40.C, JP20.1, JP20.2, Q20.2, U58.2, U59.6, U59.GND1, U59.GND3, U60.3, U60.5, U60.21
GND20: C81.2, C82.1, C84.K, D41.C, D42.C, JP21.1, JP21.2, Q21.2, U61.2, U62.6, U62.GND1, U62.GND3, U63.3, U63.5, U63.21
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

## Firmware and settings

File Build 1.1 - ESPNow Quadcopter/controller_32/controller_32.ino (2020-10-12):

//############################################################################//
//                          ESPNOW Declarations                               //
//############################################################################//

#include <esp_now.h>
#include <WiFi.h>

#define txInterval 50 //ms
#define timeout 200   //ms

#define thr_pin 39
#define yaw_pin 36
#define rol_pin 34
#define pit_pin 35
#define aux0_pin 15
#define aux1_pin 4

#define pair_indicator 13

#define thr_offset 50
#define yaw_offset 45
#define rol_offset 53
#define pit_offset 68

#define verbose_enabled false

uint8_t drone_address[] = {0xCC, 0x50, 0xE3, 0x3C, 0xAD, 0x13};
uint8_t drone1_address[] = {0x5C, 0xCF, 0x7F, 0xB7, 0x22, 0x8E};
uint8_t drone2_address[] = {0x84, 0xF3, 0xEB, 0x5A, 0x73, 0xA2};
uint8_t drone3_address[] = {0xBC, 0xDD, 0xC2, 0x2B, 0x0E, 0x98};
uint8_t station_address[] = {0x80, 0x7D, 0x3A, 0xB7, 0x81, 0x54};

unsigned long beginTime;
unsigned long currentTime;
unsigned long lastTime = 0; //transmission timer
unsigned long lastReceived; //successful receive timer
unsigned long lastSent;     //successful transmit timer


//############################################################################//
//                            ESPNOW Functions                                //
//############################################################################//

// Receive data structure
typedef struct drone_message {
  bool conn_stat;
  float battery;
  uint8_t local_time[2];
} drone_message;


// Send data structure
typedef struct command_message {
  bool conn_stat;
  int thr;
  int rol;
  int pit;
  int yaw;
  int aux[4];
  uint8_t local_time[2];
} command_message;


bool compare_address(uint8_t* add1, const unsigned char* add2)
{
  for (int i = 0; i < 6; i++)
    if (add1[i] != add2[i])
      return false;
  return true;
}

void print_address(uint8_t* add) {
  for (int i = 0; i < 6; i++) {
    Serial.print(add[i], HEX);
    Serial.print(" ");
  }
}

class Drone_Handler {
  public:
    uint8_t address[6];  // RECEIVER MAC Address
    drone_message droneData;
    command_message commandData;
    esp_now_peer_info_t peerInfo;
    boolean connection_status = false;

    Drone_Handler() {
    }

    void begin(uint8_t* droneAddress) {
      memcpy(address, droneAddress, 6);
      memcpy(peerInfo.peer_addr, address, 6); //register peer
      peerInfo.channel = 0;
      peerInfo.encrypt = false;

      if (verbose_enabled) print_address(droneAddress);
      if (esp_now_add_peer(&peerInfo) != ESP_OK) {
        if (verbose_enabled) Serial.println(" peer registration failure\n");
      }
      else {
        if (verbose_enabled) Serial.println(" peer registration success\n");
        connection_status = true;
      }

    }

    void transmit() {
      esp_now_send(address, (uint8_t *) &commandData, sizeof(commandData));
    }

    void transmit_command(command_message* inputCommand) {
      memcpy(&commandData, inputCommand, sizeof(commandData));

      esp_now_send(address, (uint8_t *) &commandData, sizeof(commandData));
    }

    void receive(const unsigned char* incomingData) {
      memcpy(&droneData, incomingData, sizeof(droneData));
    }

    void print_droneData() {
      Serial.print("Drone connection: "); Serial.print(droneData.conn_stat);
      Serial.print(" bat "); Serial.print(droneData.battery);
      Serial.print(" min "); Serial.print(droneData.local_time[0]);
      Serial.print(" sec "); Serial.println(droneData.local_time[1]);
    }

    void print_commandData() {
      Serial.print("Station connection: "); Serial.print(commandData.conn_stat);
      Serial.print(" THR "); Serial.print(commandData.thr);
      Serial.print(" ROL "); Serial.print(commandData.rol);
      Serial.print(" PIT "); Serial.print(commandData.pit);
      Serial.print(" YAW "); Serial.print(commandData.yaw);
      Serial.print(" AU0 "); Serial.print(commandData.aux[0]);
      Serial.print(" AU1 "); Serial.print(commandData.aux[1]);
      Serial.print(" min "); Serial.print(commandData.local_time[0]);
      Serial.print(" sec "); Serial.println(commandData.local_time[1]);
    }
};

Drone_Handler drone;

// Callback when data is sent
void OnDataSent(const uint8_t *mac_addr, esp_now_send_status_t status) {

  if (status != ESP_NOW_SEND_SUCCESS) {
    if (verbose_enabled) Serial.println("Delivery fail");
  }
  else {
    lastSent = millis();
    if (verbose_enabled) {
      Serial.print("Data successfully sent to :");
      print_address((uint8_t*)mac_addr);
      Serial.println("\n");
    }
  }

}

// Callback function that will be executed when data is received
void OnDataRecv(const unsigned char* mac, const unsigned char* incomingData, int len) {

  bool recognized = false;

  if (verbose_enabled) {
    Serial.print("Msg Source: ");
    print_address((uint8_t*)mac);
  }

  if (compare_address(drone.address, mac)) {
    lastReceived = millis();
    drone.receive(incomingData);

    if (verbose_enabled) Serial.println("Recognized as registered drone");

    recognized = true;
  }

  if (!recognized && verbose_enabled) Serial.println("Unrecognized drone\n");
}

void espnow32_begin() {

  WiFi.mode(WIFI_STA);  // Set device as a Wi-Fi Station

  if (esp_now_init() != ESP_OK) {
    if (verbose_enabled) Serial.println("Error initializing ESP-NOW");
    return;
  }

  // Once ESPNow is successfully Init, we will register for
  esp_now_register_send_cb(OnDataSent);  // sendCB to get the status of Trasnmitted packet
  esp_now_register_recv_cb(OnDataRecv);  // recvCB to get recv packer info

  drone.begin(drone_address);

}

//############################################################################//
//                            Helper Functions                                //
//############################################################################//


void joystick_begin() {
  pinMode(thr_pin, INPUT);
  pinMode(yaw_pin, INPUT);
  pinMode(yaw_pin, INPUT);
  pinMode(rol_pin, INPUT);
  pinMode(aux0_pin, INPUT);
  pinMode(aux1_pin, INPUT);

  pinMode(pair_indicator, OUTPUT);
}

void joystick_routine(bool feedback_enabled) {
  drone.commandData.thr = map(analogRead(thr_pin), 0, 4095, 2000, 1000) - thr_offset;
  drone.commandData.rol = map(analogRead(rol_pin), 0, 4095, 2000, 1000) - rol_offset;
  drone.commandData.pit = map(analogRead(pit_pin), 0, 4095, 2000, 1000) - pit_offset;
  drone.commandData.yaw = map(analogRead(yaw_pin), 0, 4095, 2000, 1000) - yaw_offset;

  drone.commandData.aux[0] = !digitalRead(aux0_pin) ? !drone.commandData.aux[0] : drone.commandData.aux[0];
  drone.commandData.aux[1] = !digitalRead(aux1_pin) ? !drone.commandData.aux[1] : drone.commandData.aux[1];

  drone.commandData.local_time[0] = floor(((currentTime - beginTime) / 1000) / 60.0);
  drone.commandData.local_time[1] = ((currentTime - beginTime) / 1000) % 60;

  if (feedback_enabled) {
    Serial.println("\nTransmitter");
    drone.print_commandData();
    drone.print_droneData();
  }

  drone.transmit();
}

//############################################################################//
//                            Setup and Loop                                  //
//############################################################################//

void setup() {

  beginTime = millis();
  Serial.begin(115200);
  Serial.print("\n\n\n\n\n");

  espnow32_begin();
  joystick_begin();
}


void loop() {

  currentTime = millis();

  if ((currentTime - lastReceived) > timeout || (currentTime - lastSent) > timeout) {
    drone.commandData.conn_stat = false;
    digitalWrite(pair_indicator, LOW);
  }
  else {
    drone.commandData.conn_stat = true;
    digitalWrite(pair_indicator, HIGH);
  }

  if ((currentTime - lastTime) > txInterval) {
    joystick_routine(false);
    lastTime = currentTime;
  }
}

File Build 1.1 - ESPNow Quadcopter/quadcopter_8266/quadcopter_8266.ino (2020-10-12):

//############################################################################//
//                          PPM Declarations                                  //
//############################################################################//

#define CPU_MHZ 80
#define CHANNEL_NUMBER 8  //set the number of chanels
#define CHANNEL_DEFAULT_VALUE 1100  //set the default servo value
#define FRAME_LENGTH 22500  //set the PPM frame length in microseconds (1ms = 1000µs)
#define PULSE_LENGTH 300  //set the pulse length
#define onState 0  //set polarity of the pulses: 1 is positive, 0 is negative
#define sigPin 5 //set PPM signal output pin on the arduino

int ppm[CHANNEL_NUMBER];

#define THR 1
#define ROL 2
#define PIT 3
#define YAW 0
#define AUX1 4
#define AUX2 5
#define AUX3 6
#define AUX4 7

volatile unsigned long next;
volatile unsigned int ppm_running = 1;

void ppmISR(void) {
  static boolean state = true;

  if (state) {  //start pulse
    digitalWrite(sigPin, onState);
    next = next + (PULSE_LENGTH * CPU_MHZ);
    state = false;
  }
  else { //end pulse and calculate when to start the next pulse
    static byte cur_chan_numb;
    static unsigned int calc_rest;

    digitalWrite(sigPin, !onState);
    state = true;

    if (cur_chan_numb >= CHANNEL_NUMBER) {
      cur_chan_numb = 0;
      calc_rest = calc_rest + PULSE_LENGTH;//
      next = next + ((FRAME_LENGTH - calc_rest) * CPU_MHZ);
      calc_rest = 0;
    }
    else {
      next = next + ((ppm[cur_chan_numb] - PULSE_LENGTH) * CPU_MHZ);
      calc_rest = calc_rest + ppm[cur_chan_numb];
      cur_chan_numb++;
    }
  }
  timer0_write(next);
}

void ppm_begin(void) {
  pinMode(sigPin, OUTPUT);
  digitalWrite(sigPin, !onState); //set the PPM signal pin to the default state (off)

  noInterrupts();
  timer0_isr_init();
  timer0_attachInterrupt(ppmISR);
  next = ESP.getCycleCount() + 1000;
  timer0_write(next);
  for (int i = 0; i < CHANNEL_NUMBER; i++) {
    ppm[i] = CHANNEL_DEFAULT_VALUE;
  }
  interrupts();
}

//############################################################################//
//                          ESPNOW Declarations                               //
//############################################################################//

#include <ESP8266WiFi.h>
#include <espnow.h>

#define txInterval 50 //ms
#define timeout 200   //ms

#define verbose_enabled false

uint8_t drone_address[] = {0xCC, 0x50, 0xE3, 0x3C, 0xAD, 0x13};
uint8_t drone1_address[] = {0x5C, 0xCF, 0x7F, 0xB7, 0x22, 0x8E};
uint8_t drone2_address[] = {0x84, 0xF3, 0xEB, 0x5A, 0x73, 0xA2};
uint8_t drone3_address[] = {0xBC, 0xDD, 0xC2, 0x2B, 0x0E, 0x98};
uint8_t station_address[] = {0x80, 0x7D, 0x3A, 0xB7, 0x81, 0x54};


// Send data structure
typedef struct drone_message {
  bool conn_stat;
  float battery;
  uint8_t local_time[2];
} drone_message;


// Receive data structure
typedef struct command_message {
  bool conn_stat;
  int thr;
  int rol;
  int pit;
  int yaw;
  int aux[4];
  uint8_t local_time[2];
} command_message;


bool compare_address(uint8_t* add1, uint8_t* add2)
{
  for (int i = 0; i < 6; i++)
    if (add1[i] != add2[i])
      return false;
  return true;
}

void print_address(uint8_t* add) {
  for (int i = 0; i < 6; i++) {
    Serial.print(add[i], HEX);
    Serial.print(" ");
  }
}

class Station_Handler {
  public:
    uint8_t address[6];  // station MAC Address
    drone_message droneData;
    command_message commandData;
    boolean connection_status = false;

    Station_Handler() {
    }

    void begin(uint8_t* stationAddress) {
      memcpy(address, stationAddress, 6);
      esp_now_add_peer(address, ESP_NOW_ROLE_CONTROLLER, 1, NULL, 0);
      if (verbose_enabled) {
        print_address(stationAddress);
        Serial.println(" ");
      }
    }

    void transmit() {
      esp_now_send(address, (uint8_t *) &droneData, sizeof(droneData));
    }

    void receive(const unsigned char* incomingData) {
      memcpy(&commandData, incomingData, sizeof(commandData));

    }

    void print_droneData() {
      Serial.print("Drone connection: "); Serial.print(droneData.conn_stat);
      Serial.print(" bat "); Serial.print(droneData.battery);
      Serial.print(" min "); Serial.print(droneData.local_time[0]);
      Serial.print(" sec "); Serial.println(droneData.local_time[1]);
    }

    void print_commandData() {
      Serial.print("Station connection: "); Serial.print(commandData.conn_stat);
      Serial.print(" THR "); Serial.print(commandData.thr);
      Serial.print(" ROL "); Serial.print(commandData.rol);
      Serial.print(" PIT "); Serial.print(commandData.pit);
      Serial.print(" YAW "); Serial.print(commandData.yaw);
      Serial.print(" AU0 "); Serial.print(commandData.aux[0]);
      Serial.print(" AU1 "); Serial.print(commandData.aux[1]);
      Serial.print(" min "); Serial.print(commandData.local_time[0]);
      Serial.print(" sec "); Serial.println(commandData.local_time[1]);
    }
};


Station_Handler st;


unsigned long beginTime;
unsigned long currentTime;
unsigned long lastTime = 0; //transmission timer
unsigned long lastReceived; //successful receive timer
unsigned long lastSent;     //successful transmit timer

// Callback when data is sent
void OnDataSent(uint8_t *mac_addr, uint8_t sendStatus) {


  if (sendStatus != 0) {
    if (verbose_enabled) Serial.println("Delivery fail");
  }
  else {
    lastSent = millis();
    if (verbose_enabled) {
      Serial.print("Data successfully sent to :");
      print_address((uint8_t*)mac_addr);
      Serial.println("\n");
    }
  }

}

// Callback function that will be executed when data is received
void OnDataRecv(uint8_t * mac, uint8_t *incomingData, uint8_t len) {

  bool recognized = false;

  if (verbose_enabled) {
    Serial.print("Msg Source: ");
    print_address(mac);
  }

  if (compare_address(st.address, mac)) {
    lastReceived = millis();
    st.receive(incomingData);

    if (verbose_enabled) Serial.println("Recognized as registered station");

    recognized = true;
  }

  if (!recognized && verbose_enabled) Serial.println("Unrecognized source\n");
}

void espnow8266_begin() {

  WiFi.mode(WIFI_STA);  // Set device as a Wi-Fi Station

  if (esp_now_init() != 0) {
    if (verbose_enabled) Serial.println("Error initializing ESP-NOW");
    return;
  }

  // Once ESPNow is successfully Init, we will register for
  esp_now_set_self_role(ESP_NOW_ROLE_CONTROLLER);
  esp_now_register_send_cb(OnDataSent);  // sendCB to get the status of Trasnmitted packet
  esp_now_register_recv_cb(OnDataRecv);  // recvCB to get recv packer info

  st.begin(station_address);
}

//############################################################################//
//                            Helper Functions                                //
//############################################################################//
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

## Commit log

2020-05-22 Uploaded previous work
    [65mm Press-Fit Prop.SLDPRT, 65mm Press-Fit Prop.SLDPRT.urdf, 65mm Press-Fit Prop.step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]
2020-09-02 Successful build 1
    [65mm Press-Fit Prop.SLDPRT, 65mm Press-Fit Prop.SLDPRT.urdf, 65mm Press-Fit Prop.step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]
2020-09-09 added documentation
    [OpenLog.brd, OpenLog.sch, OpenLog_Panel_v15.brd]
2020-09-12 espcopter codes
    [OpenLog.brd, OpenLog.sch, OpenLog_Panel_v15.brd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]
2020-09-19 started custom FC code for esp32
2020-09-22 orientation 1 done, RTIMULib started
    [OpenLog.brd, OpenLog.sch, OpenLog_Panel_v15.brd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]
2020-09-27 PPM code now on both esp8266 and esp32
2020-10-03 started vrep simulation
    [65mm Press-Fit Prop.SLDPRT, 65mm Press-Fit Prop.SLDPRT.urdf, 65mm Press-Fit Prop.step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]

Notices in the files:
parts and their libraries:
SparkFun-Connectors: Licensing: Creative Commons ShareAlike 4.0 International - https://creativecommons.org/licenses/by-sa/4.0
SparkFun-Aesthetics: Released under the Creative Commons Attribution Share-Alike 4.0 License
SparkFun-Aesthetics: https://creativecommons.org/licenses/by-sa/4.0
